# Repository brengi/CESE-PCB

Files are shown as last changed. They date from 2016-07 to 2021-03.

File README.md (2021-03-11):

# DCI- Curso de Diseño de Circuitos Impresos de la Carrera de Especialización en Sistemas Embebidos #

El Curso de Diseño de Circuitos Impresos (DCI) es una asignatura optativa de la Carrera de Especialización en Sistemas Embebidos (CESE) de la Facultad de Ingeniería de la Universidad de Buenos Aires (FIUBA). Tiene una duración de dos meses, organizados en 8 clases semanales de 3 hs cada una. Para aprobar la asignatura los participantes deben realizar el diseño de un circuito impreso a elección durante el curso. En esta página quedan registradas  dichas prácticas.

Más info sobre el curso en las siguiente páginas: 
  * [Contenido y Bibliografía](https://sites.google.com/site/disenodecircuitosimpresoscese/home)
  * [Campus FIUBA](https://campus.fi.uba.ar/enrol/index.php?id=1450])

**ADVERTENCIA**: Estos diseños se realizan en tiempos muy cortos y no todos reciben una revisión funcional detallada. 
El curso enfoca el los procedimientos de diseño de Esquemático y de PCB y no en el diseño funcional de los  circuitos.
El uso de estos circuitos queda bajo la propia responsabilidad del usuario. 

   * [CURSO 2020 B](README_2020B.md#curso-2020-b)
      * [Sistema Monitoreo Alarma de Incendio](README_2020B.md#sistema-monitoreo-alarma-de-incendio)
      * [Réplica dc motor control](README_2020B.md#réplica-dc-motor-control)
      * [Titulador automático](README_2020B.md#titulador-automático)
      * [Board_NFC (Replica sin antena)](README_2020B.md#board_nfc-replica-sin-antena)
      * [Poncho TCP/IP](README_2020B.md#poncho-tcpip)
      * [Replica ESP01 (Mejorada)](README_2020B.md#replica-esp01-mejorada)
      * [Driver motor PAP y ADC](README_2020B.md#driver-motor-pap-y-adc)
      * [Helctec LoRa con cambios](README_2020B.md#helctec-lora-con-cambios)
      * [Réplica pro micro sparkfun (similar)](README_2020B.md#réplica-pro-micro-sparkfun-similar)
      * [Conversor de niveles lógicos](README_2020B.md#conversor-de-niveles-lógicos)
      * [Réplica Sparkfun VS1063](README_2020B.md#réplica-sparkfun-vs1063)
      * [Módulo de velocidad tacométrico](README_2020B.md#módulo-de-velocidad-tacométrico)
      * [Réplica Arduino nano 340g 2016](README_2020B.md#réplica-arduino-nano-340g-2016)
      * [Beacon basado en DWM1001 (Réplica simplificada)](README_2020B.md#beacon-basado-en-dwm1001-réplica-simplificada)
      * [Réplica Pinguino PIC](README_2020B.md#réplica-pinguino-pic)
      * [Réplica detección de obstáculos por infrarrojo](README_2020B.md#réplica-detección-de-obstáculos-por-infrarrojo)
      * [Replica Adafruit HUZZAH32 - ESP32 Feather](README_2020B.md#replica-adafruit-huzzah32---esp32-feather)
      * [Poncho interfaz   arreglo sensores  IR](README_2020B.md#poncho-interfaz--arreglo-sensores--ir)
      * [Programador de microcontroladores](README_2020B.md#programador-de-microcontroladores)

   * [CURSO 2020 A](README_2020A.md#curso-2020-a)
      * [Escáner Magnético de Soldaduras](README_2020A.md#escáner-magnético-de-soldaduras)
      * [Replica Acelerómetro adxl345](README_2020A.md#replica-acelerómetro-adxl345)
      * [Monitor de medidores de energía eléctrica](README_2020A.md#monitor-de-medidores-de-energía-eléctrica)
      * [Réplica  modificada Heltec Wifi LoRA V2](README_2020A.md#réplica--modificada-heltec-wifi-lora-v2)
      * [Réplica Teensy 3.2](README_2020A.md#réplica-teensy-32)
      * [Poncho fotovoltaico](README_2020A.md#poncho-fotovoltaico)
      * [Módem Energy meter](README_2020A.md#módem-energy-meter)
      * [Poncho EDU-CIAA Drivers](README_2020A.md#poncho-edu-ciaa-drivers)

   * [CURSO 6  - 2019](README_2019.md#curso-6----2019)
      * [Punku, control de accesos](README_2019.md#punku-control-de-accesos)
      * [Cargador de batería con protección](README_2019.md#cargador-de-batería-con-protección)
      * [Replica EasyDriver v4.5](README_2019.md#replica-easydriver-v45)
      * [Poncho PLC CIAA 7](README_2019.md#poncho-plc-ciaa-7)
      * [Placa adaptadora de señales de radar](README_2019.md#placa-adaptadora-de-señales-de-radar)
      * [Driver I2C de leds RGB](README_2019.md#driver-i2c-de-leds-rgb)
      * [Encoder &amp; Driver PaP](README_2019.md#encoder--driver-pap)
      * [Dip Coater](README_2019.md#dip-coater)
      * [Driver motor CC](README_2019.md#driver-motor-cc)
      * [Controlador de motor con sensor](README_2019.md#controlador-de-motor-con-sensor)
      * [Placa Bridge Ethernet](README_2019.md#placa-bridge-ethernet)
      * [Fuente Step Up DC-DC ajustable 5v-35v](README_2019.md#fuente-step-up-dc-dc-ajustable-5v-35v)
   * [CURSO 5  - 2019](README_2019.md#curso-5----2019)
      * [Controlador de solenoides realimentado](README_2019.md#controlador-de-solenoides-realimentado)
      * [Módulo ESP8266 - nodeMCU](README_2019.md#módulo-esp8266---nodemcu)
      * [Amplificador biológico educativo](README_2019.md#amplificador-biológico-educativo)
      * [RS485 Port KP995](README_2019.md#rs485-port-kp995)
      * [Sistema de Monitoreo de Material Rodante](README_2019.md#sistema-de-monitoreo-de-material-rodante)
      * [Replica mejorada ESP32 Thing](README_2019.md#replica-mejorada-esp32-thing)
      * [Kit desarrollo para microcontrolador pic16f1939](README_2019.md#kit-desarrollo-para-microcontrolador-pic16f1939)
      * [Placa de desarrollo basado en una FPGA Libre](README_2019.md#placa-de-desarrollo-basado-en-una-fpga-libre)
      * [Poncho adaptador Arduino Mega2560](README_2019.md#poncho-adaptador-arduino-mega2560)
      * [Custom Raspberry Compute Module IO Board](README_2019.md#custom-raspberry-compute-module-io-board)
      * [Réplica TTGO-LORA32-V2.0](README_2019.md#réplica-ttgo-lora32-v20)

   * [CURSO 4  - 2018](README_2018.md#curso-4----2018)
      * [Driver motor pap](README_2018.md#driver-motor-pap)
      * [CIAA-UNO](README_2018.md#ciaa-uno)
      * [Poncho multimedia](README_2018.md#poncho-multimedia)
      * [Puente H doble de 20A](README_2018.md#puente-h-doble-de-20a)
      * [Poncho Alarma](README_2018.md#poncho-alarma)
      * [Réplica del modulo 8 reles de arduino](README_2018.md#réplica-del-modulo-8-reles-de-arduino)
      * [Réplica Acelerometro-mma7361](README_2018.md#réplica-acelerometro-mma7361)
      * [Nodo SisCoCaf](README_2018.md#nodo-siscocaf)
      * [VOIP Shield para Nucleo F767](README_2018.md#voip-shield-para-nucleo-f767)
      * [Poncho CAN](README_2018.md#poncho-can)
      * [Papilio DUO](README_2018.md#papilio-duo)
      * [Detector de sonido arduino](README_2018.md#detector-de-sonido-arduino)
      * [Extension de tarjeta HCAL](README_2018.md#extension-de-tarjeta-hcal)
      * [Contador de pasajeros](README_2018.md#contador-de-pasajeros)
      * [Prototipo Equipo AVL](README_2018.md#prototipo-equipo-avl)
      * [Electrodo Activo para Electromiografía](README_2018.md#electrodo-activo-para-electromiografía)
      * [Replica Placa Madre WEMB01](README_2018.md#replica-placa-madre-wemb01)
      * [Sistema de intercambio de mensajes de voz](README_2018.md#sistema-de-intercambio-de-mensajes-de-voz)
      * [VOP24](README_2018.md#vop24)
      * [PCB para alarma IoT](README_2018.md#pcb-para-alarma-iot)
      * [Modulo TPMS sensor](README_2018.md#modulo-tpms-sensor)
      * [Poncho Procesador de Audio](README_2018.md#poncho-procesador-de-audio)
      * [wifi ESP-01 con relés optoacoplados](README_2018.md#wifi-esp-01-con-relés-optoacoplados)

   * [CURSO 3  - 2017](README_2017.md#curso-3----2017)
      * [Poncho  MIDI](README_2017.md#poncho--midi)
      * [Poncho  Poncho WIFI BLUETOOTH ESP-WROOM-32](README_2017.md#poncho--poncho-wifi-bluetooth-esp-wroom-32)
      * [Poncho  Expansor de Puertos](README_2017.md#poncho--expansor-de-puertos)
      * [Poncho Control de temperatura](README_2017.md#poncho-control-de-temperatura)
      * [Poncho Joystick](README_2017.md#poncho-joystick)
      * [Poncho Medición de pH](README_2017.md#poncho-medición-de-ph)
      * [Poncho  RF](README_2017.md#poncho--rf)
      * [PicoPoncho Lora](README_2017.md#picoponcho-lora)
      * [Poncho Educativo Modelo 2](README_2017.md#poncho-educativo-modelo-2)
      * [Poncho USB-XBEE](README_2017.md#poncho-usb-xbee)
      * [PicoPoncho Bluetooth HC05](README_2017.md#picoponcho-bluetooth-hc05)
      * [Poncho  LCD y Botones](README_2017.md#poncho--lcd-y-botones)

   * [CURSO 2  - 2016](README_2016.md#curso-2----2016)
      * [PicoPoncho WiFi](README_2016.md#picoponcho-wifi)
      * [Poncho  Educativo](README_2016.md#poncho--educativo)
      * [Poncho IoT](README_2016.md#poncho-iot)
      * [Poncho  SAEv2](README_2016.md#poncho--saev2)
      * [Poncho  Puente H por i2C](README_2016.md#poncho--puente-h-por-i2c)
      * [Poncho Oxímetro](README_2016.md#poncho-oxímetro)
      * [Placa Educativa de la materia Electrónica Gral.](README_2016.md#placa-educativa-de-la-materia-electrónica-gral)
      * [Placa de desarrollo para LPC1114](README_2016.md#placa-de-desarrollo-para-lpc1114)
      * [Placa Control Vino](README_2016.md#placa-control-vino)
      * [PMOD Medidor de impedancia para FPGA](README_2016.md#pmod-medidor-de-impedancia-para-fpga)
      * [Poncho EDU-CIAA-NXP RF 2.4GHz Antena PCB](README_2016.md#poncho-edu-ciaa-nxp-rf-24ghz-antena-pcb)
      * [Poncho CNC](README_2016.md#poncho-cnc)
   * [CURSO 1  - 2016](README_2016.md#curso-1----2016)
      * [Poncho Celda de Carga](README_2016.md#poncho-celda-de-carga)
      * [Poncho Osciloscopio](README_2016.md#poncho-osciloscopio)
      * [Poncho Simon](README_2016.md#poncho-simon)
      * [Poncho Audio](README_2016.md#poncho-audio)
      * [Poncho Detector de Caídas](README_2016.md#poncho-detector-de-caídas)
      * [Poncho ECG](README_2016.md#poncho-ecg)
      * [Poncho L298](README_2016.md#poncho-l298)
      * [Poncho Misión SAE](README_2016.md#poncho-misión-sae)
      * [AislacionUSB](README_2016.md#aislacionusb)
      * [Proyecto MICR](README_2016.md#proyecto-micr)
      * [Proyecto Modular Drummer](README_2016.md#proyecto-modular-drummer)

Created by [gh-md-toc](https://github.com/ekalinin/github-markdown-toc)

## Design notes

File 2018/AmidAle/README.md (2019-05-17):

# CESE18_PCB_Amid_Ale
Trabajo final de la asignatura Diseño de PCB de la CESE

** Principales Características:**

1. Salidas a Relay (2)
2. Entradas Optoacopladas (4)
4. (RS232) ESP8266 (1)
5. Display 16x2 (1)

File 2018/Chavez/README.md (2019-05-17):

# PCB
Diseño de PCBs

Replica acelerometro-mma7361

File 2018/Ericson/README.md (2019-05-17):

# Rev 1.0

Primera entrega para revision.

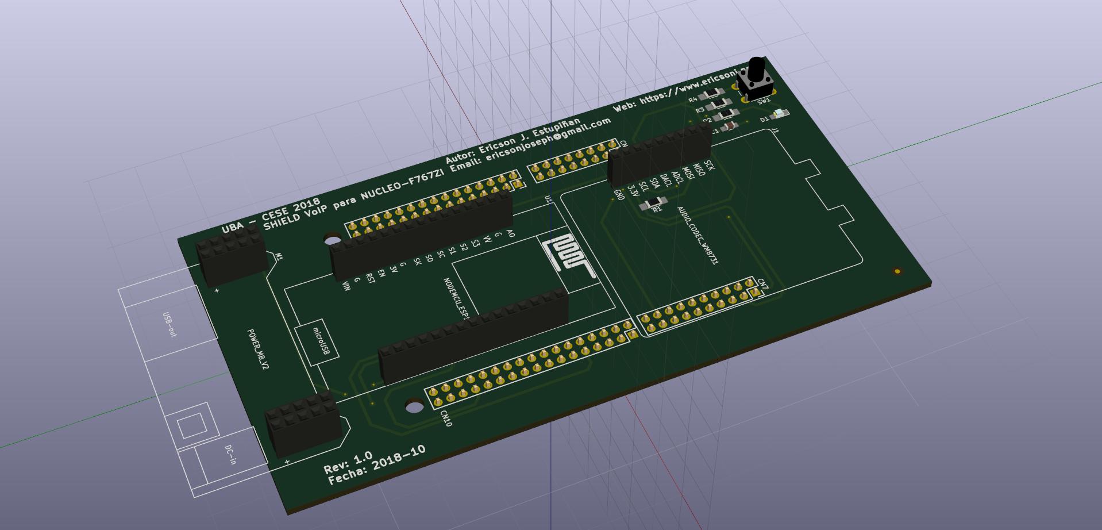
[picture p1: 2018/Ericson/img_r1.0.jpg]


# Progreso

## Imagen 1
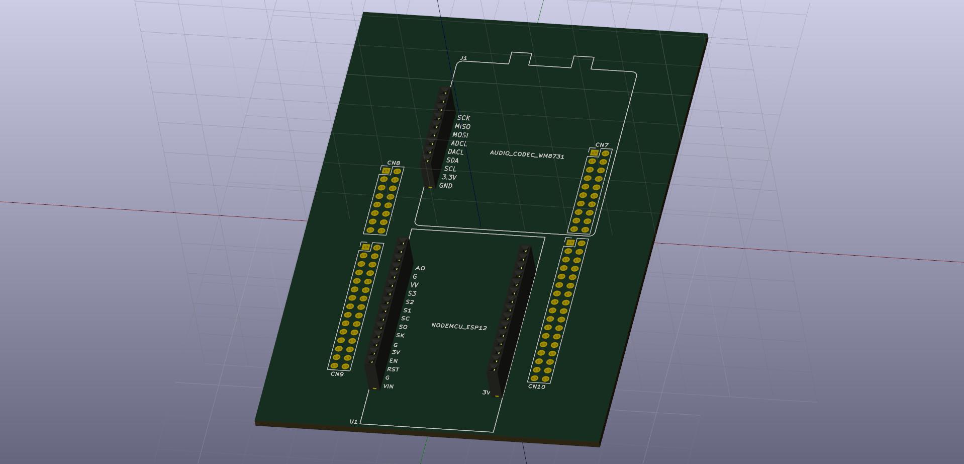
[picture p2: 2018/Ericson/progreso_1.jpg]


## Imagen 2
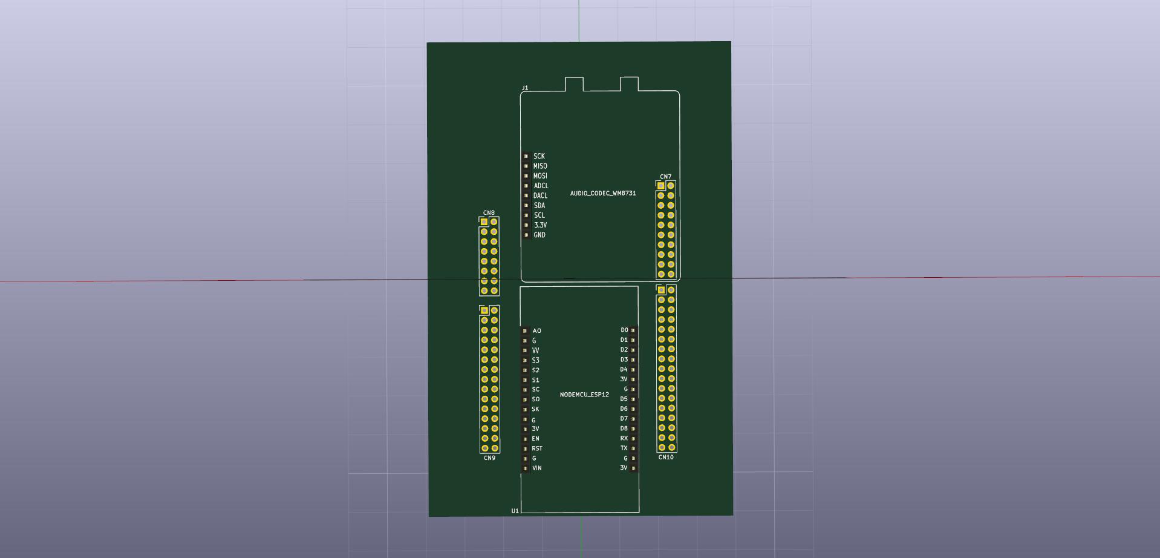
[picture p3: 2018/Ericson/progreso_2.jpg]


# CESE2018-PCB-TP
CESE 2018 Diseño de Circuitos Impresos,

Repositorio del trabajo final del curso de Diseño de Circuitos Impresos 
de la carrera Especializacion en Sistemas embebidos. 

## Introduccion 

El siguiente proyecto busca ser un adicional al trabajo final de la carrera de especialización en sistemas embebidos
"Diseño e implementación de un sistema de comunicación VoIP usando una plataforma ARM Cortex M7**. El proyecto propone el diseño de un sheild compatible con los conectores Arduino UNO y que conecte e integra los módulos necesarios para el desarrollo del proyecto final de carrera. Estos módulos son: 

1.  AUDIO CODEC WM8731.
2.  ESP-12. 
3.  Fuente DC. 

## Objetivos

*  Diseñar un circuito impreso en Kicad que conecte los diferentes modulos de forma apropiada.

## Alcances

*  Diseño de circuito impreso.

## Posibles alcances

*  Manufactura del cicuito impreso.

## Plan de trabajo

1.  Diseño de plataforma que por medio de conectores integra en una misma placa cada modulo.
2.  Primera versión del diseño de la PCB.
3.  **Búsqueda de esquemático de modulo NODE MCU para extraer ESP-12 e integrarlo en el diseño del circuito.
4.  **Segunda versión del diseño de la PCB.
5.  **Búsqueda de esquemático de Fuente DC para integración en el circuito impreso.
6.  **Tercera versión del diseño de la PCB.
7.  **Búsqueda de esquemático de AUDIO CODEC WM8131 para integración en el circuito impreso.
8.  **Cuarta versión del diseño de la PCB.

**Posibles versiones del proyecto si alcanza el tiempo estimado. 

## Prototipo



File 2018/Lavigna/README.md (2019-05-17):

# CESE-2018-disenio-pcb-gonzalo-lavigna
Repositorio de la materia de Diseño de PCB de Gonzalo Lavigna CESE 2018

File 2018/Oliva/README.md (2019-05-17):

# CESE2018_6Co_DPCBs
TRABAJOS MATERIA DISEÑO DE PCBs - CESE 2018 DE R.OLIVA

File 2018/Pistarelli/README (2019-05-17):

El PCB ha sido desarrollado en el marco de la realización del prototipo funcional de proyecto:

https://docs.google.com/document/d/1OangFb6ORAsVZ08jJLUIxbCAcYfww7F53GZTul6QJPM/edit?usp=sharing

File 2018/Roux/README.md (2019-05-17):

# VOP24_LPCXpresso1769_baseHW #

### autor: Ing. Roux Federico G. (rouxfederico@gmail.com) ###

Desarrollo en KICAD del hardware base para LPCXpresso1769 con los componentes básicos:

	- regulación de tensión digital y analógica.
	- ads1292
	- slot microSD
	- salida serie para BT
	- medición de batería

## Historial ##

27.06.2018:

	- Creación del repositorio
    - se inicio el esquematico con dos reg mc1702, micro sd y medicion de bateria con lm358
    ...
    - se agrego simbolo del lpcxpresso1769
    - falta acomodar los directorios de las librerias
    - falta ads1292, simbolo y footprint
    - falta footprint lpcxpresso1769

29.06.2018:

    - conexiones con la SD y lpc1796
    - falta ads1292, simbolo y footprint
    - falta footprint lpcxpresso1769

30.06.2018:

    - se agrego simbolo ads1292 al esquematico
    - falta terminar las conexiones del ads
    - conviene separar en modulos jerarq. -> VER COMO SE HACE

PENDIENTES:

- ver modelo del diodo schottky del L4411
- ver footprint del micro USB B - ver con lo q consiga
- definir inductor acoplado - HECHO
- intercambiar pines TPD_EN y USB_ID para que quede para rutear directo

02/11/2018 :

   - intercambiado pines TPD_EN y USB_ID para que quede para rutear directo
   - cambio de footprint de J303 y J302 por tira de pines de 2.54mm

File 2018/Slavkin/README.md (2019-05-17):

# cese_kicad
tp para cese sobre kicad

Autor: Pablo Slavkin
CESE2018

Driver motores paso a paso
===========================

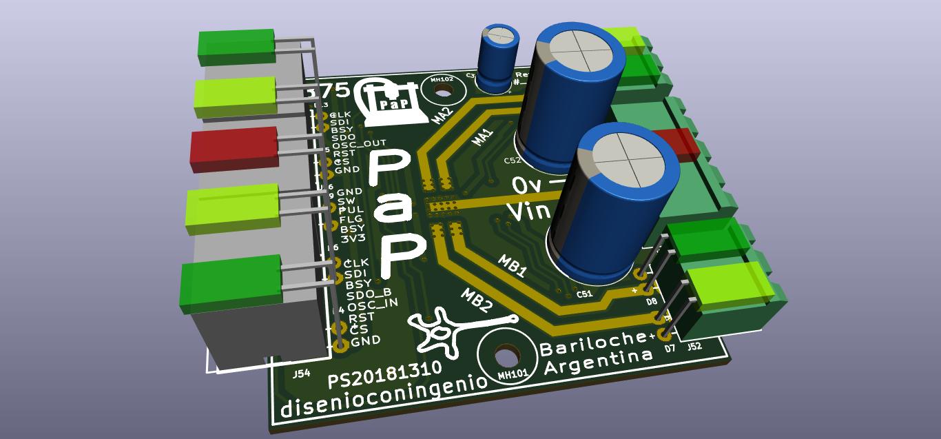
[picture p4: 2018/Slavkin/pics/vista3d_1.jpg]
Vista 3d


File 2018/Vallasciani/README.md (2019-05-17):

# CESE-6Co2018_PCB
Poncho Procesador de Audio

El Poncho "Procesador de Audio" es una placa de circuito impreso que se diseño para ser montada sobre la EDU-CIAA-NXP. Dicho pcb le brinda a la EDU-CIAA-NXP el hardware necesario para adquirir audio en modo estereo o en modo mono estereo, y además, el hardware necesario para generar el audio procesado en modo stereo o mono stereo. A su vez, se agrega hardware indicador de estado para el usuario y se agregan protecciones contra el mal uso del equipo.

Para la generación de audio el poncho posee un DAC PCM5100 para la generación de audio estéreo con un pin de Mute para poder controlar el encendido y apagado de la salida mediante un pin del lpc4337. Además, posee mapeado a la salida el DAC de salida de la EDU-CIAA-NXP para poder generar una salida mono stereo.

Para la adquisición de audio el poncho posee accesibles los canales 1 y 2 del ADC de la EDU-CIAA-NXP mediante el hardware pertinente para realizar el ajuste de niveles de entrada. Este incluye el agregado de un nivel de continua a la señal de audio adquirida, un ajuste de volumen y las protecciones pertinentes para la entrada del ADC. 

Se deja una bornera para acceder al I2C y UART del LPC4337.

A su vez, el pcb posee hardware para poder trabajar en modo monoestereo. Este, suma un nivel de continua, canal derecho y canal izquierdo mediante un amplificador operacional. 

Para las entradas y salidas de audio se utilizarán conectores miniplug de 3.5mm(4 en total).

Por último, se incluirán 3 leds para usar a modo de indicación de nivel de entrada.

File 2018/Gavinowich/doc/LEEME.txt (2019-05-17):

TITULO PONCHO
=============

URL: No disponible
FUNCIÓN: El poncho_CAN agrega la interfaz física para conectarse a una red CAN de alta velocidad
AUTORES/INSTITUCIONES: Gabriel Gavinowich

<<Detalle y explicación de directorios o archivos adicionales que se incorporen.>>
Se agrega una carpeta con las hojas de datos de los componentes utilizados en el poncho

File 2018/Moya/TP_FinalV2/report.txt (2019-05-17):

Información: Comprobando la huella del símbolo de la red "C1:/5BD8DE0B:Capacitor_SMD:C_1206_3216Metric_Pad1.42x1.75mm_HandSolder".

Información: Comprobando la huella del símbolo de la red "U1:/5BD8FB55:OPA4243:OPA4243EA&slash_250".

Información: Comprobando la huella del símbolo de la red "C2:/5BE1D0DF:Capacitor_SMD:C_1206_3216Metric_Pad1.42x1.75mm_HandSolder".

Información: Comprobando la huella del símbolo de la red "R3:/5BD8DDE8:Resistor_SMD:R_0603_1608Metric_Pad1.05x0.95mm_HandSolder".

Información: Comprobando la huella del símbolo de la red "C3:/5BD8DDEF:Capacitor_SMD:C_1206_3216Metric_Pad1.42x1.75mm_HandSolder".

Información: Comprobando la huella del símbolo de la red "R2:/5BD8DDF6:Resistor_SMD:R_0603_1608Metric_Pad1.05x0.95mm_HandSolder".

Información: Comprobando la huella del símbolo de la red "R1:/5BD8DDFD:Resistor_SMD:R_0603_1608Metric_Pad1.05x0.95mm_HandSolder".

Cambiando de la huella "R3:/5BD8DDE8" el nombre de la red del pad "2" de "" a "/Vo-".

Cambiando de la huella "U1:/5BD8FB55" el nombre de la red del pad "14" de "" a "Net-(C2-Pad1)".

Añadiendo del nuevo símbolo "U1:/5BD8FB55" la huella "OPA4243:OPA4243EA&slash_250".

Cambiando de la huella "U1:/5BD8FB55" el nombre de la red del pad "1" de "" a "Net-(R1-Pad2)".

Cambiando de la huella "U1:/5BD8FB55" el nombre de la red del pad "2" de "" a "Net-(R1-Pad2)".

Cambiando de la huella "U1:/5BD8FB55" el nombre de la red del pad "3" de "" a "/Va".

Cambiando de la huella "U1:/5BD8FB55" el nombre de la red del pad "4" de "" a "VCC".

Cambiando de la huella "U1:/5BD8FB55" el nombre de la red del pad "5" de "" a "/Vb".

Cambiando de la huella "U1:/5BD8FB55" el nombre de la red del pad "6" de "" a "/Vo+".

Cambiando de la huella "U1:/5BD8FB55" el nombre de la red del pad "7" de "" a "/Vo+".

Cambiando de la huella "U1:/5BD8FB55" el nombre de la red del pad "8" de "" a "/Vo-".

Cambiando de la huella "U1:/5BD8FB55" el nombre de la red del pad "9" de "" a "Net-(C1-Pad1)".

Cambiando de la huella "U1:/5BD8FB55" el nombre de la red del pad "10" de "" a "/Vo+".

Cambiando de la huella "U1:/5BD8FB55" el nombre de la red del pad "11" de "" a "GND".

Cambiando de la huella "U1:/5BD8FB55" el nombre de la red del pad "12" de "" a "/Vc".

Cambiando de la huella "U1:/5BD8FB55" el nombre de la red del pad "13" de "" a "Net-(C2-Pad1)".

Cambiando de la huella "C3:/5BD8DDEF" el nombre de la red del pad "2" de "" a "/Vo-".

Añadiendo del nuevo símbolo "C1:/5BD8DE0B" la huella "Capacitor_SMD:C_1206_3216Metric_Pad1.42x1.75mm_HandSolder".

Cambiando de la huella "C1:/5BD8DE0B" el nombre de la red del pad "2" de "" a "Net-(C1-Pad2)".

Cambiando de la huella "C1:/5BD8DE0B" el nombre de la red del pad "1" de "" a "Net-(C1-Pad1)".

Añadiendo del nuevo símbolo "C2:/5BE1D0DF" la huella "Capacitor_SMD:C_1206_3216Metric_Pad1.42x1.75mm_HandSolder".

Cambiando de la huella "C2:/5BE1D0DF" el nombre de la red del pad "1" de "" a "Net-(C2-Pad1)".

Cambiando de la huella "C2:/5BE1D0DF" el nombre de la red del pad "2" de "" a "Net-(C2-Pad2)".

Añadiendo del nuevo símbolo "C3:/5BD8DDEF" la huella "Capacitor_SMD:C_1206_3216Metric_Pad1.42x1.75mm_HandSolder".

Cambiando de la huella "C3:/5BD8DDEF" el nombre de la red del pad "1" de "" a "Net-(C1-Pad1)".

Cambiando de la huella "R3:/5BD8DDE8" el nombre de la red del pad "1" de "" a "Net-(C1-Pad1)".

Añadiendo del nuevo símbolo "R1:/5BD8DDFD" la huella "Resistor_SMD:R_0603_1608Metric_Pad1.05x0.95mm_HandSolder".

Cambiando de la huella "R1:/5BD8DDFD" el nombre de la red del pad "1" de "" a "Net-(C1-Pad2)".

Cambiando de la huella "R1:/5BD8DDFD" el nombre de la red del pad "2" de "" a "Net-(R1-Pad2)".

Añadiendo del nuevo símbolo "R2:/5BD8DDF6" la huella "Resistor_SMD:R_0603_1608Metric_Pad1.05x0.95mm_HandSolder".

Cambiando de la huella "R2:/5BD8DDF6" el nombre de la red del pad "2" de "" a "Net-(C2-Pad2)".

Cambiando de la huella "R2:/5BD8DDF6" el nombre de la red del pad "1" de "" a "Net-(C1-Pad1)".

Añadiendo del nuevo símbolo "R3:/5BD8DDE8" la huella "Resistor_SMD:R_0603_1608Metric_Pad1.05x0.95mm_HandSolder".

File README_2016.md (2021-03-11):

<!--ts-->
   * [CURSO 2  - 2016](#curso-2----2016)
      * [PicoPoncho WiFi](#picoponcho-wifi)
      * [Poncho  Educativo](#poncho--educativo)
      * [Poncho IoT](#poncho-iot)
      * [Poncho  SAEv2](#poncho--saev2)
      * [Poncho  Puente H por i2C](#poncho--puente-h-por-i2c)
      * [Poncho Oxímetro](#poncho-oxímetro)
      * [Placa Educativa de la materia Electrónica Gral.](#placa-educativa-de-la-materia-electrónica-gral)
      * [Placa de desarrollo para LPC1114](#placa-de-desarrollo-para-lpc1114)
      * [Placa Control Vino](#placa-control-vino)
      * [PMOD Medidor de impedancia para FPGA](#pmod-medidor-de-impedancia-para-fpga)
      * [Poncho EDU-CIAA-NXP RF 2.4GHz Antena PCB](#poncho-edu-ciaa-nxp-rf-24ghz-antena-pcb)
      * [Poncho CNC](#poncho-cnc)
   * [CURSO 1  - 2016](#curso-1----2016)
      * [Poncho Celda de Carga](#poncho-celda-de-carga)
      * [Poncho Osciloscopio](#poncho-osciloscopio)
      * [Poncho Simon](#poncho-simon)
      * [Poncho Audio](#poncho-audio)
      * [Poncho Detector de Caídas](#poncho-detector-de-caídas)
      * [Poncho ECG](#poncho-ecg)
      * [Poncho L298](#poncho-l298)
      * [Poncho Misión SAE](#poncho-misión-sae)
      * [AislacionUSB](#aislacionusb)
      * [Proyecto MICR](#proyecto-micr)
      * [Proyecto Modular Drummer](#proyecto-modular-drummer)

<!-- Added by: diego, at: jue mar 11 11:39:27 -03 2021 -->

<!--te-->

# CURSO 2  - 2016 #
Curso de Diseño de Circuitos Impresos de la Carrera de Especialización en Sistemas Embebidos.

**ADVERTENCIA**: Estos circuitos se realizan en tiempos muy cortos y no todos los circuitos reciben una revisión funcional detallada. 
El curso enfoca el los procedimientos de diseño de Esquemático y de PCB y no en el diseño funcional de los  circuitos.
El uso de estos circuitos queda bajo la propia responsabilidad del usuario.

## PicoPoncho WiFi  ##
  * Autor: De Jesús Meleán Sergio Renato.
  * Curso: 14 de Octubre al 2 Diciembre de 2016.
  * Descripción: Se trata de una placa sencilla para la picoCIAA (picoPoncho) que contiene un módulo wifi ESP8266, conectores para la asociación a la picociaa y elementos de manejo del ESP.
  * URL PONCHO: https://github.com/ciaa/Ponchos/
  * URL Original: https://github.com/sergiordj/Poncho_wifi_picociaa

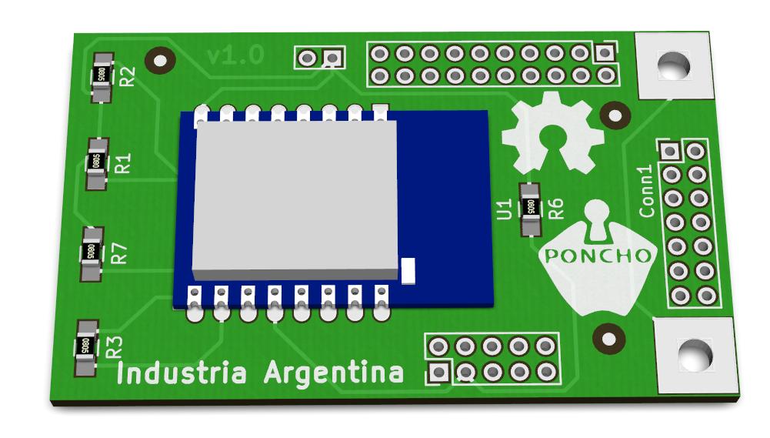
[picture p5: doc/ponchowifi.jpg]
Vista 3D Pico Poncho Wifi


## Poncho  Educativo ##
  * Autor: Evangelista Guillermo Oscar.
  * Curso: 14 de Octubre al 2 Diciembre de 2016.
  * Descripción: Este poncho tiene una  variedad de componentes para realizar ensayos variados y poder aplicar los conceptos aprendidos en la carrera. Implementa entradas Analógicas, salidas PWM, salidas a relé y  entradas optoacopladas.
  * URL PONCHO: https://github.com/ciaa/Ponchos/
  * URL Original: https://github.com/guille411/EduPoncho

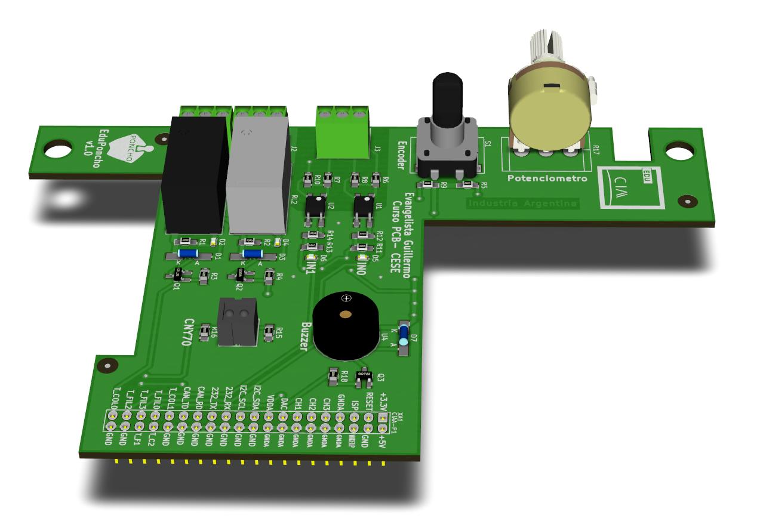
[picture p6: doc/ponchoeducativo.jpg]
Vista 3D Poncho Educativo


## Poncho IoT ##
  * Autor: Gigliotti Ernesto.
  * Curso: 14 de Octubre al 2 Diciembre de 2016.
  * Descripción: Es una placa que sea capaz de conectarse a la EDU-CIAA-NXP y que provea por medio del módulo WiFi RN1810 de microchip conectividad inalámbrica a la placa. Este módulo se conecta por medio del puerto serie de la EDU-CIAA-NXP.
  * URL PONCHO: https://github.com/ciaa/Ponchos/
  * URL Original: https://github.com/ernesto-g/ponchoeduciaaiot.git

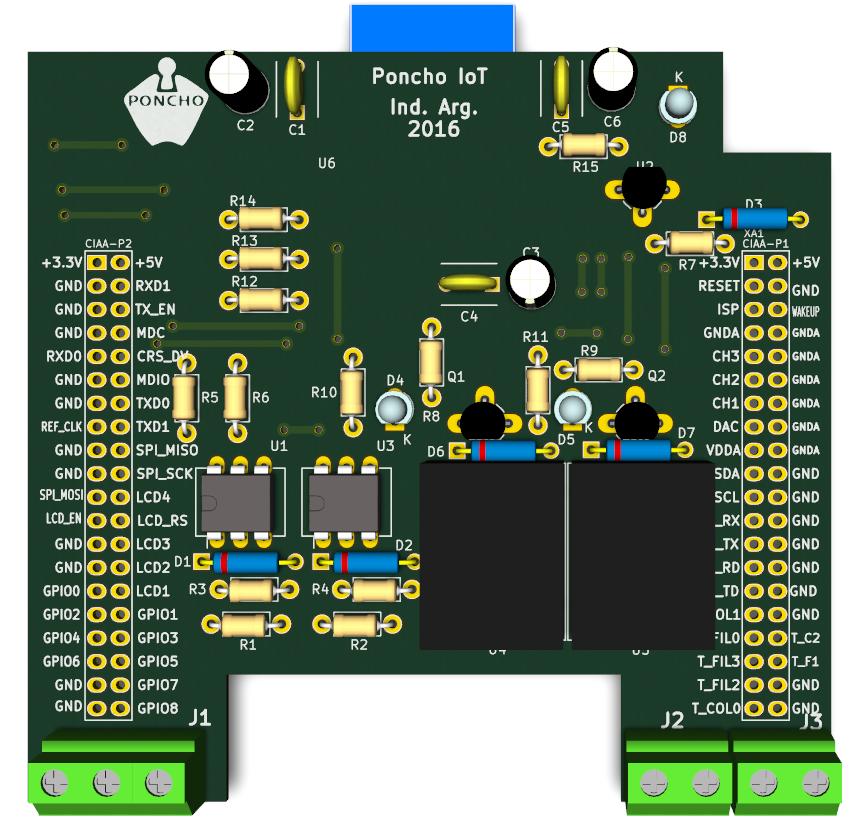
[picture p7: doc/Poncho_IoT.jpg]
Vista 3D Poncho IoT


## Poncho  SAEv2 ##
  * Autor: Iglesias Julian.
  * Curso: 14 de Octubre al 2 Diciembre de 2016.
  * Descripción: El Poncho misión SAE "Ingeniería Satelital en la Escuela" es una reimplementación en Kicad del Poncho utilizado para la actividad mencionada. Más información sobre el tema en http://www.suremptec.com/es/noticias-y-eventos/127-exitoso-cierre-de-la-primera-edicion-de-la-mision-sae.html . El Poncho posee un módulo ZigBee, un sensor de presión y un módulo acelerómetro.
  * URL PONCHO: https://github.com/ciaa/Ponchos/
  * URL Original: https://gitlab.com/julianmiglesias/MisionSAE

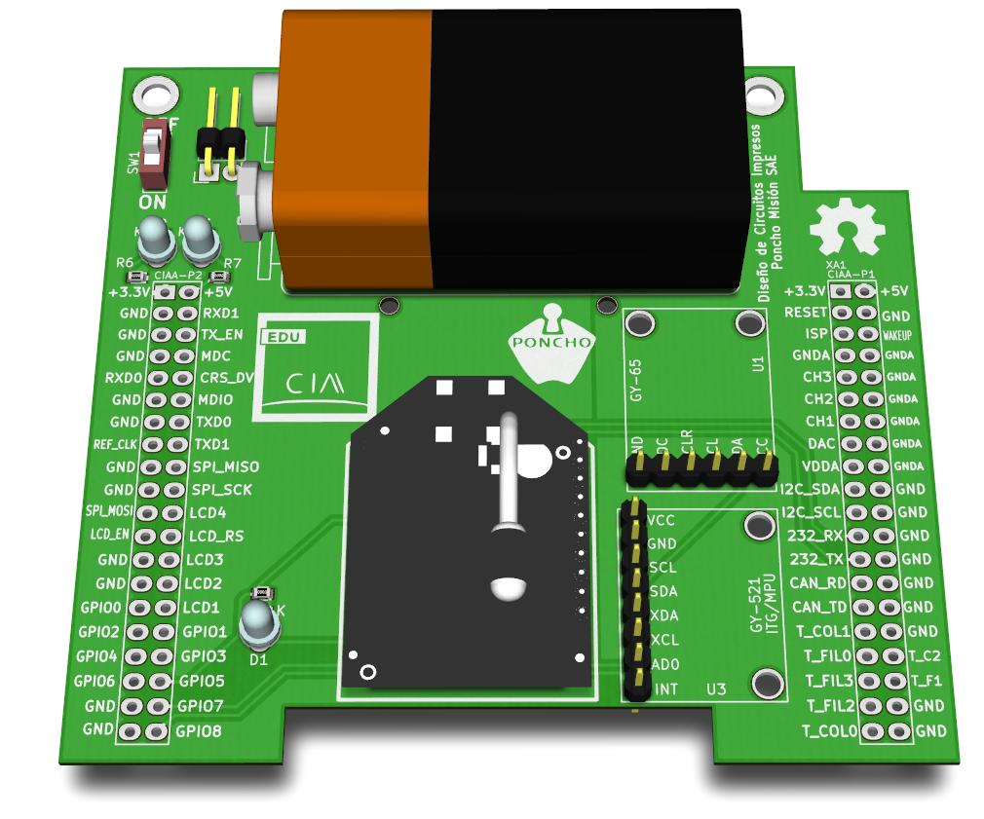
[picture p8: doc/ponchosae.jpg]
Vista 3D Poncho SAEv2


## Poncho  Puente H por i2C ##
  * Autor: Martinez Horacio.
  * Curso: 14 de Octubre al 2 Diciembre de 2016.
  * Descripción: Este circuito implementa un controlador para dos motores paso a paso o cuatro motores DC de baja potencia. Podra usarse con la EDU-CIAA con una fuente de alimentacion externa.
  * URL PONCHO: https://github.com/ciaa/Ponchos/
  * URL Original:  https://github.com/martinezhoracio/tp_KiCad_2016

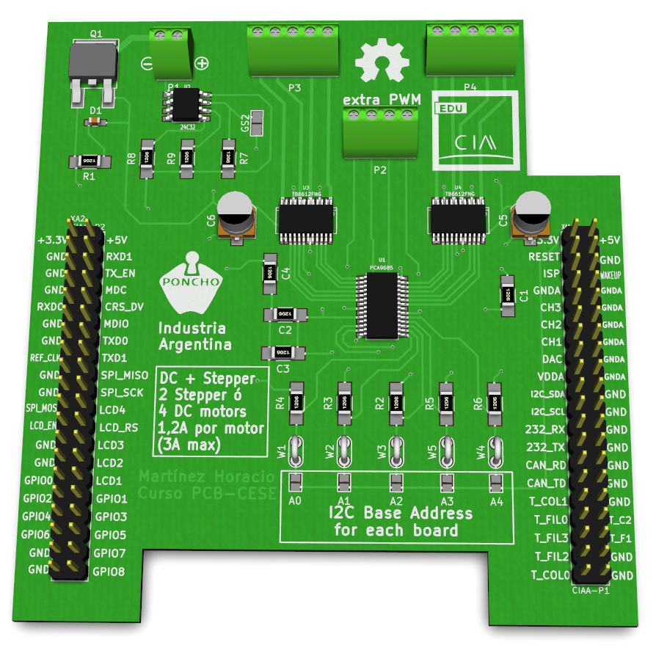
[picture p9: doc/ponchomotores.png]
Vista 3D Poncho puente H por i2C


## Poncho Oxímetro ##
  * Autor: Meira Fernando.
  * Curso: 14 de Octubre al 2 Diciembre de 2016.
  * Descripción: La función del poncho es implementar un oximetro de pulso basado en el integrado AFE4490 de Texas Instruments y usando como configuración del sensor el estándar introducido por Nellcor.
  * URL PONCHO: https://github.com/ciaa/Ponchos/
  * URL Original: https://github.com/Fermeira/Oximetro_CESE.git

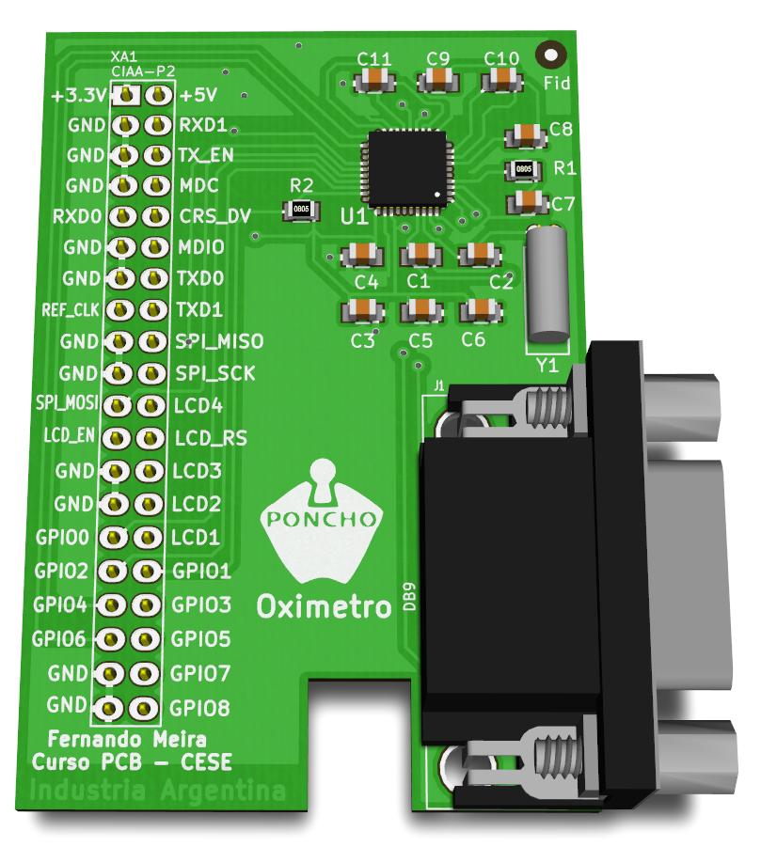
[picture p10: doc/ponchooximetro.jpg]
Vista 3D Poncho Oxímetro


## Placa Educativa de la materia Electrónica Gral. ##
  * Autor: Alonso Ramiro.
  * Curso: 14 de Octubre al 2 Diciembre de 2016.
  * Descripción: Este es un circuito didáctico para fomentar el interés de los alumnos de Electrónica General en la materia. Permite demostrar el funcionamiento de los circuitos que hasta ahora ven en papel. Está dividido en bloques correspondientes con las prácticas de la materia.
  * URL Original:  https://github.com/ninjaramiro/TP_FINAL_KICAD

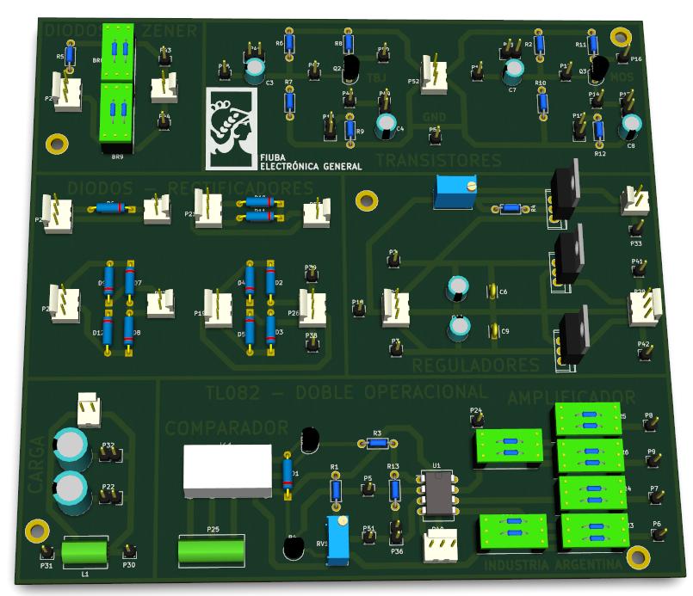
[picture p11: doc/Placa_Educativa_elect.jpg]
Vista 3D Placa educativa para electrónica general


## Placa de desarrollo para LPC1114 ##
  * Autor: Carducci Leonardo.
  * Curso: 14 de Octubre al 2 Diciembre de 2016.
  * Descripción: Es una placa de desarrollo básica, para aplicaciones de baja complejidad, que consta de un microcontrolador LPC1114, conectores para proposito general, un LED, conector JTAG, contector para alimentación externa, fuente regulada a 3,3 V, un conversor USB-UART mediante el circuito FT232RL y un conector micro-USB hembra.
  * URL Original: https://gitlab.com/carducci/KICAD-LMC.git

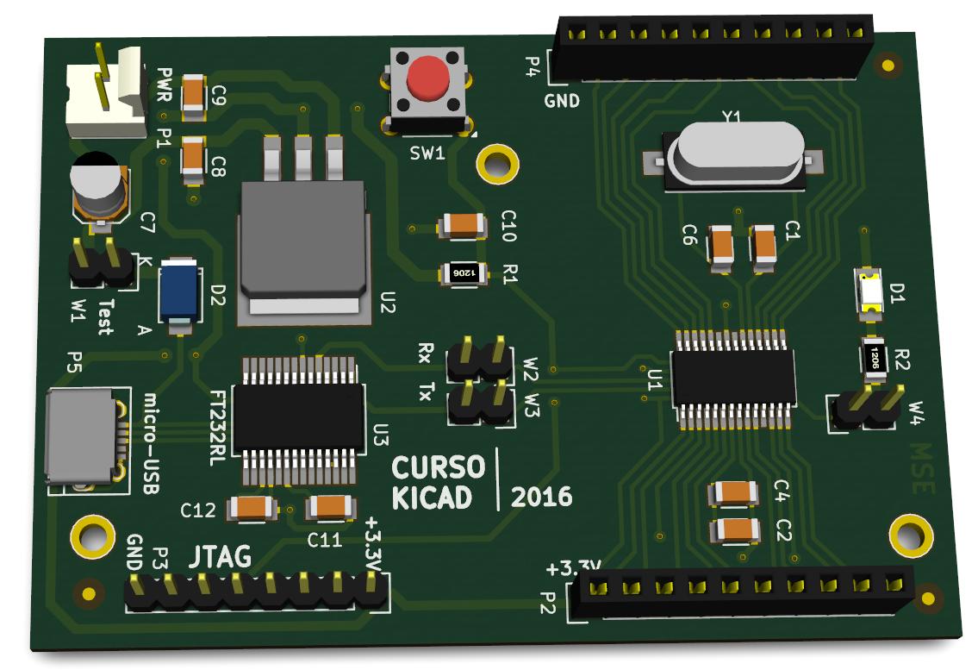
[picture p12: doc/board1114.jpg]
Vista 3D Placa LPC1114


## Placa Control Vino  ##
  * Autor: Chico Luis.
  * Curso: 14 de Octubre al 2 Diciembre de 2016.
  * Descripción: Es una placa relacionada al control del proceso del vino.
  * URL Original: https://github.com/lchico/chz_hw_tp_vino

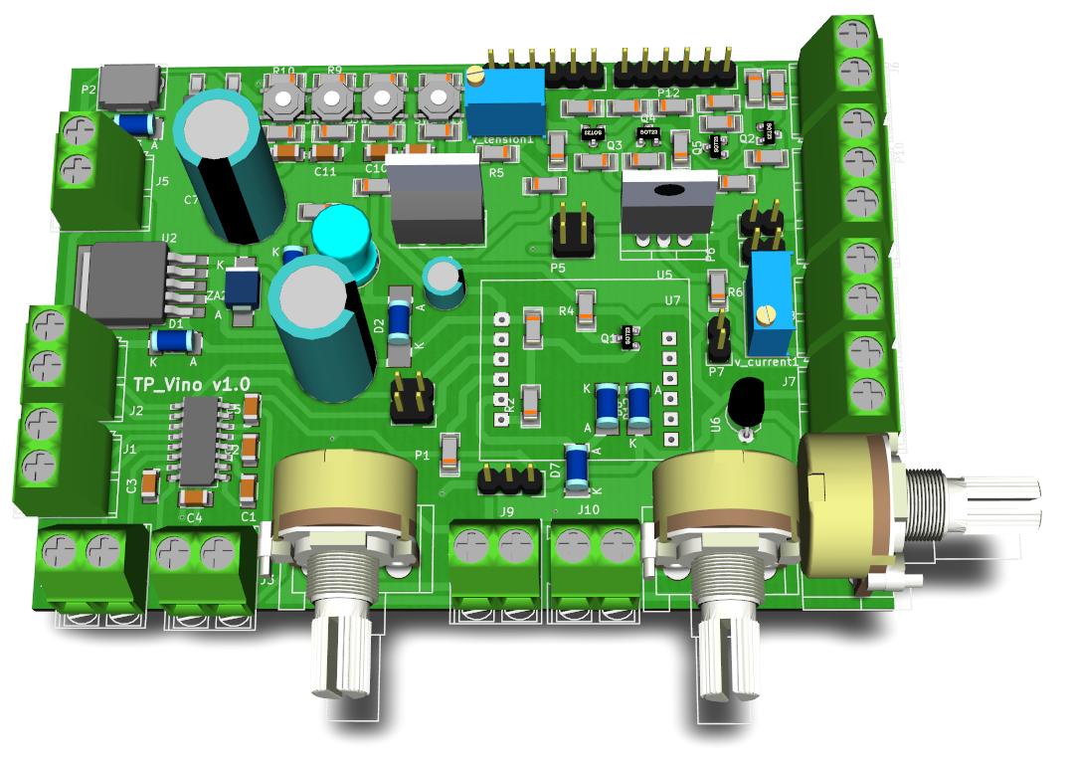
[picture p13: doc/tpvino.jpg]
Vista 3D Placa control vino


## PMOD Medidor de impedancia para FPGA ##
  * Autor: Larosa Facundo.
  * Curso: 14 de Octubre al 2 Diciembre de 2016.
  * Descripción: El proyecto consiste de un analizador de impedancias, el cual inyecta una señal de hasta 100 kHz y permite obtener la parte real e imaginaria para cada frecuencia del dipolo en cuestión. El circuito se conecta con la FPGA por medio del protocolo I2C.
  * URL Original: https://github.com/facundolarosa/proyectoDCI.git

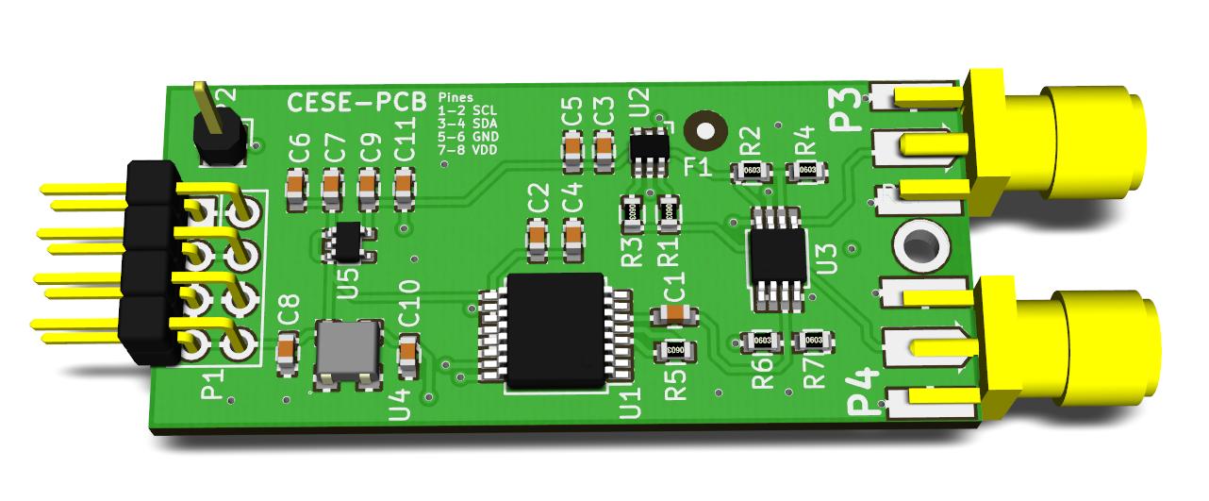
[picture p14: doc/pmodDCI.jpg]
Vista 3D Medido de impedancias PMOD


## Poncho EDU-CIAA-NXP RF 2.4GHz Antena PCB ##
  * Autor: Juan Vicente Montilla Cabrera.
  * Curso: 14 de Octubre al 2 Diciembre de 2016.
  * Descripción: Este circuito de poncho implementa una unidad de radio que opera en la banda de frecuencias abierta de 2.4GHz y compila con aplicaciones de la EDU-CIAA NXP que soportan el estándar IEEE 802.15.4: IEEE Standards Association. IEEE Standard for Local and metropolitan area networks–Part 15.4: Low-Rate Wireless Personal Area Networks (LR-WPANs) y ZIGBEE.
  * URL PONCHO: https://github.com/ciaa/Ponchos/
  * URL Original: https://github.com/Juanvmont/Poncho-EDU-CIAA-NXP-RF-2.4GHz-Antena-PCB.git

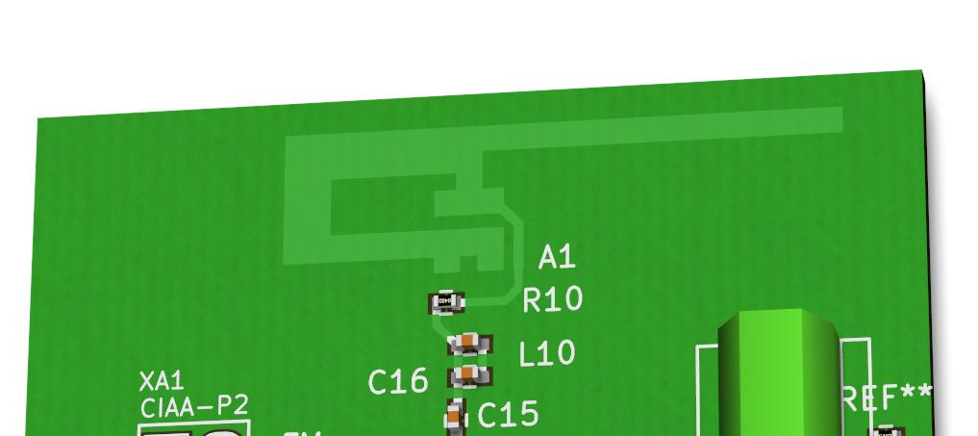
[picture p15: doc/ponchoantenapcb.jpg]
Vista 3D Antena PCB


## Poncho CNC ##
  * Autor: Moreno Marin Marcelo Franz .
  * Curso: 14 de Octubre al 2 Diciembre de 2016.
  * Descripción: Poncho para EDU-CIAA-NXP para el control de una CNC de 3 ejes con motores paso a paso controlados por la placa Pololu a4988 y un regulador switching LM2596 de voltaje (12V - 36V) DC-DC (3.3V) para alimentar el controlador aprovechando la alimentacion de los motores.
  * URL PONCHO: https://github.com/ciaa/Ponchos/
  * URL Original: https://github.com/mmarcelofrm/Poncho-CNC

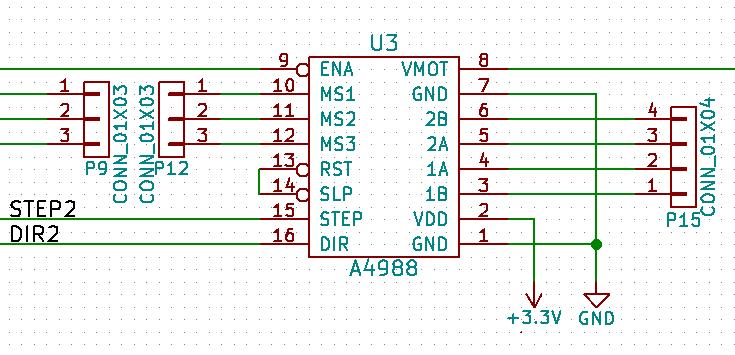
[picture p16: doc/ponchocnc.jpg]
Vista 3D Poncho CNC


# CURSO 1  - 2016 #

## Poncho Celda de Carga ##
  * Autor: Rey Hernandez Hernán Felipe.
  * Curso: 7 de Junio al 26 de Julio de 2016.
  * Descripción: Poncho para conectar una celda de carga, se amplifica la señal, se hace una 
conversión con un A/D externo y se ingresa a la EDU-CIAA por I2C.
  * URL PONCHO: https://github.com/ciaa/Ponchos/tree/master/Celda_de_carga
  * URL Original: https://github.com/feliperey4/LoadCellShield

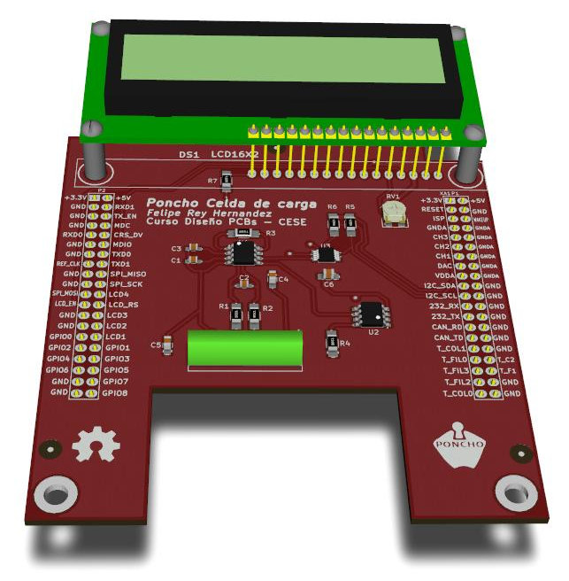
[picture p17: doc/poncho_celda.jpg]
Vista 3D LoadCellShield


## Poncho Osciloscopio ##
  * Autor: Nicolás Dassieu Blanchet.
  * Curso: 7 de Junio al 26 de Julio de 2016.
  * Descripción: Poncho que implementa un osciloscopio básico con selección de atenuación, DC/AC, nivel de disparo y un display para mostrar la señal capturada.
  * URL PONCHO: https://github.com/ciaa/Ponchos/tree/master/Osciloscopio

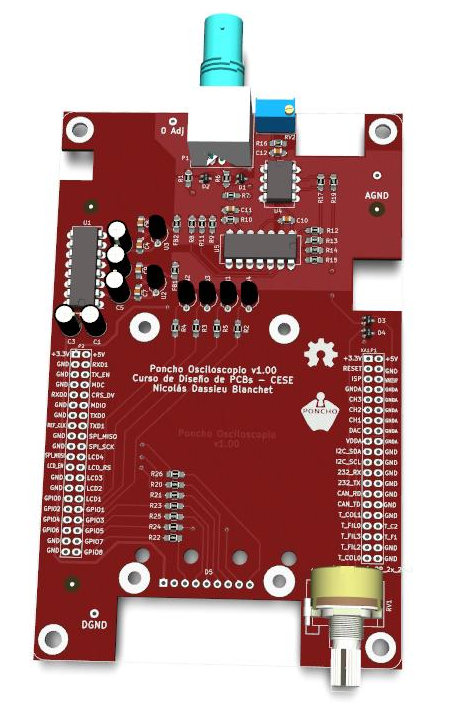
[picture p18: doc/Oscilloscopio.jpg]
Vista 3D Poncho Osciloscopio


## Poncho Simon ##
  * Autor: Bassi Juan Agustín.
  * Curso: 7 de Junio al 26 de Julio de 2016.
  * Descripción: Poncho para implementar el clásico juego del Simon, con pulsadores, LEDs de colores y buzzer.
  * URL PONCHO: https://github.com/ciaa/Ponchos/tree/master/Simon
  * URL Original: https://gitlab.com/abassi/ponchoSimon

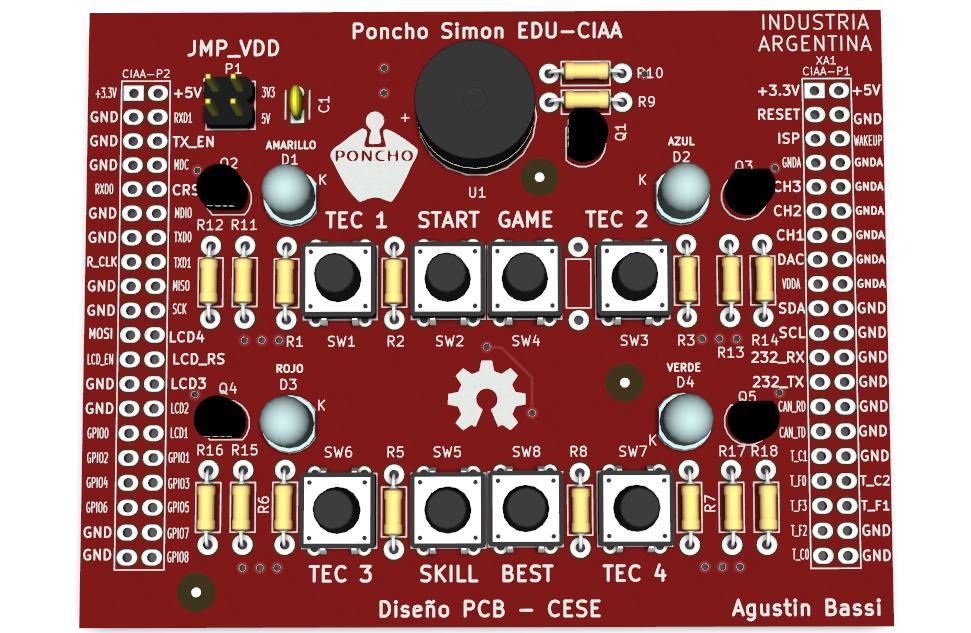
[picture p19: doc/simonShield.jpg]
Vista 3D Poncho Simon


## Poncho Audio ##
  * Autor: Giovagnoli Valentin.
  * Curso: 7 de Junio al 26 de Julio de 2016.
  * Descripción: Poncho con entrada de micrófono y salida de audio conectados al ADC y al DAC respectivamente.
  * URL PONCHO: https://github.com/ciaa/Ponchos/tree/master/Audio_amp_mic
  * URL Original: https://gitlab.com/valentingiova/Poncho_EDU_CIAA_Amp_Audio

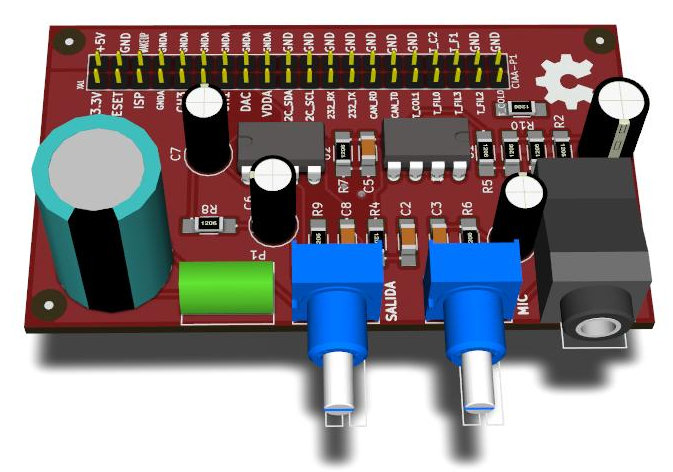
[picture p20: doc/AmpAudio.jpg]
Vista 3D Poncho Audio


## Poncho Detector de Caídas ##
  * Autor: Dell ´Oso Matías.
  * Curso: 7 de Junio al 26 de Julio de 2016.
  * Descripción: Poncho que permite conectar módulos con acelerómetro, wifi, GSM. Implementa una fuente a batería de 9V con la cual se alimenta el circuito y puede alimentar la EDU-CIAA. Posee además tres leds, un buzzer y se puede leer la tensión de batería con el A/D de la EDU-CIAA.
  * URL PONCHO: https://github.com/ciaa/Ponchos/tree/master/Detector_de_caidas
  * URL Original: https://github.com/mdelloso/fall_detector

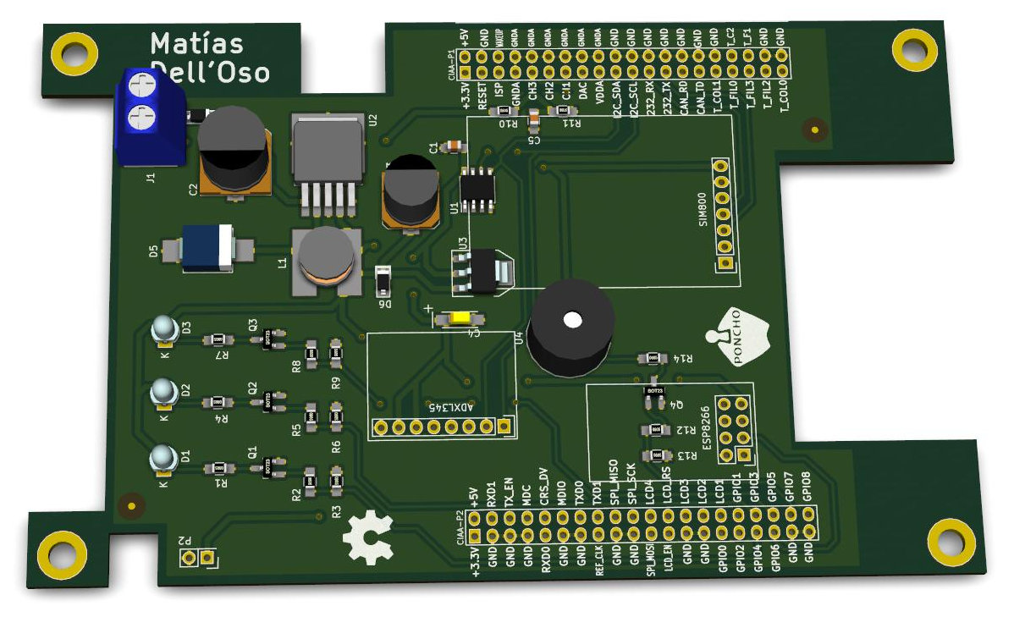
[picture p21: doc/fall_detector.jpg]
Vista 3D Poncho Caídas


## Poncho ECG ##
  * Autor: Jorge Fonseca.
  * Curso: 7 de Junio al 26 de Julio de 2016.
  * Descripción: El Poncho ECG permite monitorear frecuencia cardíaca utiliza el integrado AD8232. La señal procesada ingresa por el conversor A/D de la EDU-CIAA. Este circuito se basa en el diseño de Sparkfun.
  * URL PONCHO: https://github.com/ciaa/Ponchos/tree/master/ECG
  * URL Original: https://github.com/jorgef34/ECG-CIAA

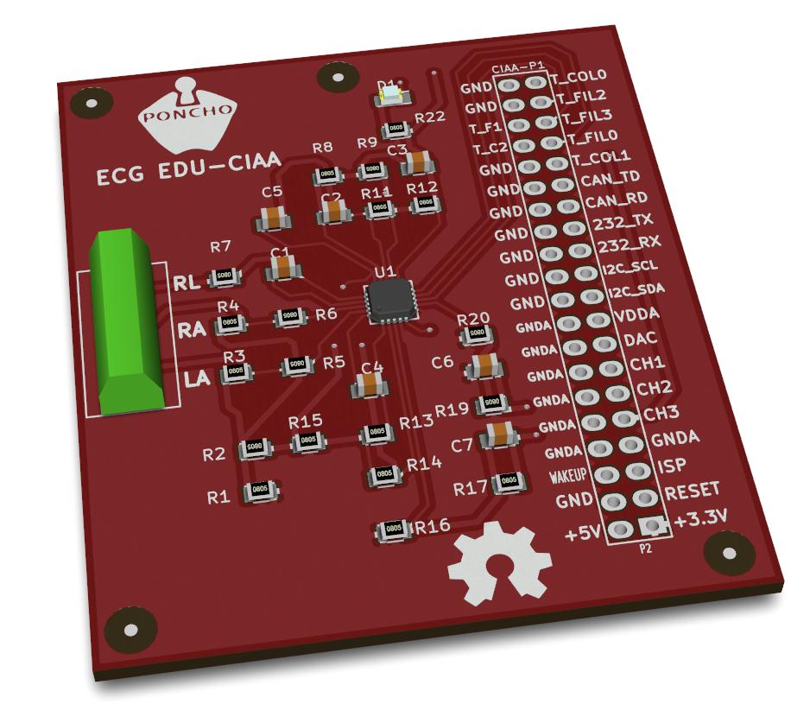
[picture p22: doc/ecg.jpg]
Vista 3D Poncho ECG


## Poncho L298 ##
  * Autor: Suarez Baron Juan Carlos.
  * Curso: 7 de Junio al 26 de Julio de 2016.
  * Descripción: El L298 implementa un doble puente H con un L298. Las entradas de control estan optoacopladas para proteger a la EDU-CIAA. Además posee varios indicadores LED para seguir el funcionamiento.
  * URL PONCHO: https://github.com/ciaa/Ponchos/tree/master/L298
  * URL Original: https://github.com/jsuarezbaron/Poncho_L298

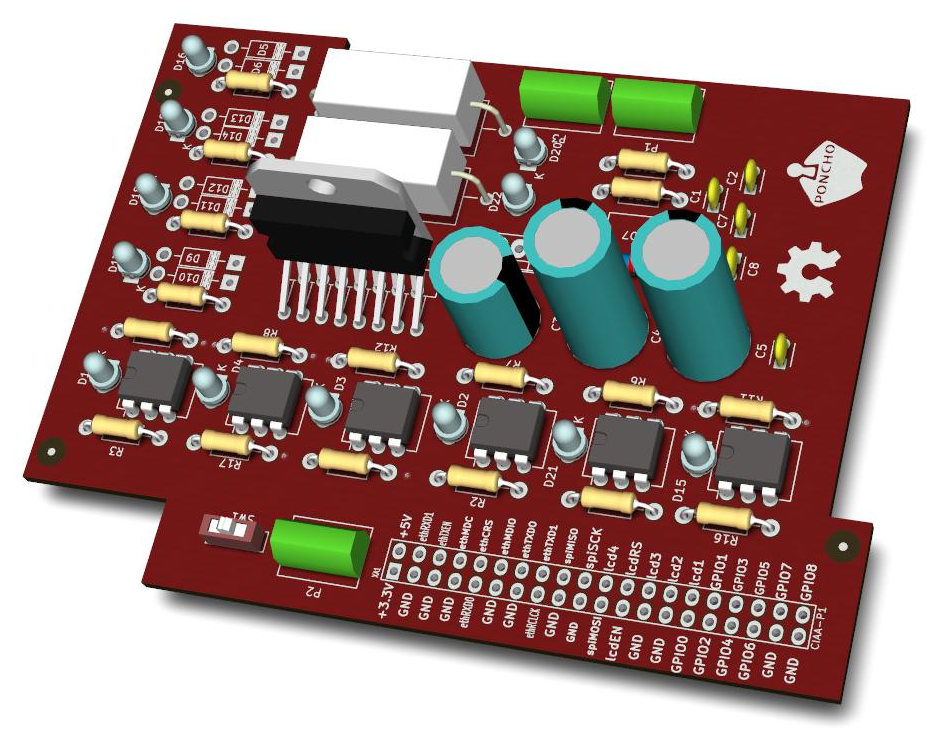
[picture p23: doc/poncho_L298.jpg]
Vista 3D Poncho L298


## Poncho Misión SAE ##
  * Autor: Elli Carlos.
  * Curso: 7 de Junio al 26 de Julio de 2016.
  * Descripción: El Poncho misión SAE "Ingeniería Satelital en la Escuela" es una reimplementación en Kicad del Poncho utilizado para la actividad mencionada. Más información sobre el tema en http://www.suremptec.com/es/noticias-y-eventos/127-exitoso-cierre-de-la-primera-edicion-de-la-mision-sae.html . El Poncho posee un módulo ZigBee, un sensor de presión y un módulo acelerómetro.
  * URL PONCHO: https://github.com/ciaa/Ponchos/tree/master/Mision_SAEv2

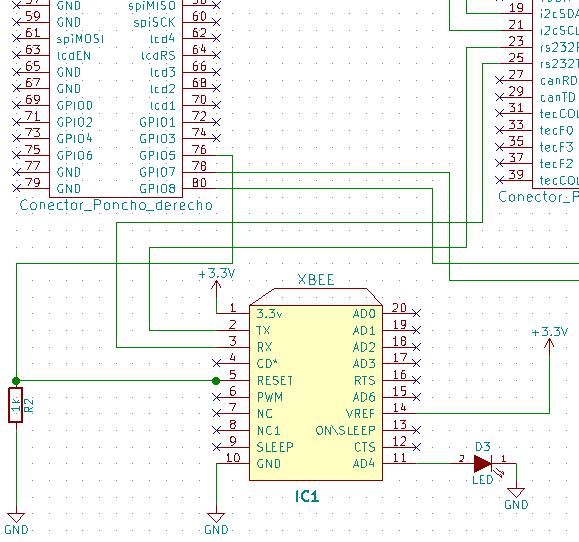
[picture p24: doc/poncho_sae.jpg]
Vista 3D Poncho L298


## AislacionUSB ##
  * Autor: Marcos Darino.
  * Curso: 7 de Junio al 26 de Julio de 2016.
  * Descripción: Circuito que busca crear aislación de la fuente de 
  alimentación del USB y de los datos de transmisión, buscando que no exista 
  conexión galvánica entre ellos. Es útil para programar dispositivos en campo,
  protegiendo el dispositivo de programación.

Vista 3D AislacionUSB

## Proyecto MICR ##
  * Autor: Valentín Korenblit.
  * Curso: 7 de Junio al 26 de Julio de 2016.
  * Descripción: Placa base para consolidar los componentes del proyecto de especialización. Se trata de un sistema de sensado de nivel, con sensado de temperatura, comunicación GPRS y una placa de control FRDM-KL25Z.
  * URL: https://github.com/vkorenblit/MICR_Hardware

Vista 3D Proyecto MICR

## Proyecto Modular Drummer ##
  * Autor: León Vásquez Iván Andrés.
  * Curso: 7 de Junio al 26 de Julio de 2016.
  * Descripción: Placa con funciones MIDI para un emprendimiento.
  * URL: Repositorio privado.

Vista 3D Proyecto Modular Drummer

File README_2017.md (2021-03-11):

<!--ts-->
   * [CURSO 3  - 2017](#curso-3----2017)
      * [Poncho  MIDI](#poncho--midi)
      * [Poncho  Poncho WIFI BLUETOOTH ESP-WROOM-32](#poncho--poncho-wifi-bluetooth-esp-wroom-32)
      * [Poncho  Expansor de Puertos](#poncho--expansor-de-puertos)
      * [Poncho Control de temperatura](#poncho-control-de-temperatura)
      * [Poncho Joystick](#poncho-joystick)
      * [Poncho Medición de pH](#poncho-medición-de-ph)
      * [Poncho  RF](#poncho--rf)
      * [PicoPoncho Lora](#picoponcho-lora)
      * [Poncho Educativo Modelo 2](#poncho-educativo-modelo-2)
      * [Poncho USB-XBEE](#poncho-usb-xbee)
      * [PicoPoncho Bluetooth HC05](#picoponcho-bluetooth-hc05)
      * [Poncho  LCD y Botones](#poncho--lcd-y-botones)

<!-- Added by: diego, at: jue mar 11 11:39:26 -03 2021 -->

<!--te-->

# CURSO 3  - 2017 #

Curso de Diseño de Circuitos Impresos de la Carrera de Especialización en Sistemas Embebidos.

**ADVERTENCIA**: Estos circuitos se realizan en tiempos muy cortos y no todos los circuitos reciben una revisión funcional detallada. 
El curso enfoca el los procedimientos de diseño de Esquemático y de PCB y no en el diseño funcional de los  circuitos.
El uso de estos circuitos queda bajo la propia responsabilidad del usuario.

## Poncho  MIDI ##
  * Autor: Mancón Carlos Ignacio
  * Curso: 11 de Abril al 30 de Mayo de 2017. 
  * Descripción: Este circuito implementa una interfaz MIDI conforme a la especificación de dicho estándar y un conjunto de actuadores para el disparo de paquetes e interacción con dispositivos compatibles. Se alimentará a través de USB o fuente externa. N10
  * URL PONCHO CIAA: Sin subir al repo Ponchos CIAA.
  * URL Original: https://github.com/cmancon/Ponchos (Rama MIDI)

Vista 3D Pico Poncho MIDI

## Poncho  Poncho WIFI BLUETOOTH ESP-WROOM-32 ##
  * Autor: Coccé Gastón
  * Curso: 11 de Abril al 30 de Mayo de 2017. 
  * Descripción: Poncho para la EDU-CIAA usando el módulo ESP-WROOM-32 que cuenta con conectividad WIFI y BLUETOOTH. El circuito se alimenta con energía de la placa EDU-CIAA y se comunicará con la EDU-CIAA por UART. N10
  * URL PONCHO CIAA: Sin subir al repo Ponchos CIAA.
  * URL Original: https://github.com/gcocce/poncho_EDU-CIAA_wifi_blth

Vista 3D Poncho WIFI BLUETOOTH ESP-WROOM-32

## Poncho  Expansor de Puertos ##
  * Autor: Orlante Mariano
  * Curso: 11 de Abril al 30 de Mayo de 2017. 
  * Descripción: Expansor de entradas y salidas digitales, y adaptador de nivel de tensión Low Voltage (3V3) a RS232 para puerto serie. 
Las entradas digitales son del tipo a transistor NPN “sinking” y se activan con tensión de continua externa en el rango de entre 3,5 a 25VDC.  Las entradas se pueden activar a través de contactos secos o salidas transistorizadas “sourcing”.
Las salidas digitales son del tipo a transistor NPN “sinking” a colector abierto. Una salida activada implica que el dispositivo drena corriente a la carga externa. Se deberá alimentar la carga con una tensión de entre 3,5 a 45VDC. N10
  * URL PONCHO CIAA: Sin subir al repo Ponchos CIAA.
  * URL Original: https://marianoo2001@gitlab.com/marianoo2001/EduCiaaPE.git

Vista 3D Poncho Expansor de Puertos

## Poncho Control de temperatura ##
  * Autor: Suarez Francisco
  * Curso: 11 de Abril al 30 de Mayo de 2017.
  * Descripción: Es una poncho destinado a intermediar con termocuplas mas el control de dos interruptores a traves de relays, pensado para hacer control de temperatura en un tanque de agua a travez de resistencias. N9
  * URL PONCHO CIAA: Sin subir al repo Ponchos CIAA.
  * URL Original: https://github.com/fransuarez/TPdesign_poncho.git

Vista 3D Poncho Control de Temperatura

## Poncho Joystick ##
  * Autor: Toris Alan
  * Curso: 11 de Abril al 30 de Mayo de 2017.
  * Descripción: Pponcho de la edu-ciaa con funcionalidad de Joystick que puede ser usado como interface de control de otros sistemas como juegos en pantallas o proyectos con motores. N9
  * URL PONCHO CIAA: Sin subir aún al repo Ponchos CIAA.
  * URL Original: https://gitlab.com/alantoris/poncho-joystick-edu-ciaa

Vista 3D Poncho Joystick

## Poncho Medición de pH ##
  * Autor: Suarez Baron Juan Carlos
  * Curso: 11 de Abril al 30 de Mayo de 2017.
  * Descripción: Este poncho permite medir de forma sencilla el pH de un líquido gracias a su placa controladora que ofrece un valor analógico proporcional a la medición. El controlador tiene un potenciometro multivuelta que permite la correcta calibración de la sonda. Tiene un LED que funciona como el indicador de alimentación, un conector BNC y la interfaz del sensor PH2.0. Para usarlo, simplemente conecte el sensor de pH con el conector BNC, luego conecte la interfaz PH2.0 en el puerto de entrada analógica de la EDU-CIAA. Si se programa, se obtendrá el valor del pH. N8 
  * URL PONCHO CIAA: Sin subir aún al repo Ponchos CIAA.
  * URL Original: https://github.com/jsuarezbaron/Poncho_Ph

Vista 3D Poncho Medición de pH

## Poncho  RF ##
  * Autor: Gelsi Fabrizio
  * Curso: 11 de Abril al 30 de Mayo de 2017.
  * Descripción: Este Poncho implementa un módulo inalámbrico de RF que puede ser utilizado en monitoreo de vehículos, control remoto, sistema de seguridad para el hogar, lectura inalámbrica de medidores, sistema de adquisición de datos industriales, etiqueta inalámbrica, adquisición de señales biológicas, monitoreo hidrológico y meteorológico, etc. Posee una interfaz XBee integrada, por lo que proporciona a los fabricantes más soluciones inalámbricas, como 315M a Bluetooth, 315M a WiFi , 315M a Xbee. N8
  * URL PONCHO CIAA: Sin subir aún al repo Ponchos CIAA.
  * URL Original: https://github.com/fabriziogelsi/ProyectoPCB_CESE_GELSI

Vista 3D Poncho RF

## PicoPoncho Lora ##
  * Autor: Año Mendoza Elías Alejandro
  * Curso: 11 de Abril al 30 de Mayo de 2017.
  * Descripción: Este circuito implementa el poncho Lora para la PicoCIAA basado en el módulo transmisor RFM95W de frecuencia 915Mhz. N7
  * URL PONCHO CIAA: Sin subir aún al repo Ponchos CIAA.
  * URL Original: https://github.com/eaam21/PicoCIAA_Lora

Vista 3D PicoPoncho Lora

## Poncho Educativo Modelo 2 ##
  * Autor: Vargas Jhon
  * Curso: 11 de Abril al 30 de Mayo de 2017.
  * Descripción: Este es un Poncho Educativo alternativo (Ya hay un Poncho educativo existente), principalmente para el desarrollo de Trabajos Prácticos para estudiantes de nivel secundario en adelante. N7
  * URL PONCHO CIAA: Sin subir aún al repo Ponchos CIAA.
  * URL Original: https://github.com/IngJhonVargas/Poncho-Educativo-v2.0.git

Vista 3D Poncho Ecuativo Modelo 2

## Poncho USB-XBEE ##
  * Autor: Angulo Franklin
  * Curso: 11 de Abril al 30 de Mayo de 2017.
  * Descripción: Esta Ponchofunciona con todos los módulos XBee incluyendo las versiones Serie 1 y 2, estándar y Pro. Esta placa viene equipada con regulador de 3.3V (entrada máxima de 5V), zócalo XBee, cuatro LEDs de estado y cambio de nivel. Puede usarse independiente de la EDU-CIAA mediante USB. N6
  * URL PONCHO CIAA: Sin subir aún al repo Ponchos CIAA.
  * URL Original: https://github.com/FranklinA/ProyectoFinalPCB.git

Vista 3D Poncho USB-XBEE

## PicoPoncho Bluetooth HC05 ##
  * Autor: Moreno Marin Marcelo Franz
  * Curso: 11 de Abril al 30 de Mayo de 2017.
  * Descripción: El Poncho posee modulo bluetooth HC05,un acelerometro HMC5883L, un buzzer, un led RGB y un regulador de 9V a 3.3V para alimentación. Consiste en un poncho (shield) para la Pico CIAA NXP que permite agregar al microcontrolador las características anteriormente mencionadas. Puede emplearse en robots, drones, transporte eléctrico y cualquier sistema de control automático en general. N5
  * URL PONCHO CIAA: Sin subir aún al repo Ponchos CIAA.
  * URL Original: https://github.com/mmarcelofrm/HC05_PONCHO_PICO_NXP

Vista 3D Poncho Bluetooth HC05

## Poncho  LCD y Botones ##
  * Autor: Almada  Pablo
  * Curso: 11 de Abril al 30 de Mayo de 2017.
  * Descripción: Poncho con display digital genérico 16x2 con 4  botones usando una entrada analógica. El objetivo de la utilización de la entrada analógica para los botones se debe a fines educativos respecto a la práctica de lecturas de esta naturaleza. N5
  * URL PONCHO CIAA: Sin subir aún al repo Ponchos CIAA.
  * URL Original: https://github.com/pabloalmada/poncho

Vista 3D Poncho LCD y Botones

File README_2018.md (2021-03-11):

<!--ts-->
   * [CURSO 4  - 2018](#curso-4----2018)
      * [Driver motor pap](#driver-motor-pap)
      * [CIAA-UNO](#ciaa-uno)
      * [Poncho multimedia](#poncho-multimedia)
      * [Puente H doble de 20A](#puente-h-doble-de-20a)
      * [Poncho Alarma](#poncho-alarma)
      * [Réplica del modulo 8 reles de arduino](#réplica-del-modulo-8-reles-de-arduino)
      * [Réplica Acelerometro-mma7361](#réplica-acelerometro-mma7361)
      * [Nodo SisCoCaf](#nodo-siscocaf)
      * [VOIP Shield para Nucleo F767](#voip-shield-para-nucleo-f767)
      * [Poncho CAN](#poncho-can)
      * [Papilio DUO](#papilio-duo)
      * [Detector de sonido arduino](#detector-de-sonido-arduino)
      * [Extension de tarjeta HCAL](#extension-de-tarjeta-hcal)
      * [Contador de pasajeros](#contador-de-pasajeros)
      * [Prototipo Equipo AVL](#prototipo-equipo-avl)
      * [Electrodo Activo para Electromiografía](#electrodo-activo-para-electromiografía)
      * [Replica Placa Madre WEMB01](#replica-placa-madre-wemb01)
      * [Sistema de intercambio de mensajes de voz](#sistema-de-intercambio-de-mensajes-de-voz)
      * [VOP24](#vop24)
      * [PCB para alarma IoT](#pcb-para-alarma-iot)
      * [Modulo TPMS sensor](#modulo-tpms-sensor)
      * [Poncho Procesador de Audio](#poncho-procesador-de-audio)
      * [wifi ESP-01 con relés optoacoplados](#wifi-esp-01-con-relés-optoacoplados)

<!-- Added by: diego, at: jue mar 11 11:39:25 -03 2021 -->

<!--te-->

# CURSO 4  - 2018 #
Curso de Diseño de Circuitos Impresos de la Carrera de Especialización en Sistemas Embebidos. Realizado el 31/08/2018 al 19/10/2018 en modalidad mixta (presencial y a distancia).

## Driver motor pap ## 	
 * Autor:	Slavkin	pablo	
 * Repo original: 	https://github.com/pslavkin/cese_kicad.git	
 * URL local: [Link al repo](./2018/Slavkin)	

Vista 3D
Vista 3D

## CIAA-UNO ## 	
 * Autor:	Dórdolo	Lucas Daniel	
 * Repo original: 	https://github.com/lucasd92/Disenio_PCB	
 * URL local: [Link al repo](./2018/Dordolo)	

Vista 3D

## Poncho multimedia ## 	
 * Autor:	Germino	Santiago	
 * Repo original: 	https://github.com/royconejo/cese-pcb	
 * URL local: [Link al repo](./2018/Germino)	

Vista 3D

## Puente H doble de 20A ## 	
 * Autor:	Pojomovsky	Alexis	
 * Repo original: 	https://github.com/apojomovsky/CESE-2018-TP-PCB	
 * URL local: [Link al repo](./2018/Pojomovsky)	

Vista 3D

## Poncho Alarma ##	
 * Autor:	Ale	Amid	
 * Repo original: 	https://github.com/turcoale/CESE18_PCB_Amid_Ale.git	
 * URL local: [Link al repo] (./2018/AmidAle)

Vista 3D

## Réplica del modulo 8 reles de arduino ##	
 * Autor:	Alvarez	Matias	
 * Repo original: 	https://github.com/alvmatias/CESE-6Co2018_PCB	
 * URL local: [Link al repo](./2018/Alvarez)	

Vista 3D

## Réplica Acelerometro-mma7361 ##	
 * Autor:	Chavez	Jenny	
 * Repo original: 	https://github.com/jennifferch/PCB	
 * URL local: [Link al repo](./2018/Chavez)

Vista 3D

## Nodo SisCoCaf ## 
 * Autor:	Compañy	Roberto	
 * Repo original: 	https://github.com/companyroberto/DisenioPCB	
 * URL local: [Link al repo](./2018/Company)

Vista 3D

## VOIP Shield para Nucleo F767 ## 	
 * Autor:	Estupiñan	Ericson	
 * Repo original: 	https://github.com/ericsonj/CESE2018-PCB-TP	
 * URL local: [Link al repo](./2018/Ericson)	

Vista 3D

## Poncho CAN ## 	
 * Autor:	Gavinowich	Gabriel	
 * Repo original: 	https://github.com/ggavinowich/CESE_PCB_poncho_CAN	
 * URL local: [Link al repo](./2018/Gavinowich)	

Vista 3D

## Papilio DUO ## 	
 * Autor:	Lavigna	Gonzalo	
 * Repo original: 	https://github.com/gonzalolavigna/CESE-2018-disenio-pcb-gonzalo-lavigna/commits/master	
 * URL local: [Link al repo](./2018/Lavigna)	

Vista 3D

## Detector de sonido arduino ## 
 * Autor:	Lombardi	Ignacio	
 * Repo original: 	N/A	
 * URL local: [Link al repo](./2018/Lombardi)	

Vista 3D

## Extension de tarjeta HCAL ## 	
 * Autor:	Mena	Jairo	
 * Repo original: 	https://github.com/jamenaso/PBC_TPF_jmena	
 * URL local: [Link al repo](./2018/Mena)	

Vista 3D

## Contador de pasajeros ## 	
 * Autor:	Menendez	Martín Nicolás	
 * Repo original: 	https://github.com/Martin-N-Menendez/PCB	
 * URL local: [Link al repo](./2018/Menendez)	

Vista 3D
Vista 3D

## Prototipo Equipo AVL ## 	
 * Autor:	Moreyra	Mauro Oscar	
 * Repo original: 	https://github.com/MauroMoreyra/EquipoAVL_pcb	
 * URL local: [Link al repo](./2018/Moreyra)	

Vista 3D

## Electrodo Activo para Electromiografía ## 	
 * Autor:	Moya	Telmo	
 * Repo original: 	N/A	
 * URL local: [Link al repo](./2018/Moya)	

Vista 3D

## Replica Placa Madre WEMB01 ## 	
 * Autor:	Oliva	Rafael Beltran	
 * Repo original: 	https://github.com/rafaeloliva/CESE2018_6Co_DPCBs	
 * URL local: [Link al repo](./2018/Oliva)	

Vista 3D

## Sistema de intercambio de mensajes de voz ## 	
 * Autor:	Pistarelli	Marcelo Daniel	
 * Repo original: 	N/A	
 * URL local: [Link al repo](./2018/Pistarelli)	

Vista 3D

## VOP24 ## 	
 * Autor:	Roux	Federico	
 * Repo original: 	https://github.com/fgr-17/dpcb.git	
 * URL local: [Link al repo](./2018/Roux)	

Vista 3D

## PCB para alarma IoT ## 	
 * Autor:	Salamandri	Santiago	
 * Repo original: 	https://bitbucket.org/santiagosalamandri/pcb_cese_2018	
 * URL local: [Link al repo](./2018/Salamandri)	

Vista 3D
Vista 3D

## Modulo TPMS sensor ## 	
 * Autor:	Tirapegui	Rodrigo Alejandro	
 * Repo original: 	N/A	
 * URL local: [Link al repo](./2018/Tirapegui)	

Vista 3D

## Poncho Procesador de Audio ## 	
 * Autor:	Vallasciani	Gastón	
 * Repo original: 	https://github.com/gastonvallasciani/CESE-6Co2018_PCB	
 * URL local: [Link al repo](./2018/Vallasciani)	

Vista 3D

## wifi ESP-01 con relés optoacoplados ## 	
 * Autor:	Yanez	Christian Marcelo	
 * Repo original: 	https://github.com/Christianyf/CESE_6Co_PCB.git	
 * URL local: [Link al repo](./2018/Yanez)	

Vista 3D

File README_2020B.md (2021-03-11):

# CURSO 2020 B #
Curso de Diseño de Circuitos Impresos de la Carrera de Especialización en Sistemas Embebidos. Realizado del 28/08/2020 al 16/10/2020 en modalidad  a distancia.

## Sistema Monitoreo Alarma de Incendio  ## 	
 * Autor:Marquez Daniel 
 * Repo: https://github.com/cese-dci/dci2020b-damf618
	
Vista 3D

## Réplica dc motor control  ## 	
 * Autor: Vittori Luciano
 * Repo: https://github.com/cese-dci/dci2020b-Luchao90

Vista 3D

##  Titulador automático ## 	
 * Autor: Daniele Fernando
 * Repo: https://github.com/cese-dci/dci2020b-fernandodaniele
	
Vista 3D

##  Board_NFC (Replica sin antena) ## 
 * Autor: Sciarrone	Hanes Nahuel
 * Repo: https://github.com/cese-dci/dci2020b-HanesSciarrone.git
	
Vista 3D

##  Poncho TCP/IP ## 	
 * Autor: Amundaray Cruz	Freds Argilio
 * Repo: https://github.com/cese-dci/dci2020b-Freds78
	
Vista 3D

## Replica ESP01 (Mejorada) ## 	
 * Autor: Pacher	Federico
 * Repo: https://github.com/cese-dci/dci2020b-fedepacher
	
Vista 3D

## Driver motor PAP y ADC  ## 	
 * Autor: Herrera	Sebastian 
 * Repo: https://github.com/cese-dci/dci2020b-sebaherrera74
	
Vista 3D

##  Helctec LoRa con cambios ## 	
 * Autor: Monzón Languasco	Lucas Fabricio
 * Repo: https://github.com/cese-dci/dci2020b-monzonlucasfabricio
	
Vista 3D

## Réplica pro micro sparkfun (similar)  ## 	
 * Autor: Camacho Dorado	Raul Alejandro
 * Repo: https://github.com/cese-dci/dci2020b-RaulCD3597
	
Vista 3D

##  Conversor de niveles lógicos  ## 	
 * Autor: Sarche	Felipe
 * Repo: https://github.com/cese-dci/dci2020b-FelipeSarche
	
Vista 3D

##  Réplica Sparkfun VS1063 ## 	
 * Autor: Muñoz	Jorge Salvador
 * Repo: https://github.com/cese-dci/tpfinal-jorgesmunoz.git
	
Vista 3D

##  Módulo de velocidad tacométrico ## 	
 * Autor: Ramoscelli	Gustavo
 * Repo: https://github.com/gramoscelli/dci2020b-gramoscelli
	
Vista 3D

##  Réplica Arduino nano 340g 2016 ## 	
 * Autor: Carrique	Juan
 * Repo: https://github.com/cese-dci/dci2020b-gorgojos
	
Vista 3D

## Beacon basado en DWM1001 (Réplica simplificada)  ## 	
 * Autor: Broin	David Mauricio
 * Repo: https://github.com/cese-dci/dci2020b-davidbro-in
	
Vista 3D

## Réplica Pinguino PIC  ## 	
 * Autor: Lara Tapia	Jose Mauricio
 * Repo: https://github.com/cese-dci/dci2020b-Mault7
	
Vista 3D

##  Réplica detección de obstáculos por infrarrojo ## 	
 * Autor: Carreño Romano	Carlos German
 * Repo: https://github.com/cese-dci/dci2020b-charlieromano
	
Vista 3D

##  Replica Adafruit HUZZAH32 - ESP32 Feather ## 	
 * Autor: Gorrin	Alejandro
 * Repo: https://github.com/cese-dci/dci2020b-AleGorrin
	
Vista 3D

## Poncho interfaz + arreglo sensores  IR  ## 	
 * Autor: Bertinat	Sofía
 * Repo: https://github.com/cese-dci/dci2020b-sofiabertinat
	
Vista 3D

## Programador de microcontroladores  ## 	
 * Autor: Cruz	Cesar
 * Repo: https://github.com/cese-dci/tpfinal-cesaraul/
	
Vista 3D

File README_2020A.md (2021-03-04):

# CURSO 2020 A #
Curso de Diseño de Circuitos Impresos de la Carrera de Especialización en Sistemas Embebidos. Realizado del 1/05/2020 al 19/06/2020 en modalidad a distancia.

##  Escáner Magnético de Soldaduras ## 	
 * Autor: Alonso Castillo Pablo José Carlos
 * Repo: https://github.com/cese-dci/tpfinal-pablojosecarlo
	
Vista 3D

##  Replica Acelerómetro adxl345 ## 	
 * Autor: Yapura Alberto Emanuel	
 * Repo: https://github.com/cese-dci/tpfinal-KayboProject
	
Vista 3D

##  Monitor de medidores de energía eléctrica ## 	
 * Autor: Barroso Benavides Mauricio	
 * Repo: https://github.com/cese-dci/tpfinal-mauriciobarroso
	
Vista 3D

## Réplica  modificada Heltec Wifi LoRA V2  ## 	
 * Autor: Abbate Santiago	
 * Repo: https://github.com/cese-dci/tpfinal-santiabbate
	
Vista 3D

##  Réplica Teensy 3.2 ## 	
 * Autor: Essaya Diego Nicolás	
 * Repo: https://github.com/cese-dci/tpfinal-dessaya
	
Vista 3D

## Poncho fotovoltaico ## 	
 * Autor: Majul	Ignacio	
 * Repo: https://github.com/cese-dci/tpfinal-imajul
	
Vista 3D

##  Módem Energy meter ## 	
 * Autor: Del Sancio Leonardo Daniel	
 * Repo: https://github.com/cese-dci/tpfinal-leonardods18

Vista 3D

##  Poncho EDU-CIAA Drivers ## 	
 * Autor: Zacharewicz Lorena	
 * Repo: https://github.com/cese-dci/tpfinal-loboplateado1203
	
Vista 3D

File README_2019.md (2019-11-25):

# CURSO 6  - 2019 #
Curso de Diseño de Circuitos Impresos de la Carrera de Especialización en Sistemas Embebidos. Realizado del 30/08/2019 al 18/10/2019 en modalidad mixta (presencial y a distancia).

## Punku, control de accesos ## 	
 * Autor: Volentini	Esteban	
 * Repo: https://github.com/cese-dci/tp-dci--evolentini
	
Vista 3D

##  Cargador de batería con protección ## 	
 * Autor: Brignone	Matías	
 * Repo: https://github.com/cese-dci/tp-dci--mbrignone
	
Vista 3D
		
## Replica EasyDriver v4.5 ## 	
 * Autor: Gontad	Gonzalo	
 * Repo: https://github.com/cese-dci/tp-dci--Gonzalogontad 
	
Vista 3D

## Poncho PLC CIAA 7 ## 	
 * Autor: Rey	Agustin	
 * Repo: https://github.com/cese-dci/tp-dci--agusrey
	
Vista 3D

## Placa adaptadora de señales de radar ## 	
 * Autor: Miguel Enrique del Valle Camino	
 * Repo: https://github.com/cese-dci/tp-dci--migueledvc
	
Vista 3D	

## Driver I2C de leds RGB ## 	
 * Autor: Camargo	Jhonattan	
 * Repo: https://github.com/cese-dci/tp-dci--JhonattanCamargo
	
Vista 3D

##  Encoder & Driver PaP ## 	
 * Autor: Campos Luis Mariano	
 * Repo: https://github.com/cese-dci/tp-dci--lmarianocampos
	
Vista 3D

## Dip Coater ## 	
 * Autor: Gambarotta	Martin Abel	
 * Repo: https://github.com/cese-dci/tp-dci--martinch14
	
Vista 3D

## Driver motor CC ## 	
 * Autor: Perren	Luciano	
 * Repo: https://github.com/cese-dci/tp-dci--lgperren81.git
	
Vista 3D
				
## Controlador de motor con sensor ## 	
 * Autor: Menditto	Juan Pablo	
 * Repo: https://github.com/cese-dci/tp-dci--jpmendi/
	
Vista 3D

## Placa Bridge Ethernet ## 	
 * Autor: Torrent	Leandro	leandro	
 * Repo: https://github.com/cese-dci/tp-dci--leandrotorrent
	
Vista 3D

## Fuente Step Up DC-DC ajustable 5v-35v ## 	
 * Autor: Sarmiento	Fabian	
 * Repo: https://github.com/cese-dci/tp-dci--BenjaSar
	
Vista 3D

# CURSO 5  - 2019 #
Curso de Diseño de Circuitos Impresos de la Carrera de Especialización en Sistemas Embebidos. Realizado el 30/04/2019 al 18/06/2019 en modalidad a distancia.
		
## Controlador de solenoides realimentado ## 	
 * Autor: Zimperz	Leopoldo
 * Repo: https://github.com/lzimperz/Control_solenoides.git
	
Vista 3D

## Módulo ESP8266 - nodeMCU ## 	
 * Autor: Suarez	Alejandro
 * Repo: https://github.com/alesuarez/CESE-7Co2018-12DCI-NodeMCU
	
Vista 3D

## Amplificador biológico educativo ## 	
 * Autor: Pizá	Alvaro Gabriel
 * Repo: https://github.com/gabyzon/CESE-7Co2018_DCI
	
Vista 3D

## RS485 Port KP995 ## 	
 * Autor: Paredes	Gustavo
 * Repo: https://github.com/FrossGus/TP_DCI_CESE 
	
Vista 3D

## Sistema de Monitoreo de Material Rodante ## 	
 * Autor: Guarino	Sebastian	
 * Repo: https://gitlab.com/sguarin/smmr-hardware 
	
Vista 3D

## Replica mejorada ESP32 Thing	## 	
 * Autor: Lucianna	Facundo Adrián
 * Repo: https://github.com/facundolucianna/CESE-7maCorte-DCI 
	
Vista 3D

## Kit desarrollo para microcontrolador pic16f1939 ## 	
 * Autor: Bustamante Narvaez	Julian
 * Repo: https://github.com/thejbte/TP_DSI 
	
Vista 3D

## Placa de desarrollo basado en una FPGA Libre	## 	
 * Autor: Salvador	Jacobo
 * Repo: https://github.com/jacorg/DCI_CESE-7Co2018.git 
	
Vista 3D

## Poncho adaptador Arduino Mega2560 ## 	
 * Autor: Moretti	Emilio
 * Repo: https://github.com/dc740/smart-ramps-to-edu-ciaa
	
Vista 3D

## Custom Raspberry Compute Module IO Board  ## 	
 * Autor: Fortunatti	Nelson
 * Repo: https://github.com/nelsonfort/RepositorioPCB.git
	
Vista 3D

## Réplica TTGO-LORA32-V2.0 ## 	
 * Autor: Ferreyra	Hernán
 * Repo: https://github.com/nancho17/CESE-7Co2018-Ferreyra/tree/master 
	
Vista 3D

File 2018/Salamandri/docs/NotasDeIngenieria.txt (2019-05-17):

- Todos los simbolos fueron obtenidos del repositorio oficial de Kicad (https://github.com/KiCad/kicad-symbols).
- Todos los footprints fueron obtenidos del repositorio oficial de Kicad (https://github.com/kicad/kicad-footprints).
- Todos* los modelos 3d fueron obtenidos del repositorio oficial de Kicad (https://github.com/kicad/kicad-packages3d).
*Con excepcion de :
	- Bornera.
	- Relay.
	- Micro USB.

- Para la realizacion del PCB, se utilizara un plóter fresador ProtoMat E33 de LPKF, cuya resolucion es 0.8 µm (0.04 mil).
- El microcontrolador ESP32, segun el documento(esp32_hardware_design_guidelines_en.pdf) de guia de diseño del fabricante debe esta colocado abajo a la derecha para tener menor interferencia.

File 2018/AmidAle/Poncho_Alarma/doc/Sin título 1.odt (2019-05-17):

Poncho Alarma:

El poncho alarma para la plataforma Educiaa, es una herramienta que permite de manera rápida contar con algunas interfaces básicas para desarrollar un pequeño sistema de alarma domiciliaria o domótica.

Características:

- 2 - Salidas Relay.
- 4 - Entradas optoacopladas.
- 1 - ESP8266 (ESP-01)
- 1 - Display Alfanumérico 16x2

Mapeo de Entradas – Salidas:

Poncho Alarma | Educiaa
Out_1 | GPIO0
Out_2 | GPIO2
In_1 | GPIO8
In_2 | GPIO7
In_3 | GPIO5
In_4 | GPIO3

Nota: Este poncho está basado en diseños anteriores de: Mariano Bustos - Jorge Osio - Diego Brengi

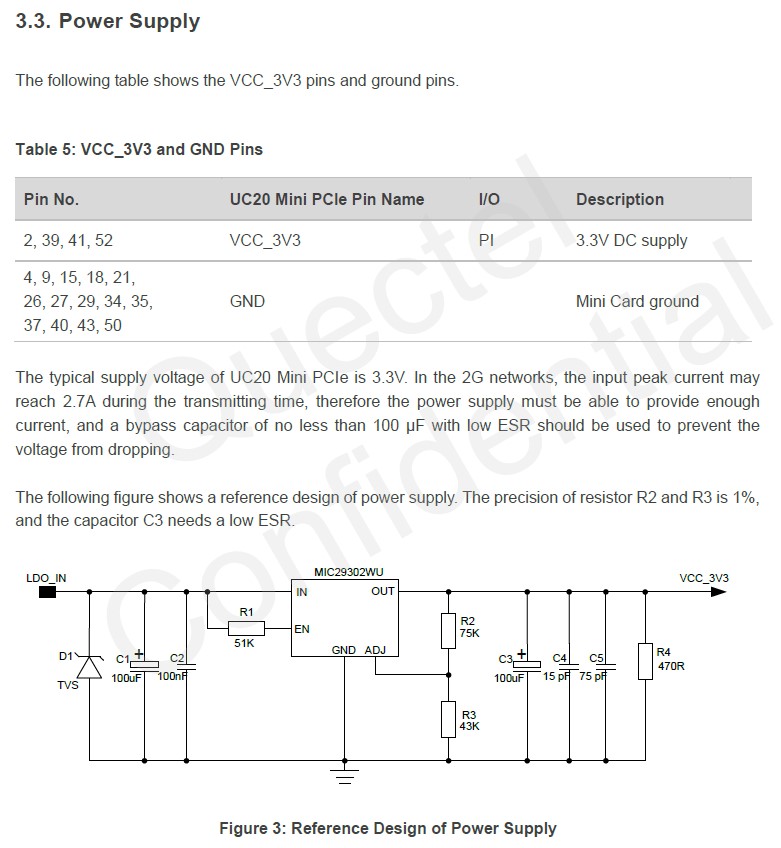
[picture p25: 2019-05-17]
2018/Moreyra/TrackerAVL/doc/Diseño de fuente para UC20.jpg

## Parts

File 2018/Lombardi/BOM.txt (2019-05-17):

3DX_CUI_INC_Supplier: CUI, Inc
3DX_CUI_INC_Description: 6.0 mm, Omnidirectional, PCB Mount, 2.0 Vdc, Electret Condenser Microphone
3DX_CUI_INC_Model Number: CMC-5044PF-A

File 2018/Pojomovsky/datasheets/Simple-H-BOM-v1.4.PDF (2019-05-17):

## Robot Power Simple-H - v1.4 - 2.8.07

Schematic ID | Description | Num | Value | Case | Pads | Holes | Manufacturer | Part #
CN1 | Terminal Block | 1 | 8-pos | 2.54mm | 8 Phoenix | 1725711
Fan | Terminal Block | 1 | 2-pos | 3.5mm | 2 Phoenix | 1751248
C1 | Main filter cap | 1 | 470uF 35V | 10mm x 20mm axial | 2 | Xicon | 140-XAL35V470-RC
C2, C3 | bridge caps | 2 | 1.0uF 25V X7R/X5R | 1206 | 4 | | Kemet | C1206C105K3RACTU
B+, B-, M1, M2 | Terminal Block | 4 | Snap-in PC mnt | - | 16 | Keystone | 7693
Motor LED | 1 | Red | T1 | 2 | Lite-On | LTL-1CHE
D1 | Motor LED | 1 | Green | T1 | 2 | Lite-On | LTL-1CHG
D2, D3, D4 | TVS | 3 | 30V | SMB | 6 | Diodes Inc. | SMBJ30A-13
IC1, IC2 | Motor 1/2 Bridge | 2 | | TO-263-7 | 14 | | Infineon | BTS7960B
H1, H2 | SMD Heatsinks | 2 | | .4" high | 4 | | Aavid Therm. | 573300D00010
R1, R2, R6, R7 | Buffer Resistors | 4 | 10k 5% | 1206 | 8 | | Yaego | RC1206JR-0710KL
R4, R5 | LED Resistor | 2 | 220 5% | 1206 | 4 | | Yaego | RC1206JR-07220RL
R3, R8 | Current sense res. | 2 | 634 1% | 1206 | 4 | | Yaego | RC1206FR-07634RL
J1 | dual row header | 0.11 .1" - 8 pos | .23" x .12" | 8 | Sullins | PEC36DAAN
| Total parts | 27
| Unique parts | 14
| Total SMD Pads | 44
| Total filled holes | 40

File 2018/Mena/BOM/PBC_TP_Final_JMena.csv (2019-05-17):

Id | Designator | Package | Quantity | Designation | Supplier and ref
1 | F104,F103,F101,F102 | Fiducial_0.75mm_Dia_1.5mm_Outer | 4 | Fiducial
2 | J602 | DSUB-9_Male_Horizontal_P2.77x2.84mm_EdgePinOffset7.70mm_Housed_MountingHolesOffset9.12mm | 1 | DB9_Male
3 | J601 | USB_Micro-B_Molex_47346-0001 | 1 | USB_B_Micro
4 | U602 | SOIC-16_3.9x9.9mm_P1.27mm | 1 | MAX3232
5 | R508,R409,R410,R411,R412,R413,R414,R415,R416,R501,R502,R503,R504,R505,R506,R507,R509,R510,R511,R512 | R_0805_2012Metric_Pad1.15x1.40mm_HandSolder | 20 | 1K
6 | Q507,Q508,Q502,Q501,Q503,Q504,Q505,Q506,Q401,Q402,Q403,Q404,Q405,Q406,Q407,Q408 | SOT-23 | 16 | FDV301N
7 | J505,J504 | PinHeader_1x04_P1.27mm_Vertical | 2 | Conn_01x04
8 | J501,J502 | PinHeader_2x20_P1.00mm_Vertical | 2 | Conn_01x40_Male
9 | J503 | PinHeader_1x06_P1.27mm_Vertical | 1 | Conn_01x06_Male
10 | U601 | SSOP-28_5.3x10.2mm_P0.65mm | 1 | FT232RL
11 | C608,C309,C310,C311,C313,C601,C602,C604,C606,C607,C609,C610 | C_0805_2012Metric_Pad1.15x1.40mm_HandSolder | 12 | 0.1uF
12 | D602,D201,D401,D402,D403,D404,D405,D406,D407,D408,D601 | LED_0805_2012Metric_Pad1.15x1.40mm_HandSolder | 11 | LED
13 | SW201 | SW_SPST_EVQPE1 | 1 | SW_DIP_x01
14 | C201,C202,C203,C204 | C_1206_3216Metric_Pad1.42x1.75mm_HandSolder | 4 | 10uF
15 | C301,C302,C303,C304,C305,C306,C307,C308,C312,C603 | C_0805_2012Metric_Pad1.15x1.40mm_HandSolder | 10 | 1uF
16 | C605 | C_1206_3216Metric_Pad1.42x1.75mm_HandSolder | 1 | 2.2uF
17 | D501,D502,D503,D504,D505,D506,D507,D508 | D_0805_2012Metric_Pad1.15x1.40mm_HandSolder | 8 | D_Schottky
18 | J201 | BarrelJack_CUI_PJ-102AH_Horizontal | 1 | Barrel_Jack
19 | J301,J302,J303,J304,J305,J306,J307,J308 | PinHeader_1x02_P1.27mm_Vertical | 8 | Conn_01x02_Female
20 | L201,L202,L203,L204,L205 | L_1206_3216Metric_Pad1.42x1.75mm_HandSolder | 5 | Ferrite_Bead
21 | MH101,MH102,MH103,MH104 | MountingHole_2.5mm | 4 | MountingHole
22 | R201 | R_0805_2012Metric_Pad1.15x1.40mm_HandSolder | 1 | 220
23 | R301,R302,R303,R304,R305,R306,R307,R308 | R_0805_2012Metric_Pad1.15x1.40mm_HandSolder | 8 | 10
24 | R309,R310 | R_0805_2012Metric_Pad1.15x1.40mm_HandSolder | 2 | 750
25 | R311 | R_0805_2012Metric_Pad1.15x1.40mm_HandSolder | 1 | 0
26 | R401,R402,R403,R404,R405,R406,R407,R408 | R_0805_2012Metric_Pad1.15x1.40mm_HandSolder | 8 | 470
27 | R601,R602 | R_0805_2012Metric_Pad1.15x1.40mm_HandSolder | 2 | 1K5
28 | SW401,SW402,SW403,SW404,SW405,SW406,SW407,SW408 | SW_SPST_B3U-1000P | 8 | SW_Push
29 | U201 | SOT-223-3_TabPin2 | 1 | NCP1117-5.0_SOT223
30 | U202 | TO-263-3_TabPin2 | 1 | LM1084-3.3
31 | U301,U302 | SOIC-14_3.9x8.7mm_P1.27mm | 2 | LM324
32 | U303 | TSSOP-16_4.4x5mm_P0.65mm | 1 | ADS7828
33 | U304 | SOT-23 | 1 | MCP1525-TT

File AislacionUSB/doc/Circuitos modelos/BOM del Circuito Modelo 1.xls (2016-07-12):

Qty. | Reference Designator | Description | Manufacturer/Number | Supplier/Number
2 | B1_C | NUP4202 Diode-TVS Array | ON Semiconductor NUP4202W1T2G | Mouser 863-NUP4202W1T2G
 | B2_C
11 | C10_C | 0805, 0.1µF, 50V capacitor | Panasonic-ECG ECJ-2FB1H104K | Stockroom A004-0005-043
 | C11_C
 | C13_C
 | C15_C
 | C16_C
 | C2_C
 | C3_C
 | C4_C
 | C6_C |  | 2009-07-08
 | C7_C
 | C9_C
1 | C12_C | 0.079" through hole, 100µF aluminum electrolytic, 6.3V capacitor (DNP) | Panasonic-ECG ECE-A0JKA101 | Digikey P803-ND
4 | C19_C | 0805, 10µF, 16V capacitor | Murata GRM21BR61C106KE15L | Stockroom A004-0008-060
 | C20_C
 | C5_C
 | C8_C
2 | C1_C | 0805, 1000pF, 50V capacitor | Panasonic-ECG ECJ-2VB1H102K | Stockroom A004-0008-005
 | C14_C
2 | C17_C | 10.00mm through hole, 100pF ceramic, 4000V safety capacitor | Murata DE1B3KX101KA5B | Mouser 81-DE1B3KX101KA5B
 | C18_C
4 | F1_C | 0805, ferrite bead | Murata BLM21PG221SN1D | Digikey 490-1054-1-ND
 | F2_C
 | F3_C
 | F4_C
2 | L1_C | 1210, common mode choke | TDK ACM3225-271-2P-T001 | Digikey 445-2032-1-ND (270Ω)
 | L2_C |  | TDK ACM3225-800-2P-T001 | Digikey 445-2030-1-ND (80Ω)
3 | R1_C | 0805, 10kΩ resistor |  | Stockroom A003-0018-083
 | R6_C
 | R7_C
4 | R2_C | 0805, 24.0Ω 1% resistor | Rohm Semiconductor MCR10EZHF24R0 | Digikey RHM24.0CCT-ND
 | R3_C
 | R4_C
 | R5_C
6 | R8_C | 0805 jumper |  | DNP
 | R9_C
 | R10_C
1 | SW1_C | switch, 1 position DIP | E-Switch KAJ01LAGT | Digikey EG4415-ND
1 | U3_C | ADuM1100 iCoupler Digital Isolator | Analog Devices Inc. ADuM1100ARZ
1 | U1_C | ADuM4160 Full/Low Speed USB Digital Isolator | Analog Devices Inc. ADuM4160BRWZ
1 | U2_C | ADuM5000 Isolated DC-to-DC Converter | Analog Devices Inc. ADuM5000ARWZ
1 | N/A | 2.07"L x 1.5"W x 1.06"H, 0.080" thick aluminum enclosure | Hammond Manufacturing 1590H | Digikey HM365-ND
1 | N/A | 2m shielded USB A to USB B cable | Assmann Electronics Inc. AK672-2-R | Digikey AE9932-ND
1 | J1_C and J2_C | 4 pin connector socket (comes as a 1 x 20 strip, break off as needed) | Mill-Max Manufacturing Corp. | Digikey ED6520-ND

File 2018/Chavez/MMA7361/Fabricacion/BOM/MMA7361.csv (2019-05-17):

Id | Designator | Package | Quantity | Designation | Supplier and ref
1 | C1,C3 | C_0805_2012Metric_Pad1.15x1.40mm_HandSolder | 2 | 1 µF
2 | C2,C4 | C_0805_2012Metric_Pad1.15x1.40mm_HandSolder | 2 | 470 µF
3 | C5,C6,C7 | C_0805_2012Metric_Pad1.15x1.40mm_HandSolder | 3 | 3.3nf
4 | D1 | LED_0805_2012Metric_Pad1.15x1.40mm_HandSolder | 1 | LED
5 | F1,F2,F3 | Fiducial_1mm_Dia_2mm_Outer | 3 | Fiducial
6 | J1,J2 | PinHeader_1x05_P2.54mm_Vertical | 2 | Conn_01x05
7 | R1 | R_0805_2012Metric_Pad1.15x1.40mm_HandSolder | 1 | 1 K
8 | U1 | SOT-89-3_Handsoldering | 1 | RT9161
9 | U2 | LGA-14_3x5mm_P0.8mm_LayoutBorder1x6y | 1 | MMA7361L

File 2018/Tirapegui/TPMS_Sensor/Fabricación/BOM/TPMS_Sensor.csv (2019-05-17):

Id | Identificador | Empaquetado | Cantidad | Identificación | Suministrador y ref
1 | U3 | RF_Antenna_PAD | 1 | PAD2
2 | U2 | RF_Antenna_PAD | 1 | PAD1
3 | R5,R4,R3,R15,R16,R8,R7,R6 | R_0603_1608Metric | 8 | DNP
4 | U1 | QFN-24_7x7mm | 1 | FXTH87xxxx
5 | BT1 | BatteryHolder_Seiko_MS621F | 1 | Battery_Cell
6 | C1 | C_0603_1608Metric | 1 | 1.5pF
7 | C2 | C_0603_1608Metric | 1 | 0.1uF
8 | C3 | C_0603_1608Metric | 1 | 100pF
9 | C4,C8,C11 | C_0603_1608Metric | 3 | DNP
10 | C5 | C_0603_1608Metric | 1 | 0.47uF
11 | C6,C7 | C_0603_1608Metric | 2 | 10pF
12 | C9 | C_0603_1608Metric | 1 | 1pF
13 | C10 | C_0603_1608Metric | 1 | 220pF
14 | L4 | L_0603_1608Metric | 1 | 39nH
15 | L3 | L_0603_1608Metric | 1 | DNP
16 | L2 | L_0603_1608Metric | 1 | 100nH
17 | L1 | L_0603_1608Metric | 1 | 10nH
18 | D2 | LED_0603_1608Metric | 1 | LED_B
19 | D1 | LED_0603_1608Metric | 1 | LED_A
20 | R13,R14,R9,R12,R10 | R_0603_1608Metric | 5 | 0
21 | R2,R1 | R_0603_1608Metric | 2 | 4k7
22 | R11 | R_0603_1608Metric | 1 | 10k
23 | F6,F5,F4,F2,F1,F3 | Fiducial_0.5mm_Dia_1mm_Outer | 6 | Fiducial
24 | J1 | PinHeader_2x03_P2.54mm_Vertical_SMD | 1 | Conn_02x03_Odd_Even
25 | JP1 | PinHeader_1x02_P2.54mm_Vertical | 1 | Jumper
26 | L5 | LFCoil_B82450A7204A000 | 1 | 7.2mH
27 | TP1,TP2,TP3,TP4,TP5 | TestPoint_Pad_1.0x1.0mm | 5 | TestPoint
28 | Y1 | Crystal_SMD_EuroQuartz_MT-4Pin_3.2x2.5mm | 1 | Xtal

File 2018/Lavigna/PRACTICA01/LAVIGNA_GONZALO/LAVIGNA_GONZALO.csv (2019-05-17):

Id | Identificador | Empaquetado | Cantidad | Identificación | Suministrador y ref
1 | C1 | C_Disc_D4.3mm_W1.9mm_P5.00mm | 1 | 100nF
2 | D1 | LED_D3.0mm | 1 | LED ROJO 3mm
3 | D2 | D_DO-34_SOD68_P7.62mm_Horizontal | 1 | 1N4148
4 | J1 | PinHeader_1x03_P2.54mm_Vertical | 1 | Conn_01x03
5 | R1 | R_Axial_DIN0207_L6.3mm_D2.5mm_P10.16mm_Horizontal | 1 | 100K

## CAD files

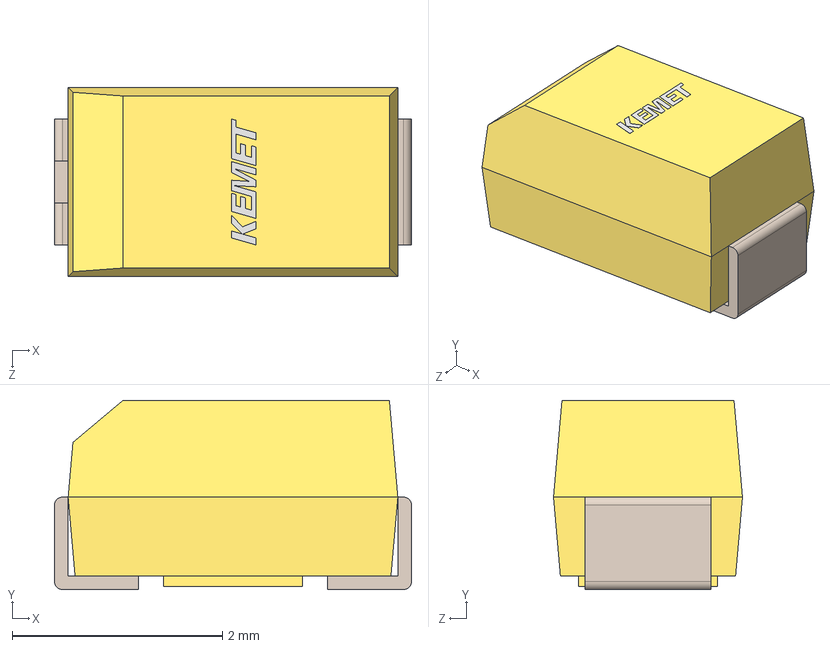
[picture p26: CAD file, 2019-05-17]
2018/Lavigna/PRACTICA_FINAL/PROJECTO_KICAD/FINAL/3D-MODELS/CAPACITOR TANTALIO KEMET/T491A475M010AT.step
3.40 x 1.80 x 1.80 mm
Case_Bottom_6
Case_Top_6
Case_Cathode_6
Case_Anode_6

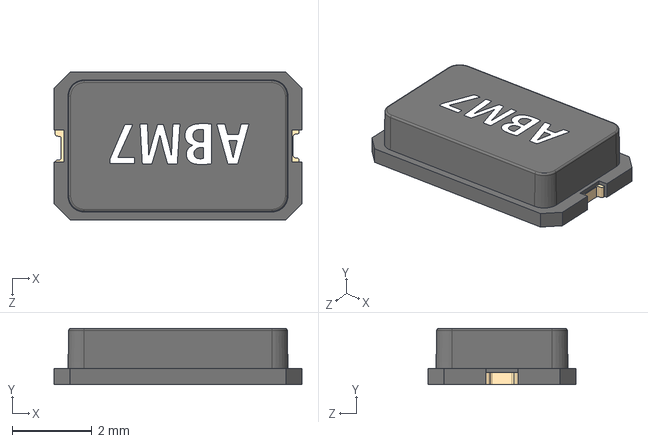
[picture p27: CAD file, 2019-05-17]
2018/Lavigna/PRACTICA_FINAL/PROJECTO_KICAD/FINAL/3D-MODELS/CRYSTAL-12MHZ-X1/User Library-Xtal-ABM7.STEP
6.20 x 1.40 x 3.70 mm
User Library-Xtal-ABM7_abm7case
User Library-Xtal-ABM7_abm7pad x 2

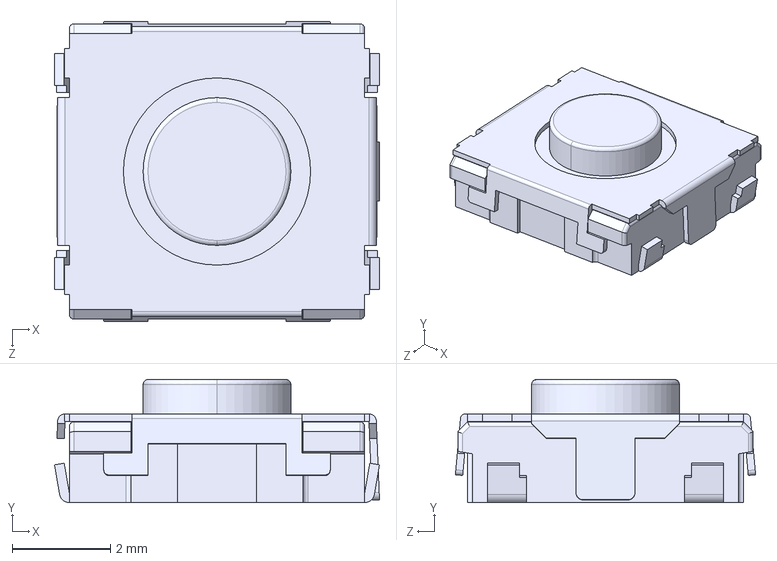
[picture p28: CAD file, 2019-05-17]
2018/Lavigna/PRACTICA_FINAL/PROJECTO_KICAD/FINAL/3D-MODELS/EVQQ2-SWITCH/User Library-EVQQ2-DHMSW2-02W.step
6.60 x 2.50 x 6.10 mm

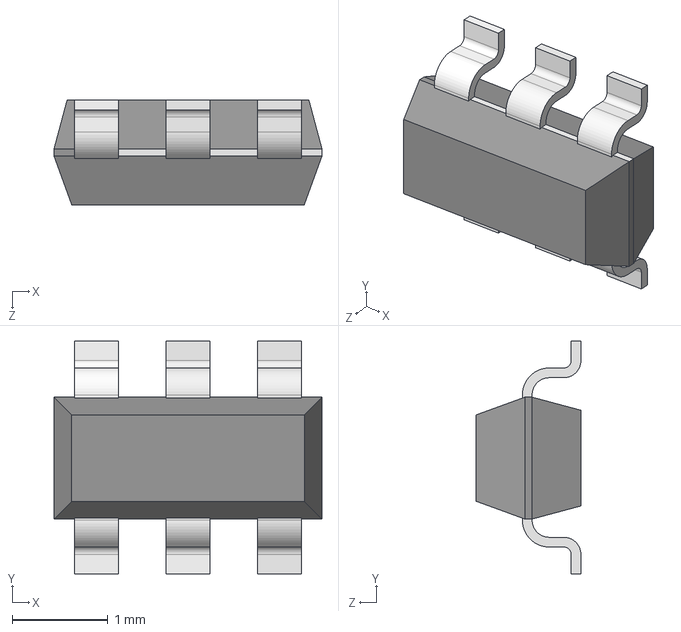
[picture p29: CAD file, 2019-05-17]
2018/Lavigna/PRACTICA_FINAL/PROJECTO_KICAD/FINAL/3D-MODELS/FLASH FTDI/SW3dPS-SOT-23-6.STEP
2.79 x 2.43 x 1.09 mm

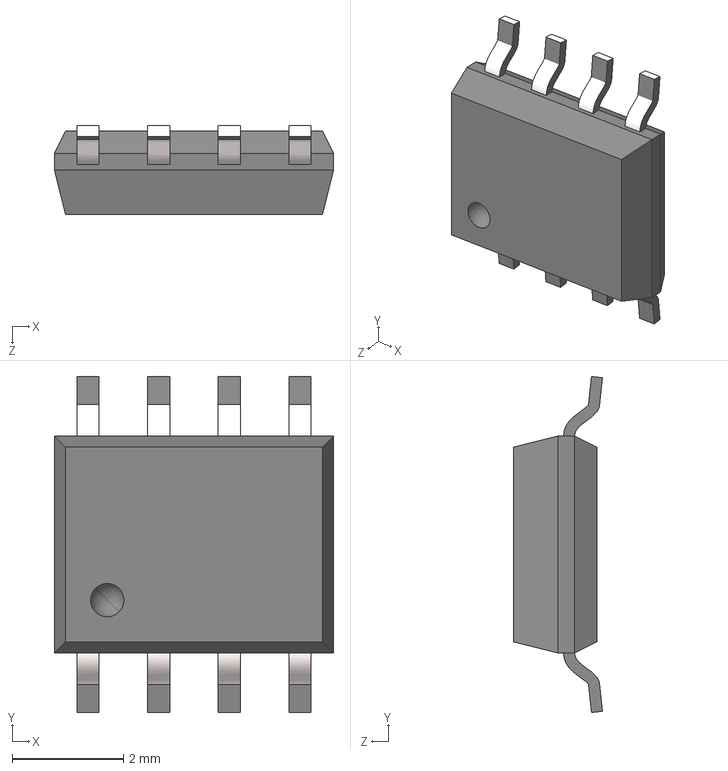
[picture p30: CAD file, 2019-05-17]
2018/Lavigna/PRACTICA_FINAL/PROJECTO_KICAD/FINAL/3D-MODELS/FLASH-SPI-SOP-8/User Library-sop-8.step
5.02 x 6.04 x 1.60 mm

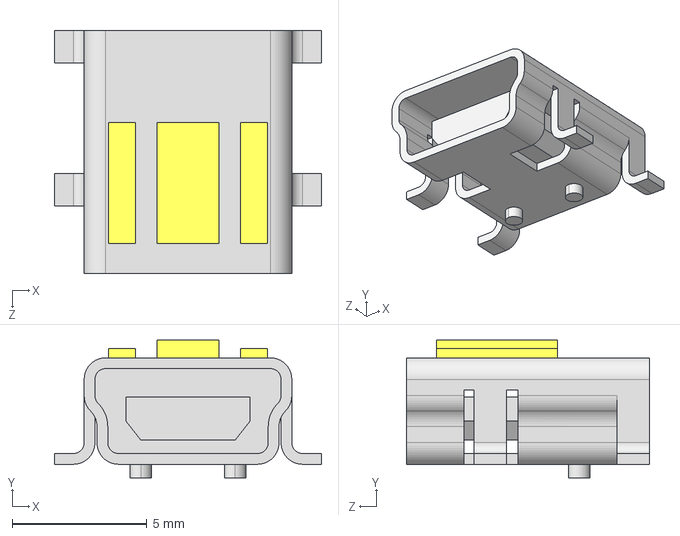
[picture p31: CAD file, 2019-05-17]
2018/Lavigna/PRACTICA_FINAL/PROJECTO_KICAD/FINAL/3D-MODELS/FPGA-USB/SW3dPS-conn_usb_mini.STEP
9.90 x 5.10 x 9.00 mm

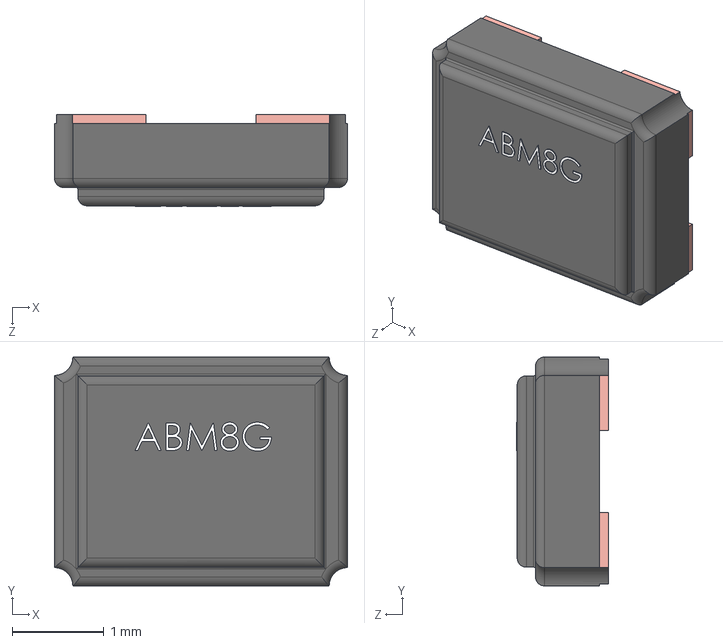
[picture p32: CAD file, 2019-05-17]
2018/Lavigna/PRACTICA_FINAL/PROJECTO_KICAD/FINAL/3D-MODELS/OSCILADOR-16MHZ-Y1/User Library-ABM8G.STEP
3.20 x 2.50 x 1.01 mm

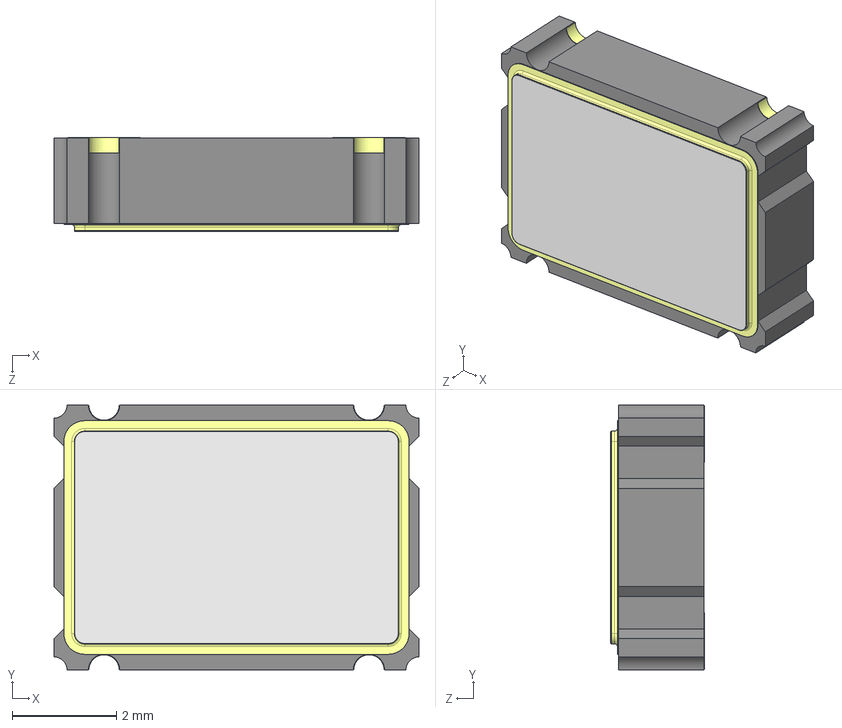
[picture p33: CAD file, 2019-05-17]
2018/Lavigna/PRACTICA_FINAL/PROJECTO_KICAD/FINAL/3D-MODELS/OSCILADOR-32MHZ-OSC1/User Library-ASV-Oscil.STEP
7.00 x 5.08 x 1.80 mm
User Library-ASV-Oscil_Fusion
User Library-ASV-Oscil_Fillet006
User Library-ASV-Oscil_Fillet007
User Library-ASV-Oscil_ASV_Oscil

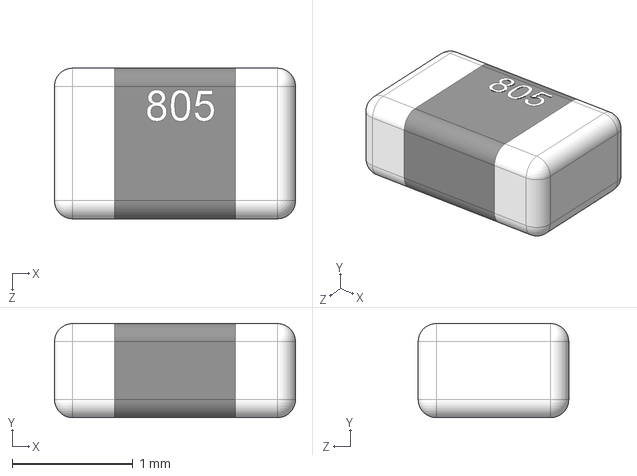
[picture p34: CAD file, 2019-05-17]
2018/Lavigna/PRACTICA_FINAL/PROJECTO_KICAD/FINAL/3D-MODELS/SMD0805/User Library-0805 SMD Resistor.step
2.00 x 0.782 x 1.25 mm

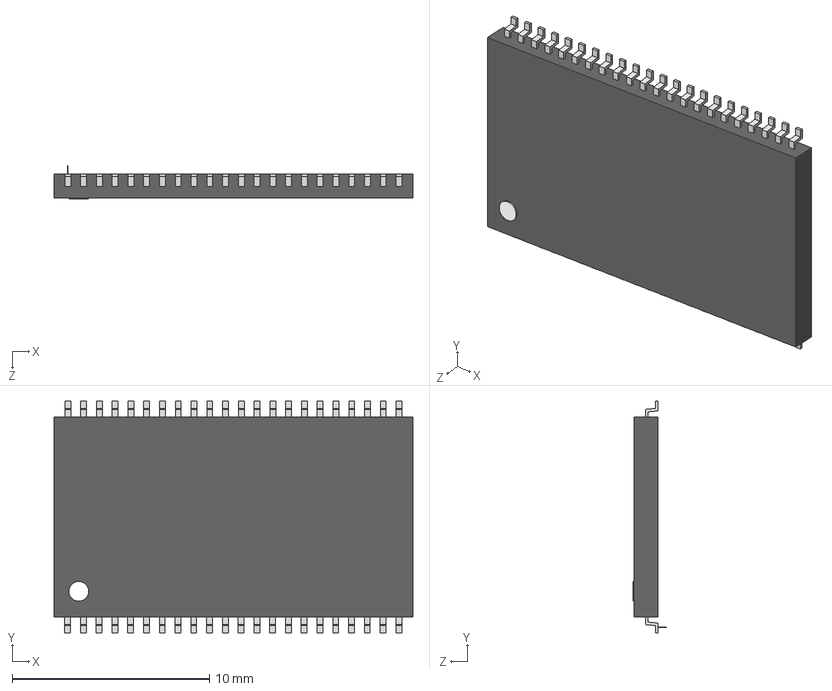
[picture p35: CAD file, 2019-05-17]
2018/Lavigna/PRACTICA_FINAL/PROJECTO_KICAD/FINAL/3D-MODELS/SRAM-ISSI/SW3dPS-TSOP2-44.STEP
18.2 x 11.8 x 1.70 mm
SW3dPS-TSOP2-44_Board5
SW3dPS-TSOP2-44_Extruded2 x 44
SW3dPS-TSOP2-44_Board4 x 44
SW3dPS-TSOP2-44_Cylinder1
SW3dPS-TSOP2-44_Extruded3
SW3dPS-TSOP2-44_Board3

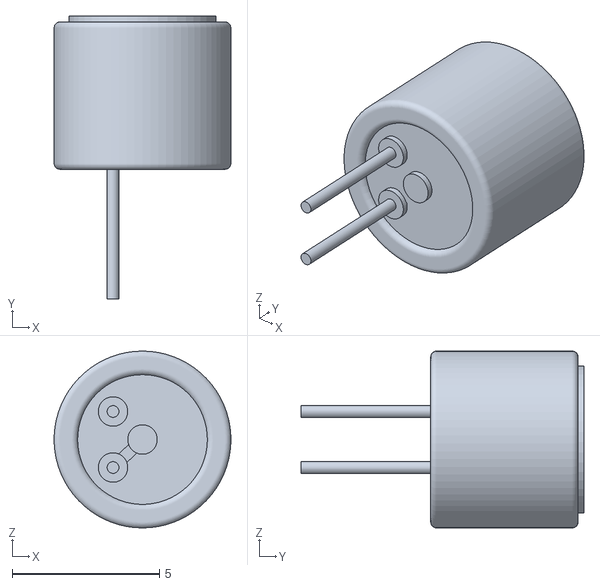
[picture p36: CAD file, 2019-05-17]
2018/Lombardi/CUI_CMC-5044PF-A.STL
5.99 x 9.60 x 6.00

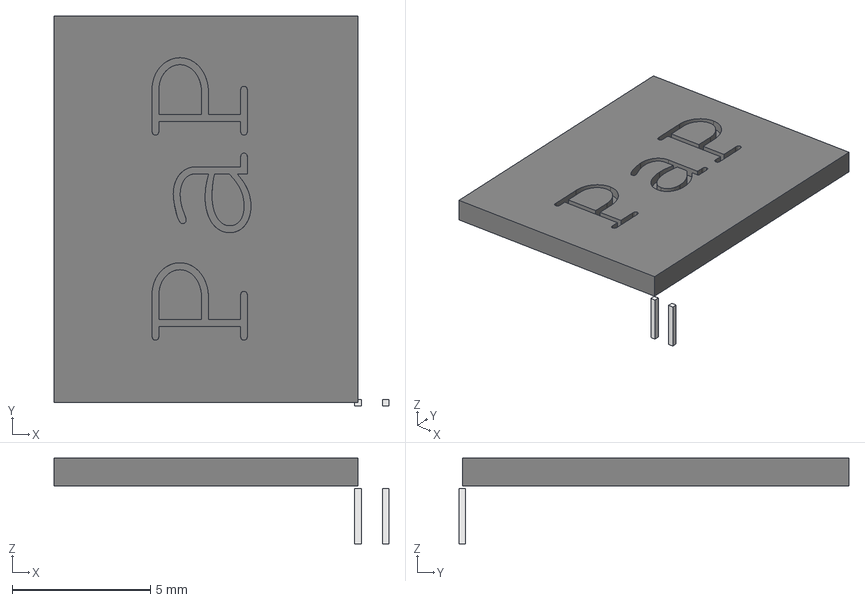
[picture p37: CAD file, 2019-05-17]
2018/Slavkin/3d/led.fcstd
12.1 x 14.1 x 3.10 mm
Clone of Cube

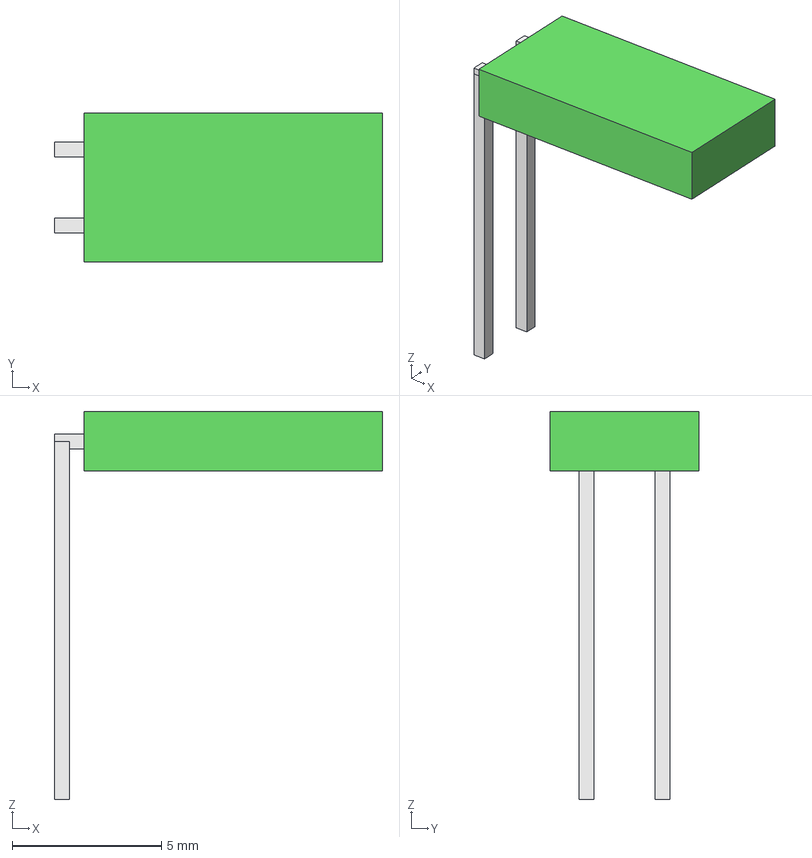
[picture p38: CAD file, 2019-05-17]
2018/Slavkin/3d/led_5x2_enchufable.fcstd
11.0 x 5.00 x 13.0 mm
Clone of Cube001
Clone of Cube002

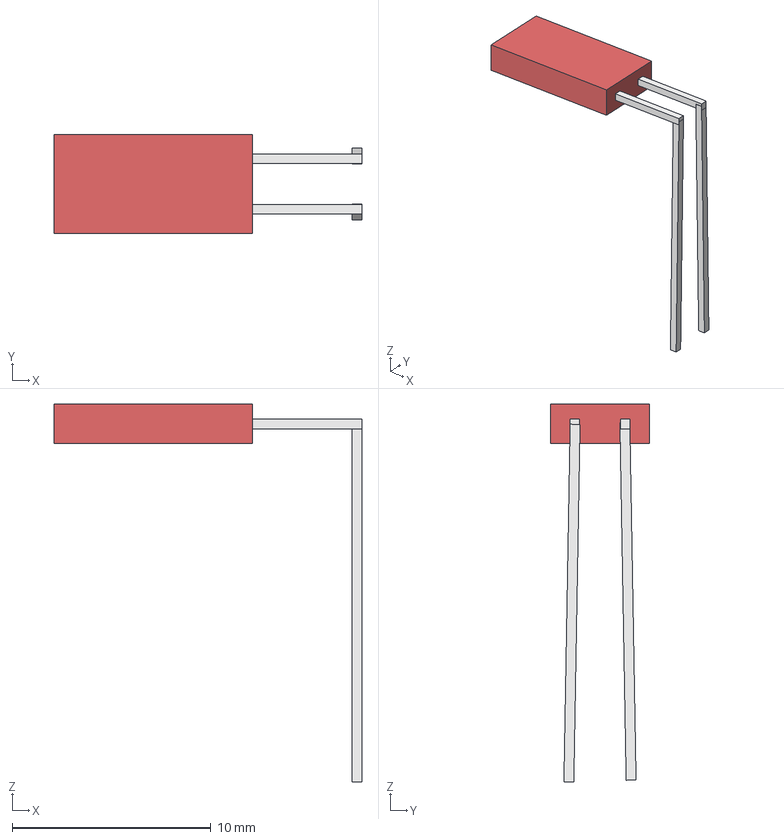
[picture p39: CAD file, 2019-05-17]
2018/Slavkin/3d/led_5x2_rj.fcstd
15.5 x 5.00 x 19.0 mm
Clone of Cube001
Clone of Cube002

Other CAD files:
2018/Slavkin/3d/led2.fcstd
2018/Lavigna/PRACTICA_FINAL/PROJECTO_KICAD/FINAL/3D-MODELS/AVR-USB/10118193-0001LF--3DModel-STEP-56544.STEP

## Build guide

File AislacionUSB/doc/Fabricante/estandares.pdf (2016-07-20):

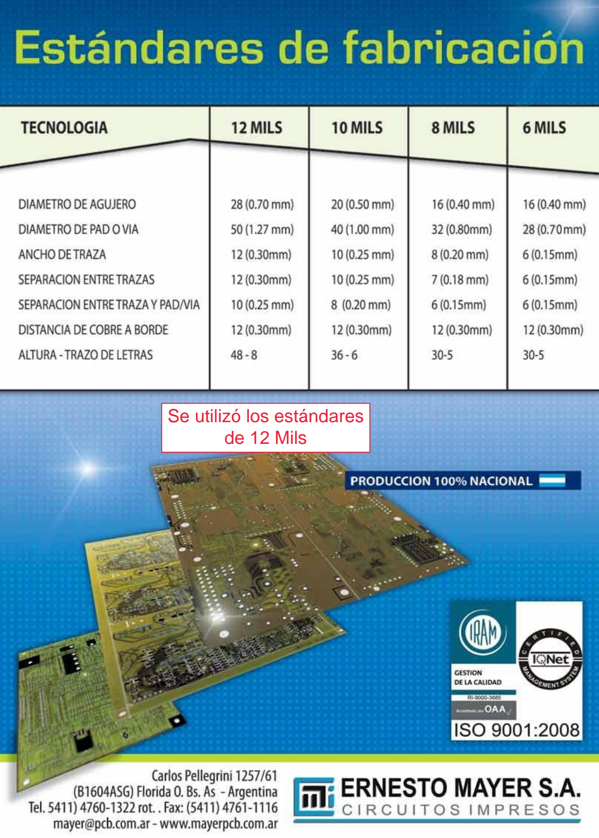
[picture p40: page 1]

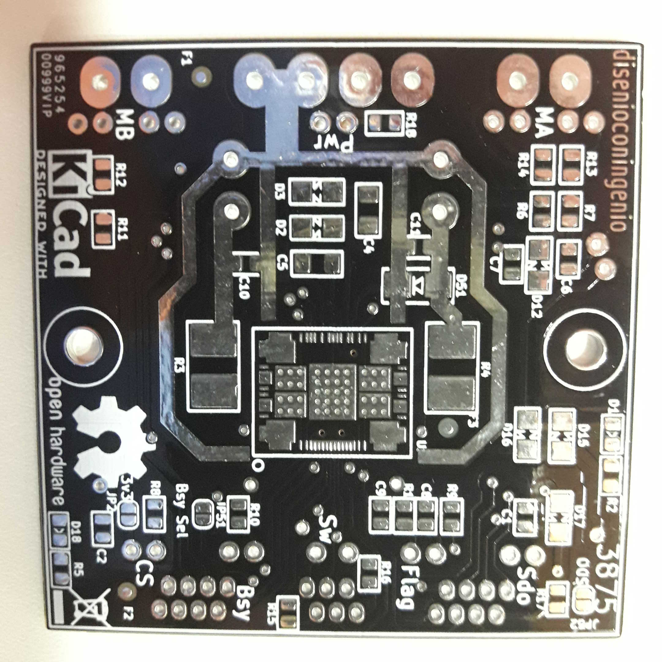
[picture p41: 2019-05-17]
2018/Slavkin/pics/pcb_fabricado1.jpeg

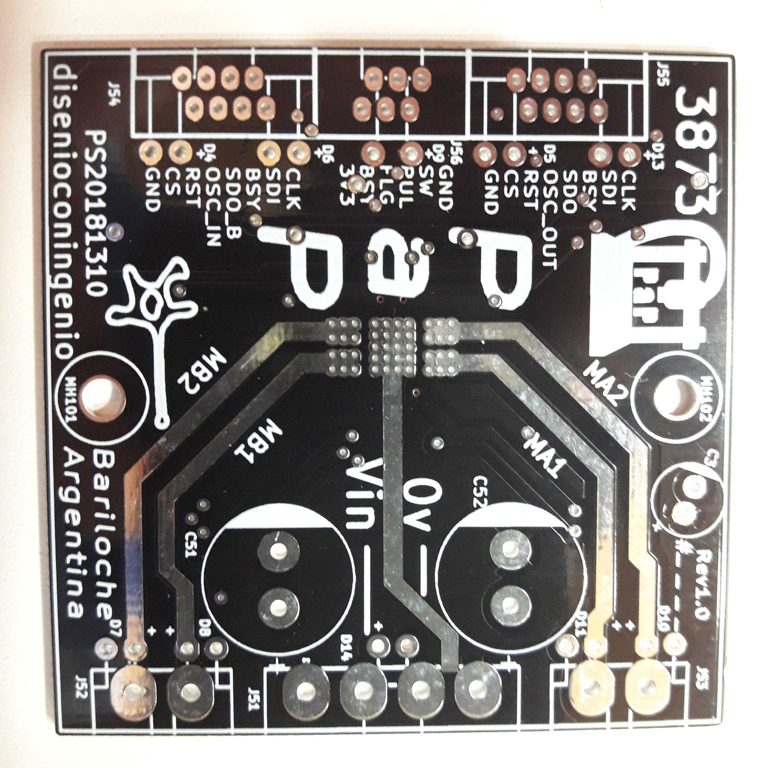
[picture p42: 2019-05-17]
2018/Slavkin/pics/pcb_fabricado2.jpeg

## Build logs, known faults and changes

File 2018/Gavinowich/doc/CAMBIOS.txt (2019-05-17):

Historial de cambios realizados 
================================

* Fecha: 2018-09-21
* Autores: Gabriel Gavinowich
* Archivos: 
* Descripción: Se parte del Modelo básico de Poncho en: 
               https://github.com/ciaa/Ponchos/tree/master/Basico

2018-09-21 Se inicia el esquematico
2018-10-04 Se termina la primera version del esquematico y se asignan las huellas
2018-10-09 Se arranca con el ruteo
2018-10-12 Se finaliza el ruteo
2018-10-19 Se agregan las hojas de datos y se actualiza la documentacion. SE agregan las marcas fiduciarias.

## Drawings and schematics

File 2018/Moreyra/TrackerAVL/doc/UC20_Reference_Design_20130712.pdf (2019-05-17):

# UC20 Reference Design Explanation

# 2. Index of Reference Design

## Sheet 2: Module Interface Sheet 3: Power Supply Design

## Sheet 4: UART and USIM Design

## Sheet 5: Audio Design Sheet 6: RF and GNSS Design

## Sheet 8: MCU Interface

## Sheet 7: Other Designs

<Mountain.ZHOU>

B

C

D

6 | 5 | 4 | 3 | 2 | 1

D

C

B

A

SHEET

DRAWN BY

CHECKED BY
<Bruce.YU>
1 6 | 5 | 4 | 3 | 2
PROJECT | TITLE

SIZE

of | <2013.07>

VER
A2

A

<UC20 Reference Design> <Design Explanation>

## Sheet 1: Design Explanation

## Quectel Wireless Solutions

# 1. Revision History

Revision | Date | Description
V1.01 V1.02 | 2013.05
| 2013.07

Initial.

1. Updated the name of UC20' Pins 1, 3, 4, 10, 13~17, 34, 47 and 55.
2. Reserved capacitor C801 between USB_DP and USB_DM signal lines.
3. Updated U301 circuit, added R307 and D302.
4. Updated GNSS reference circuit.
5. Updated the description of firmware upgrade and reserved testpoints.
6. Updated ADC voltage range.
7. Added SLEEP_IND, WAKEUP_IN and W_DISABLE# connections, removed the pin connected with Pin 55.
8. Changed R408 from NM to 15K.

# Quectel Confidential

D

D

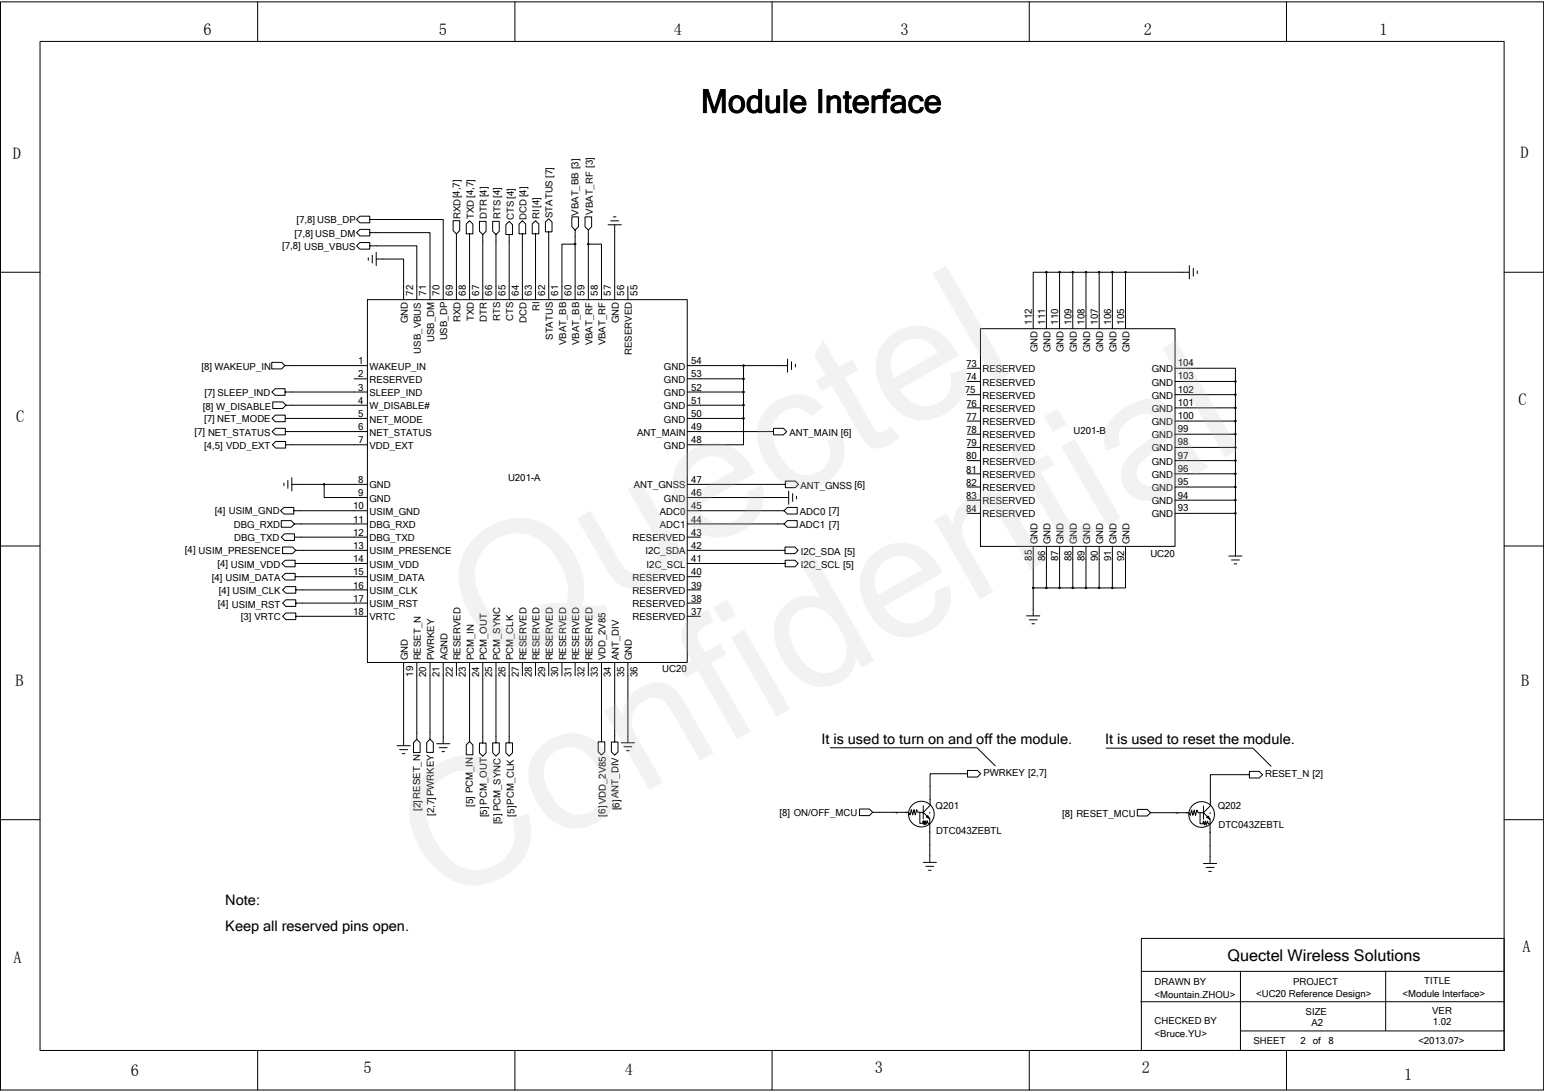
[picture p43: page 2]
<UC20 Reference Design>; <Module Interface>; TITLE; PROJECT; DRAWN BY <Mountain.ZHOU>; It is used to turn on and off the module.; It is used to reset the module.; Module Interface; 1 WAKEUP_IN 2 RESERVED; 3 SLEEP_IND 4 W_DISABLE# 5 NET_MODE 6 NET_STATUS 7 VDD_EXT; 8 GND 9 GND 10 USIM_GND 11 DBG_RXD 12 DBG_TXD 13 USIM_PRESENCE 14 USIM_VDD 15 USIM_DATA 16 USIM_CLK 17 USIM_RST 18 VRTC; 19 GND; 20 RESET_N 21 PWRKEY 22 AGND; 23 RESERVED 24 PCM_IN; 25 PCM_OUT; 26 PCM_SYNC 27 PCM_CLK; 28 RESERVED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

Note:
Keep all reserved pins open.

Quectel Wireless Solutions

+ 5V

# LDO Application

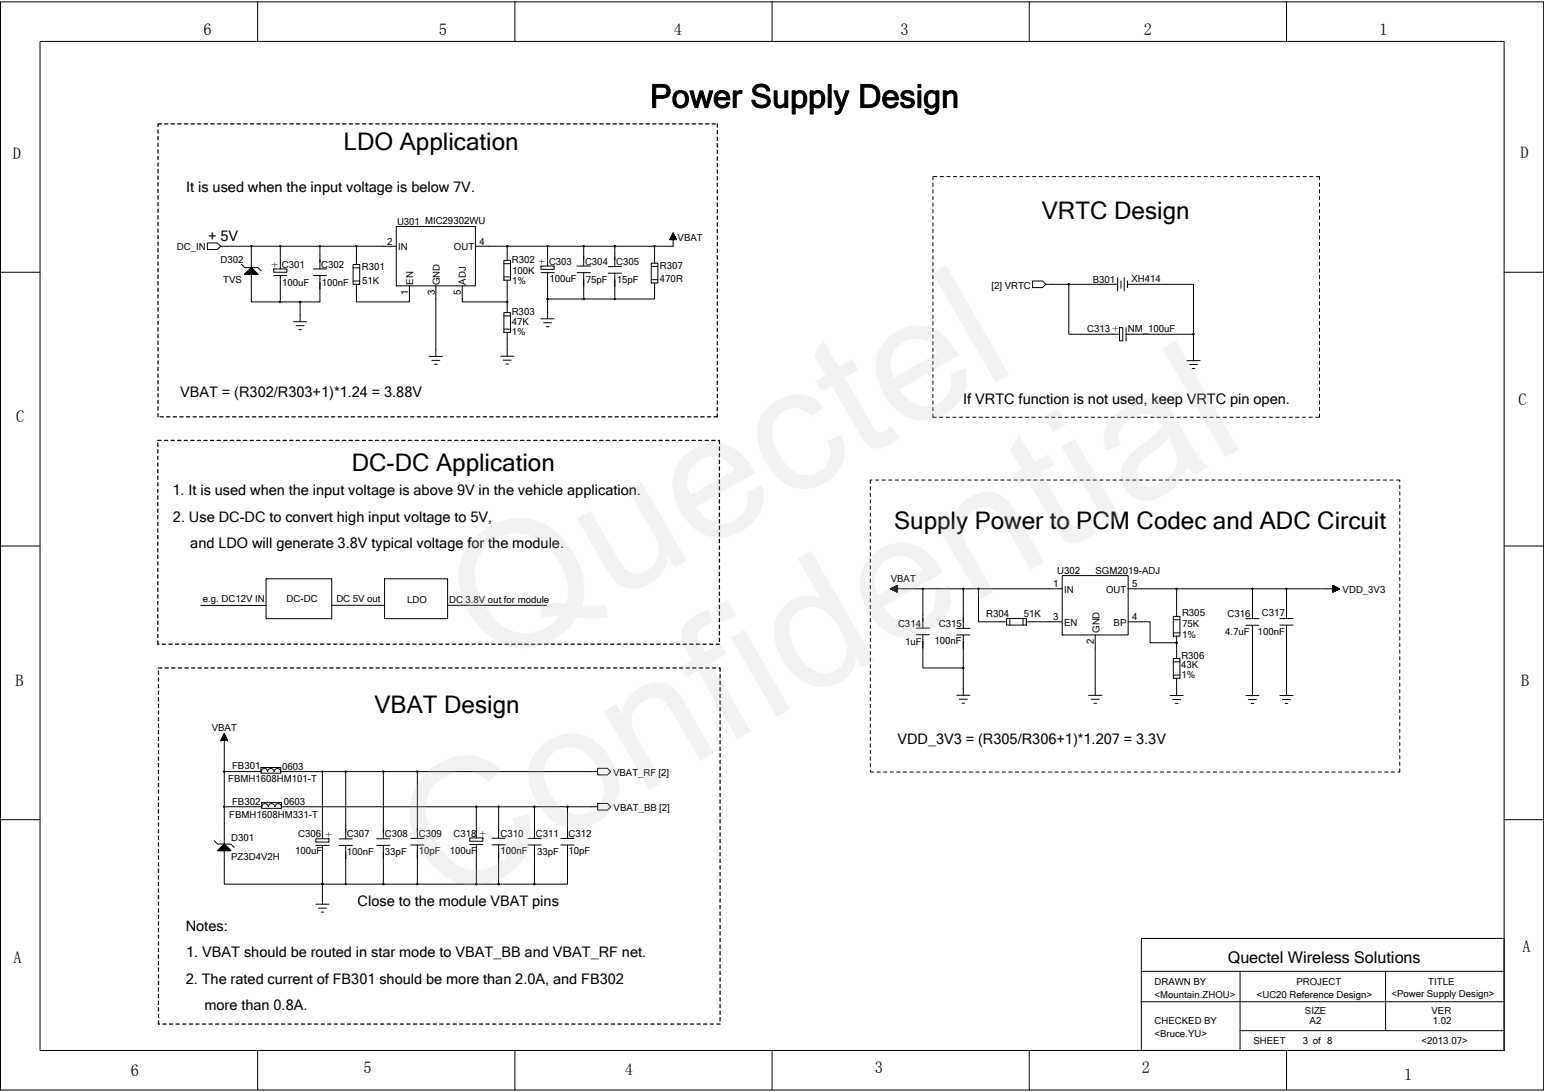
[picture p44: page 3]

It is used when the input voltage is below 7V.

If VRTC function is not used, keep VRTC pin open.

1. It is used when the input voltage is above 9V in the vehicle application.
2. Use DC-DC to convert high input voltage to 5V,
and LDO will generate 3.8V typical voltage for the module.

Supply Power to PCM Codec and ADC Circuit

Close to the module VBAT pins

Notes:
1. VBAT should be routed in star mode to VBAT_BB and VBAT_RF net.
2. The rated current of FB301 should be more than 2.0A, and FB302
more than 0.8A.

# USIM Design

D

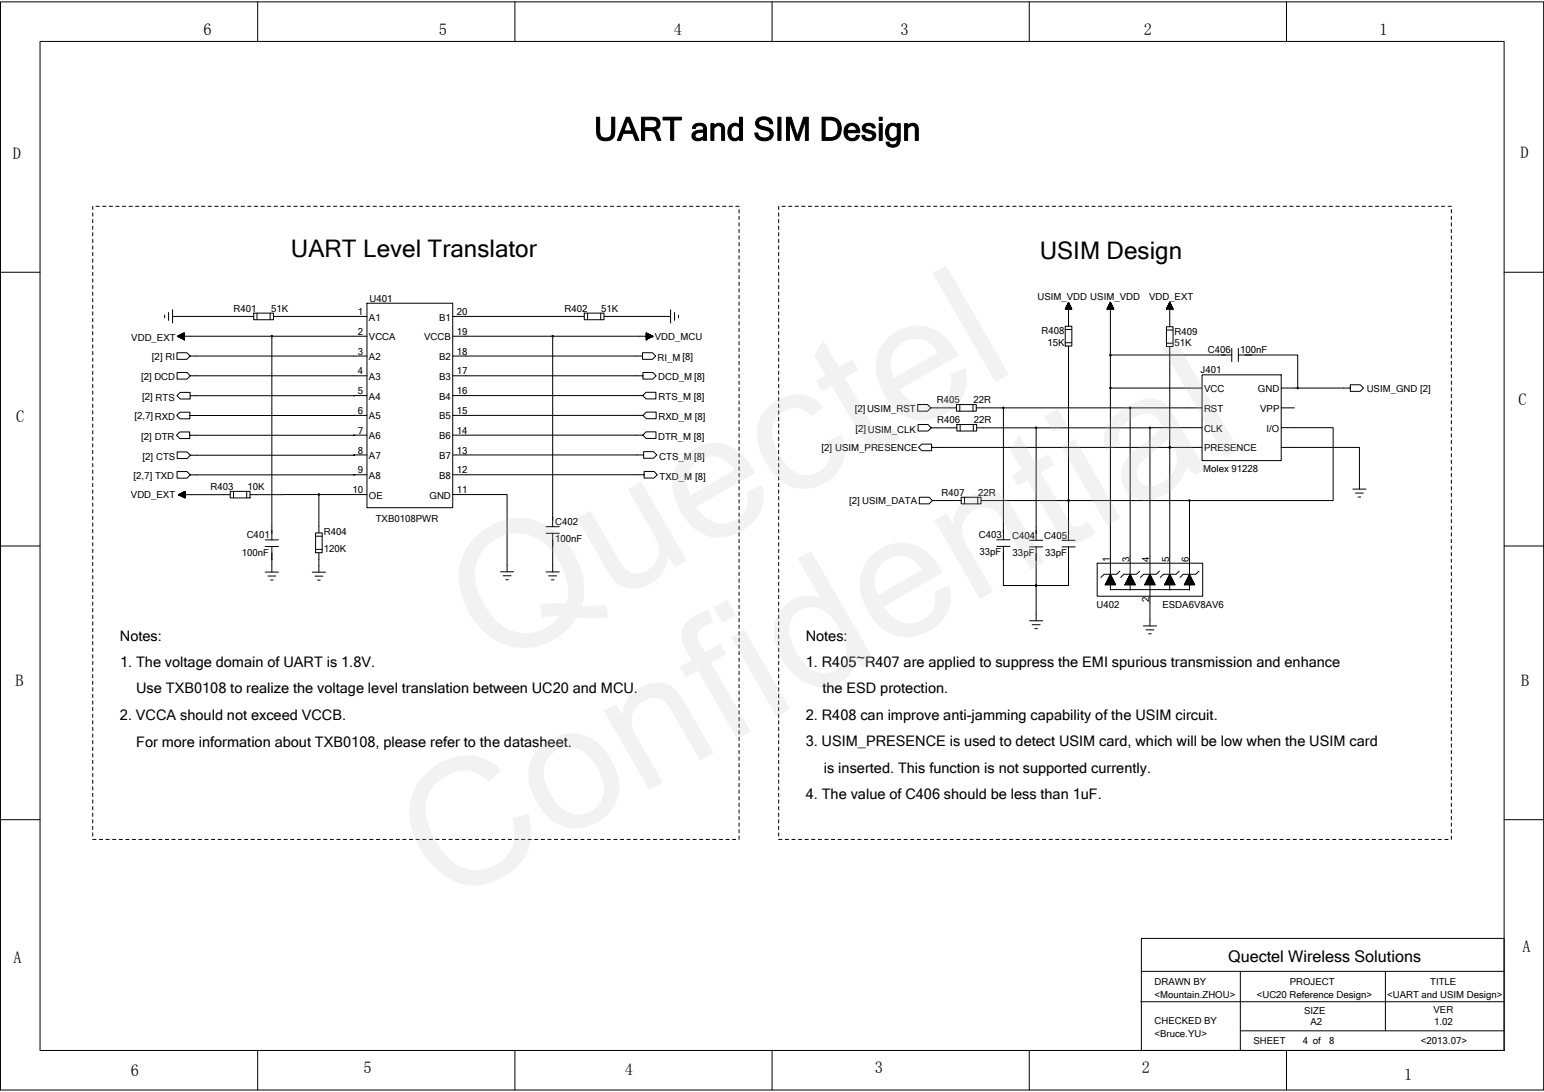
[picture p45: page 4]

UART and SIM Design

Notes:
1. The voltage domain of UART is 1.8V.
Use TXB0108 to realize the voltage level translation between UC20 and MCU.
2. VCCA should not exceed VCCB.
For more information about TXB0108, please refer to the datasheet.

1. R405~R407 are applied to suppress the EMI spurious transmission and enhance
the ESD protection.
2. R408 can improve anti-jamming capability of the USIM circuit.
3. USIM_PRESENCE is used to detect USIM card, which will be low when the USIM card
is inserted. This function is not supported currently.
4. The value of C406 should be less than 1uF.

# Audio Design

D

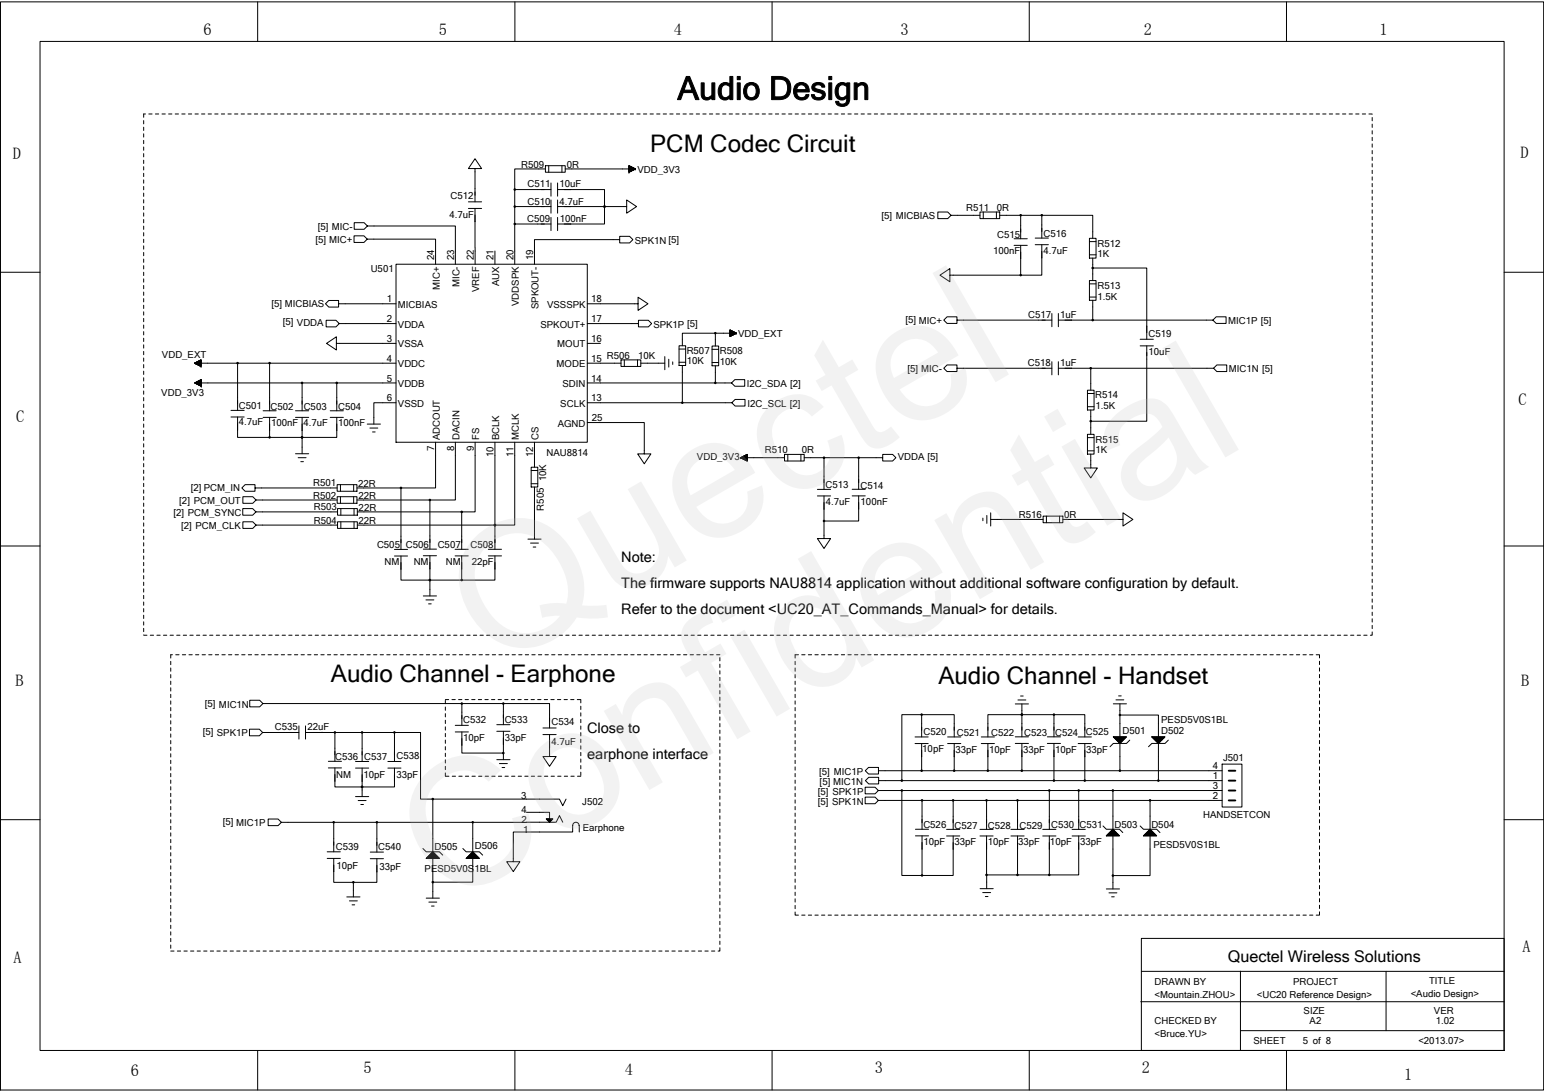
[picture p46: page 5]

Note:
The firmware supports NAU8814 application without additional software configuration by default.
Refer to the document <UC20_AT_Commands_Manual> for details.

Main Antenna Interface | Diversity Antenna Interface

D

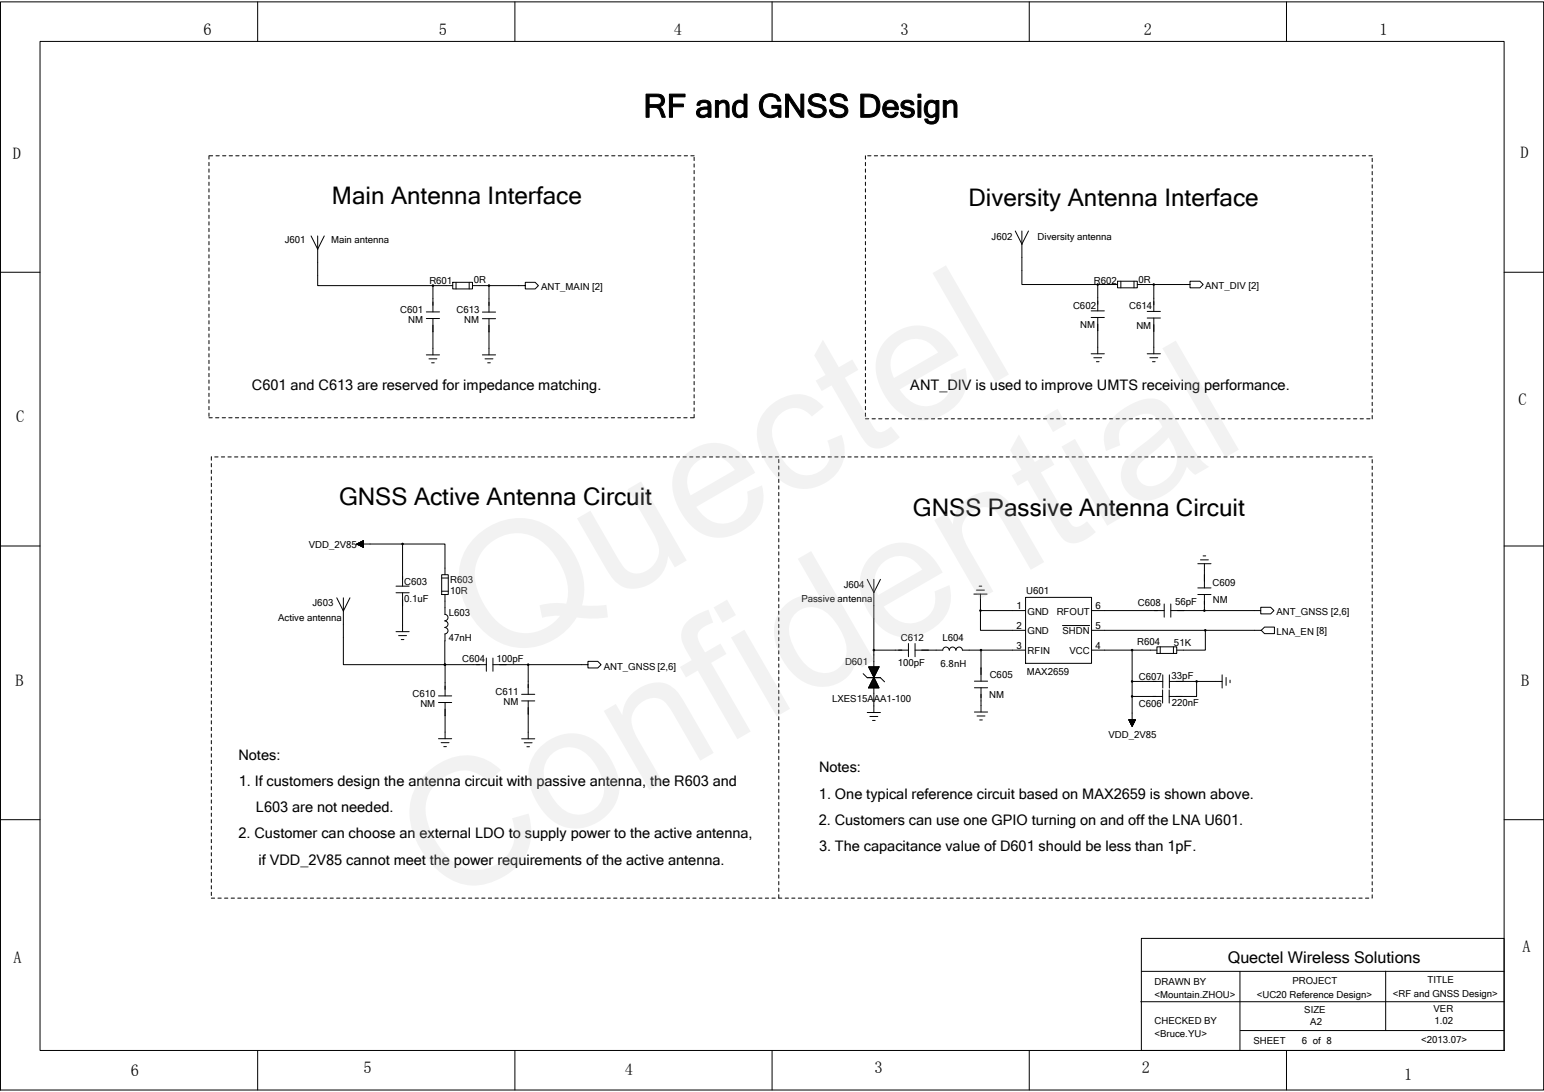
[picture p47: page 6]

RF and GNSS Design

C601 and C613 are reserved for impedance matching.

ANT_DIV is used to improve UMTS receiving performance.

GNSS Active Antenna Circuit

GNSS Passive Antenna Circuit

Notes:
L603 are not needed.
3. The capacitance value of D601 should be less than 1pF. 2. Customer can choose an external LDO to supply power to the active antenna,
if VDD_2V85 cannot meet the power requirements of the active antenna.

2. Customers can use one GPIO turning on and off the LNA U601.

D

D

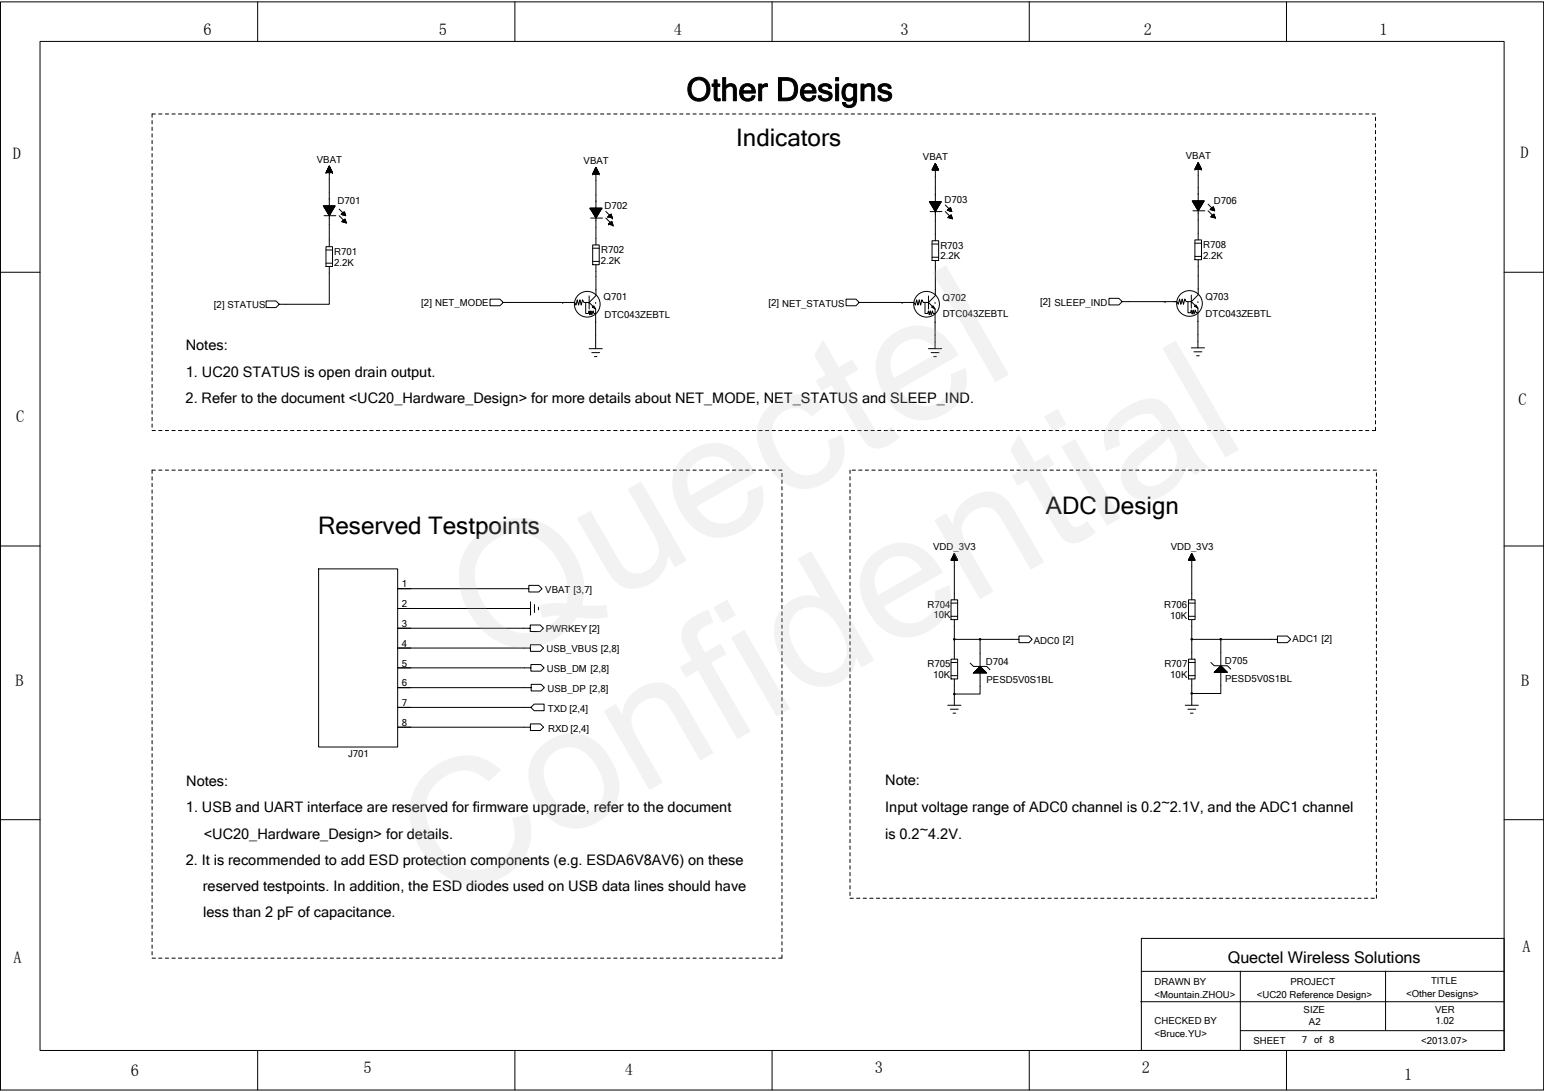
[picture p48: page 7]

Notes:
1. UC20 STATUS is open drain output.
2. Refer to the document <UC20_Hardware_Design> for more details about NET_MODE, NET_STATUS and SLEEP_IND.

1. USB and UART interface are reserved for firmware upgrade, refer to the document
2. It is recommended to add ESD protection components (e.g. ESDA6V8AV6) on these
reserved testpoints. In addition, the ESD diodes used on USB data lines should have
less than 2 pF of capacitance.

Note:
Input voltage range of ADC0 channel is 0.2~2.1V, and the ADC1 channel

D
D

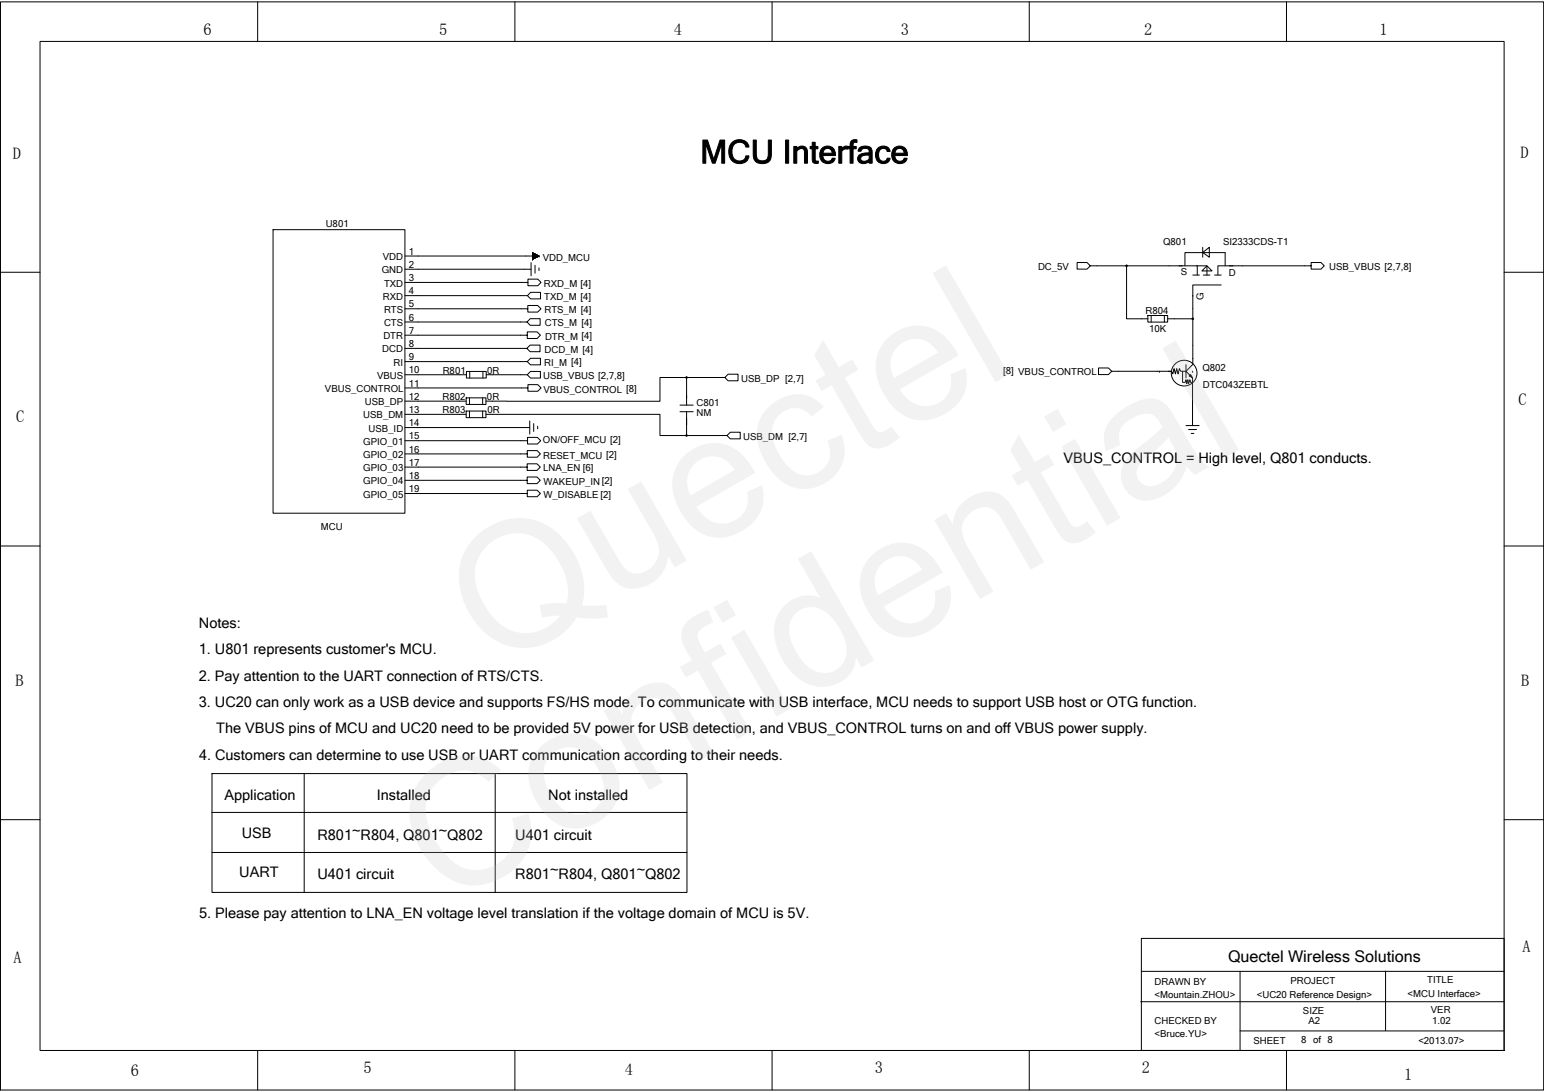
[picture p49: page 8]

Notes:
1. U801 represents customer's MCU.
2. Pay attention to the UART connection of RTS/CTS.
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

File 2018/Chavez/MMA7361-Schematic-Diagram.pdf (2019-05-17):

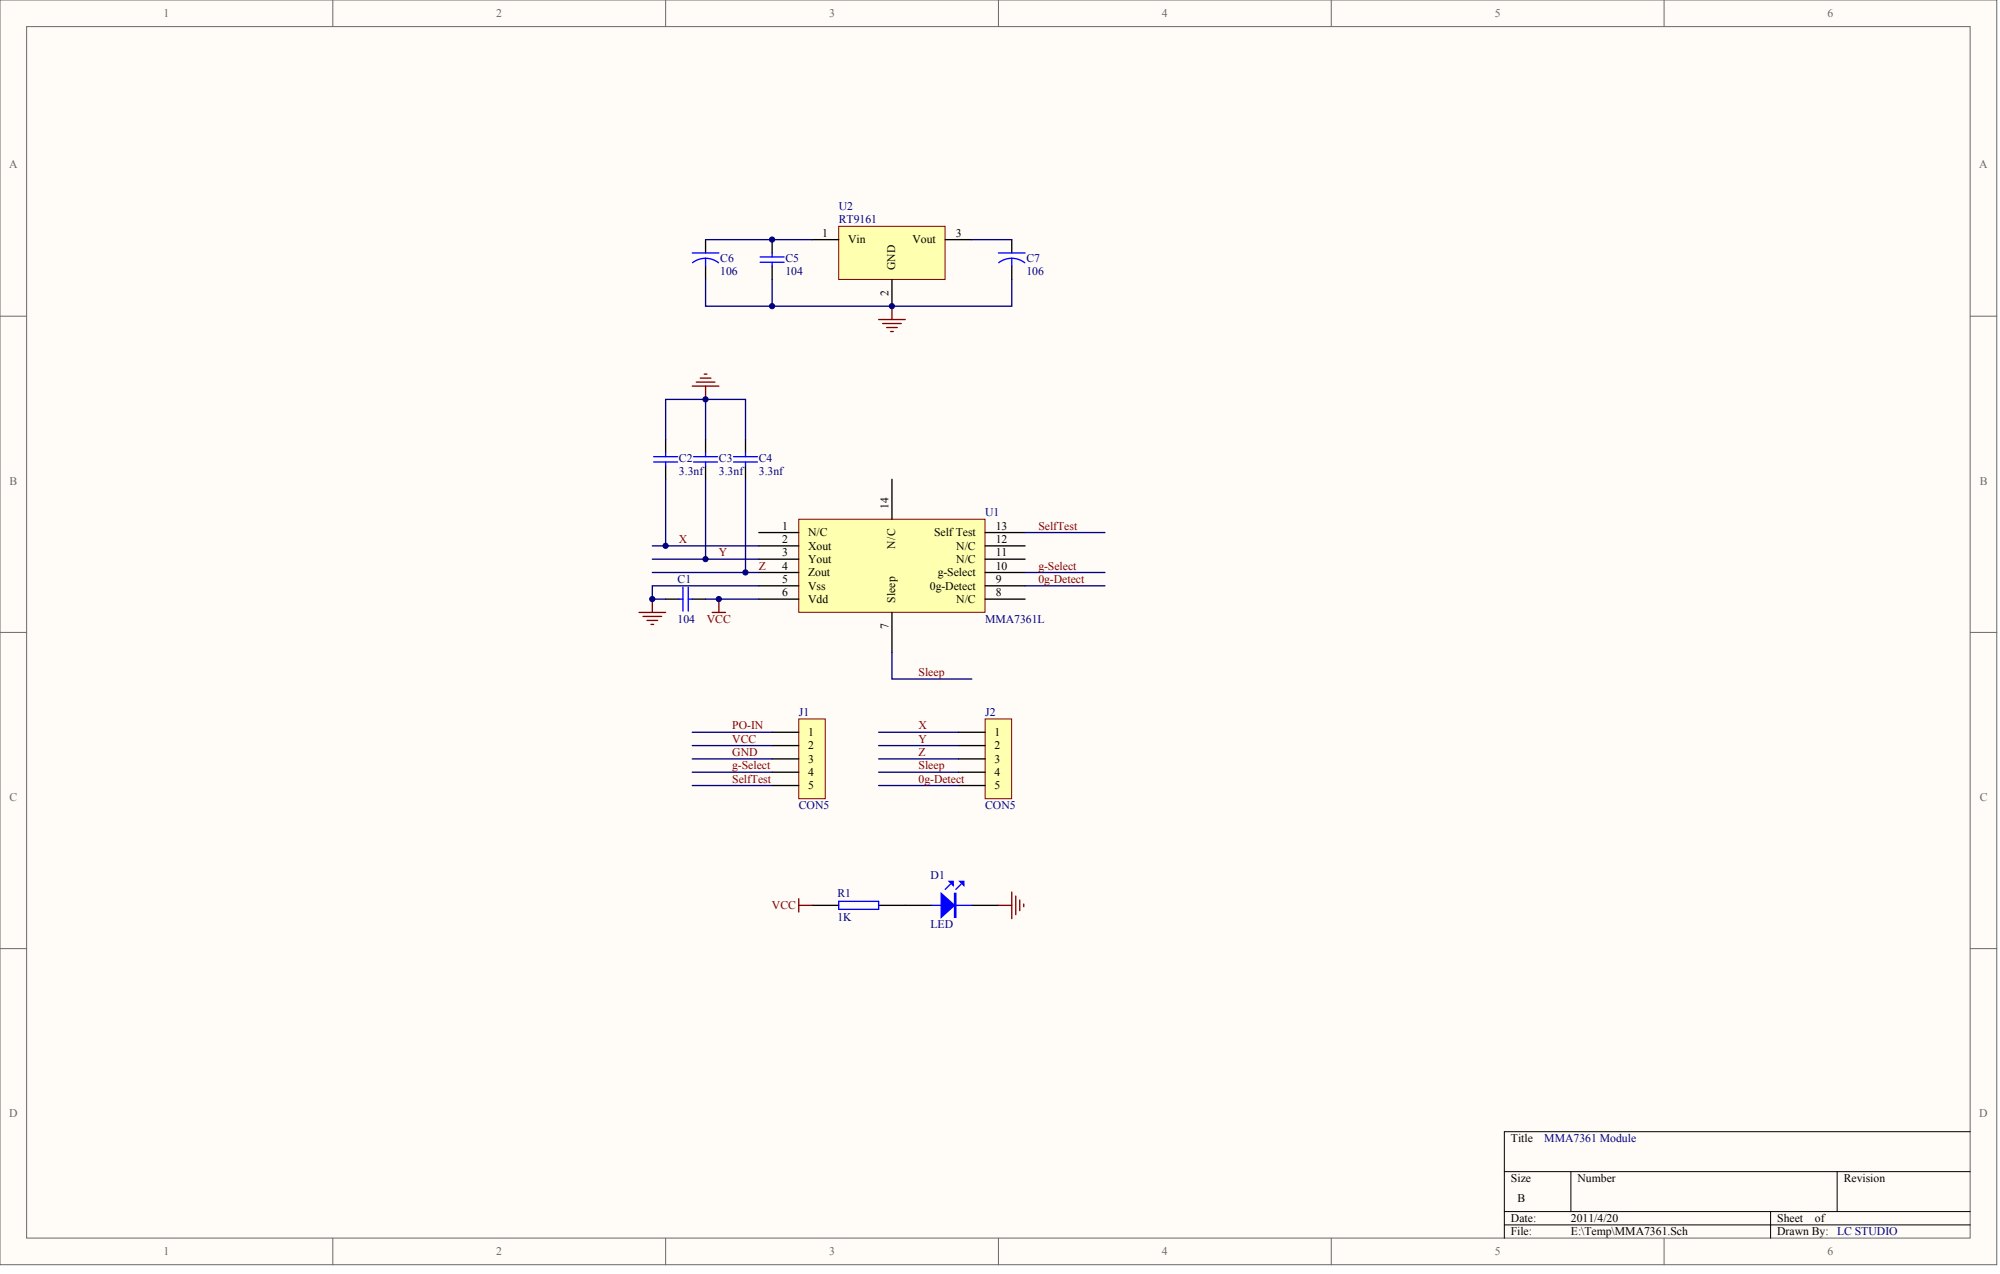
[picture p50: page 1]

Vss 5
P0U106 P0U106 P0U106 | Vdd 6

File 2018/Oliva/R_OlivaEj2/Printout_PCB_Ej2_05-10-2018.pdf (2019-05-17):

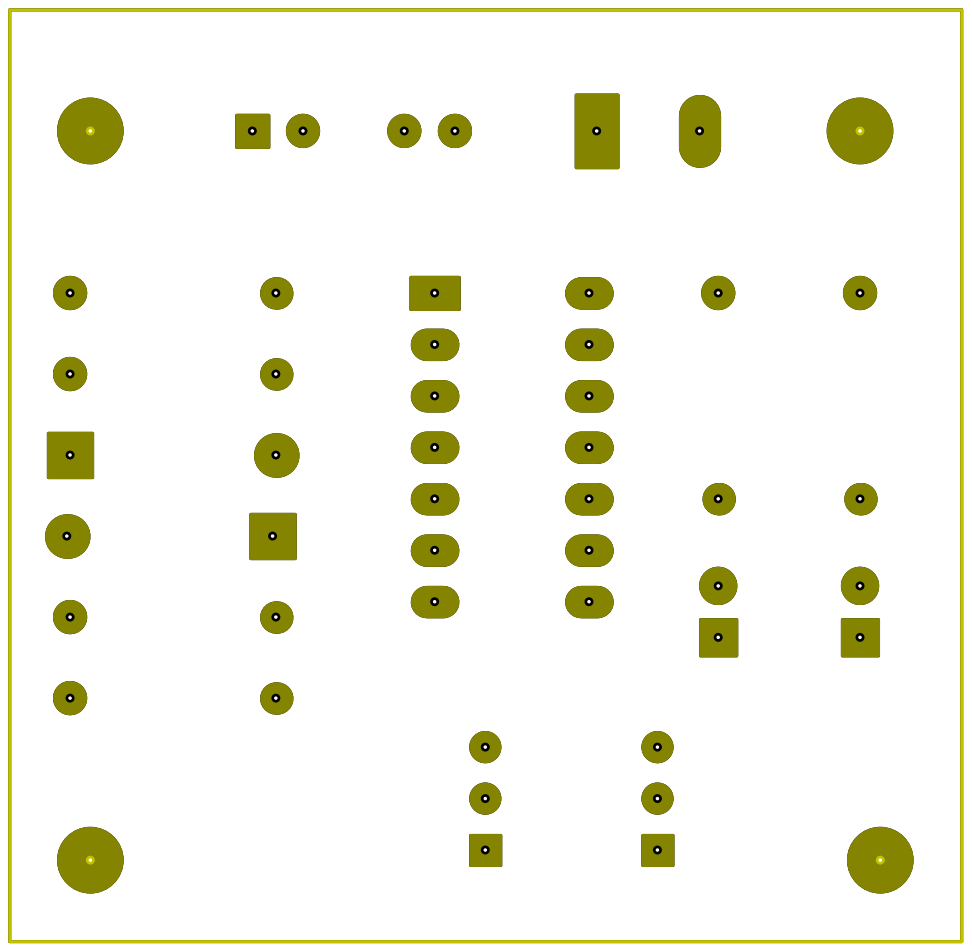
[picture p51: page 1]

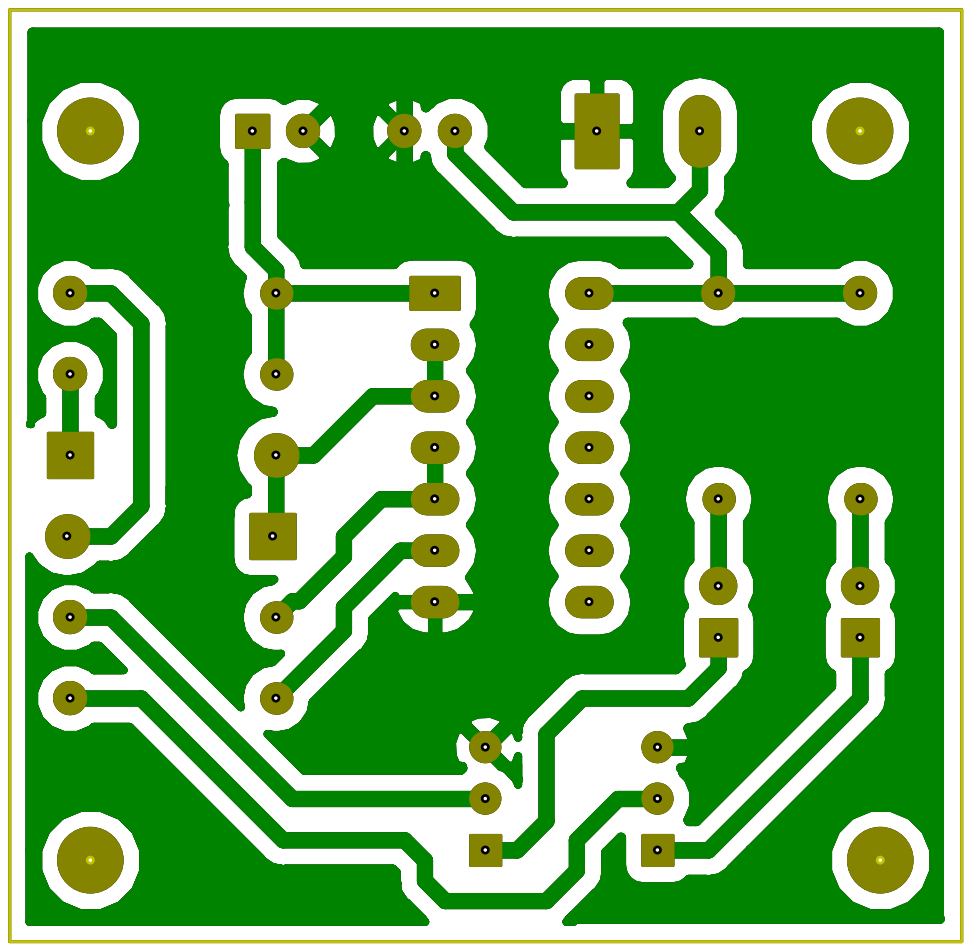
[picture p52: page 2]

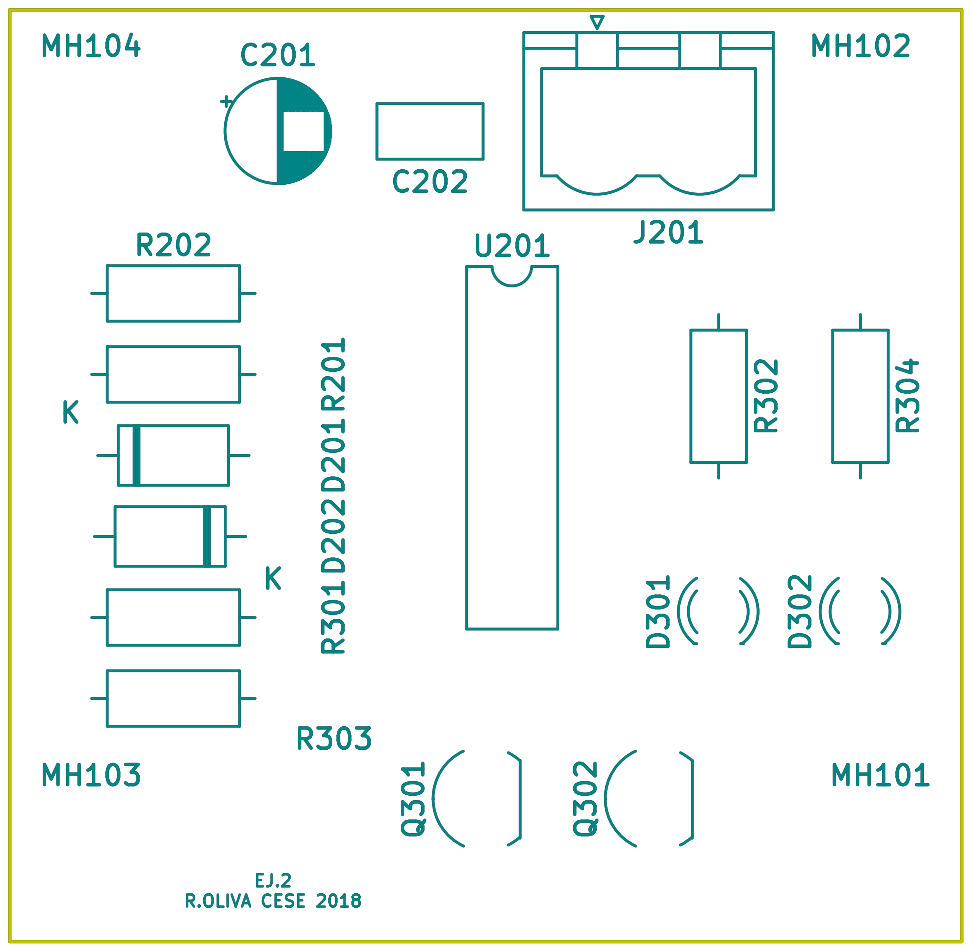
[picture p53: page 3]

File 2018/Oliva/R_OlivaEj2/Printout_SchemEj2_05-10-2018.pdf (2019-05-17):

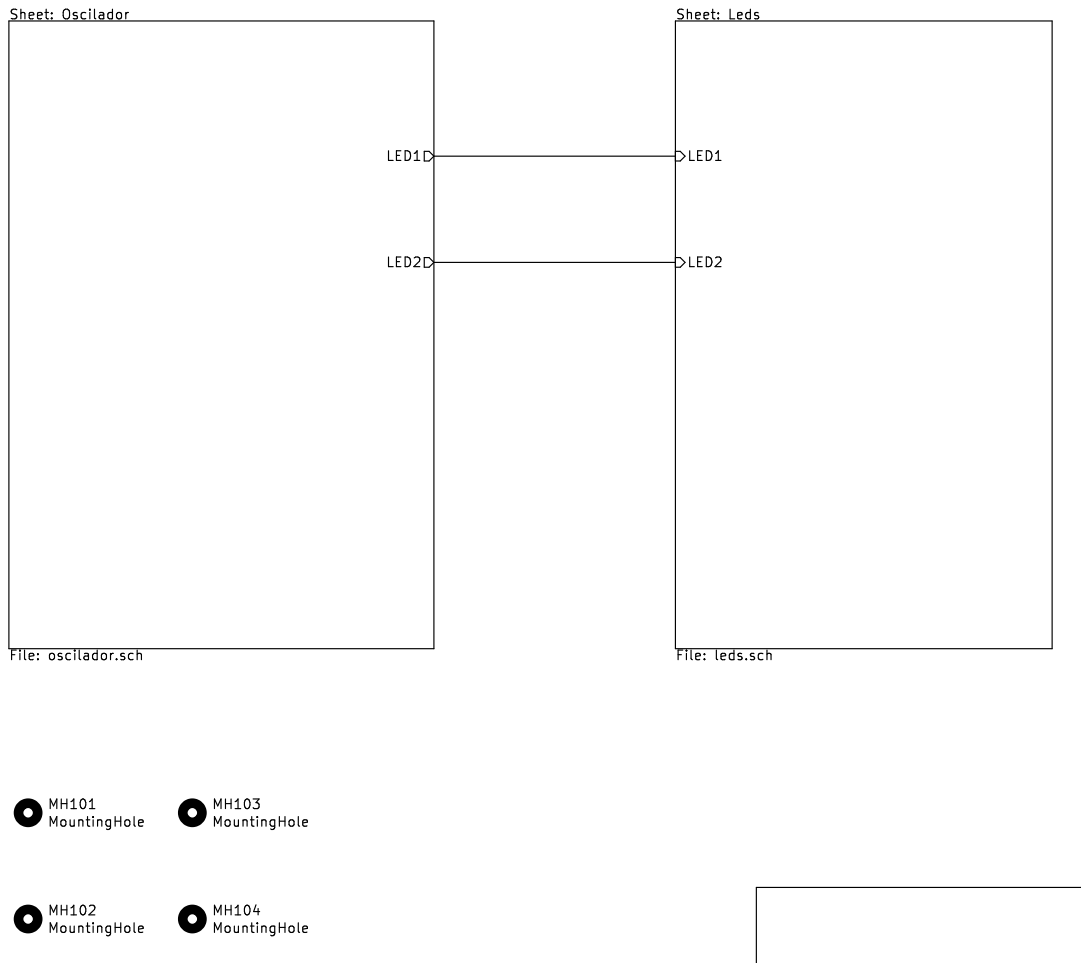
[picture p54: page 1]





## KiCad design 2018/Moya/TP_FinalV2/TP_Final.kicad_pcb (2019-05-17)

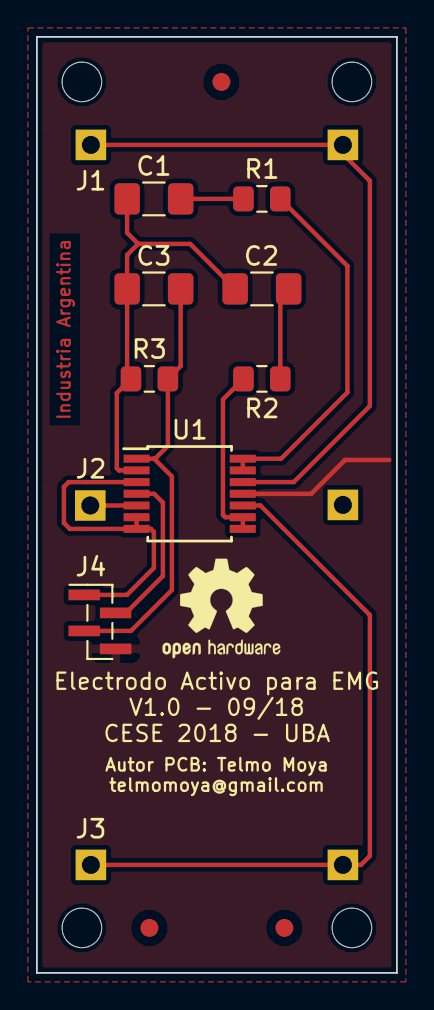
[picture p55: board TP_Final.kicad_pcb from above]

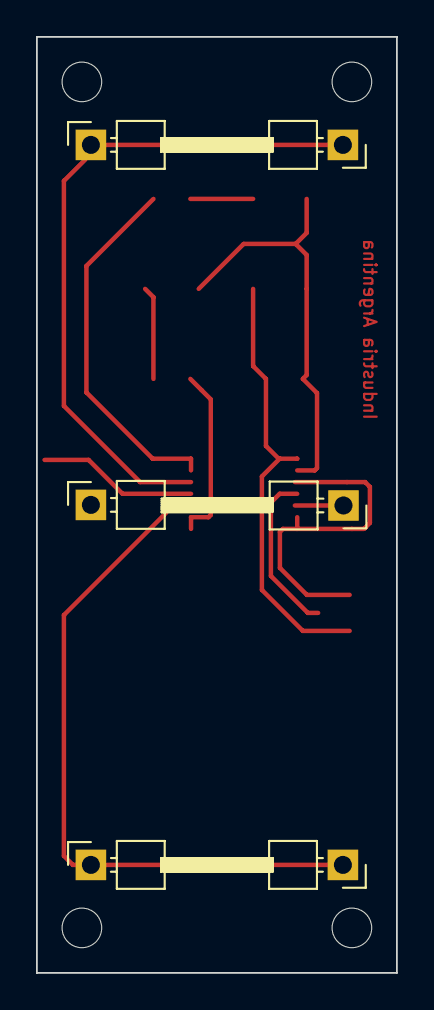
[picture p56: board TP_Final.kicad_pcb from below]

Board: 2 copper layers, 20.0 x 52.0 mm, 21 parts (6 on the bottom side), 12 nets.

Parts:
C1, C2: 10uF; C_1206_3216Metric_Pad1.42x1.75mm_HandSolder
C3: 32nF; C_1206_3216Metric_Pad1.42x1.75mm_HandSolder
F1, F2, F3: Fiducial; Fiducial_1mm_Dia_2mm_Outer
J1, J2, J3, J11, J22, J33: Conn_01x01_Male; PinHeader_1x01_P2.54mm_Horizontal
J4: Conn_01x04_Male; PinHeader_1x04_P1.00mm_Vertical_SMD_Pin1Left
MH1, MH2, MH3, MH4: MountingHole; MountingHole_2.2mm_M2
R1, R2: 1K; R_0805_2012Metric_Pad1.15x1.40mm_HandSolder
R3: 10K; R_0805_2012Metric_Pad1.15x1.40mm_HandSolder
U1: OPA4243; TSSOP-14_4.4x5mm_P0.65mm

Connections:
/Va: J1.1, J11.1, U1.12
/Vb: J2.1, U1.5
/Vc: J3.1, J33.1, U1.10
/Vo+: J4.1, U1.3, U1.6, U1.7
/Vo-: C3.2, J4.3, R3.2, U1.1
GND: J4.4, U1.11
unnamed: C1.1, C2.2, C3.1, R3.1, U1.2
unnamed: C1.2, R1.1
unnamed: C2.1, R2.1
unnamed: R1.2, U1.13, U1.14
unnamed: R2.2, U1.8, U1.9
VCC: J4.2, U1.4

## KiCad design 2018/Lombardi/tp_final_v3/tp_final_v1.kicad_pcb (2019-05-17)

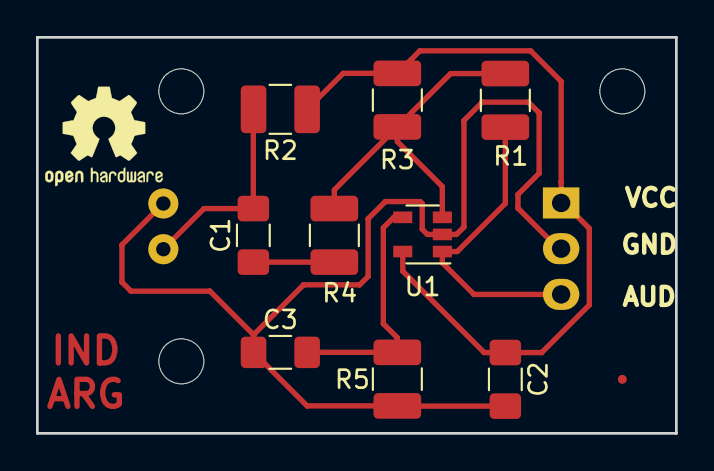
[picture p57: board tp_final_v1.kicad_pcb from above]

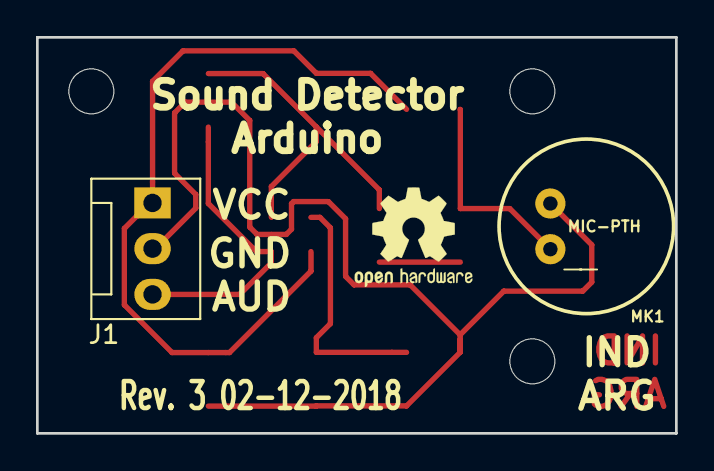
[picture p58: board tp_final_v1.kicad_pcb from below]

Board: 2 copper layers, 35.5 x 22.0 mm, 15 parts (2 on the bottom side), 7 nets.

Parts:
C1, C3: 4.7uF; C_1206_3216Metric_Pad1.42x1.75mm_HandSolder
C2: 0.1uF; C_1206_3216Metric_Pad1.42x1.75mm_HandSolder
J1: Conn_01x03; FanPinHeader_1x03_P2.54mm_Vertical
MH1, MH2, MH3: MountingHole; MountingHole_2.5mm
MH4: Fiducial; Fiducial_0.5mm_Dia_1mm_Outer
MK1: MIC-PTH; MICROPHONE-PTH-9.7MM
R1: 820k; R_1210_3225Metric_Pad1.42x2.65mm_HandSolder
R2: 2.2k; R_1210_3225Metric_Pad1.42x2.65mm_HandSolder
R3, R4, R5: 10k; R_1210_3225Metric_Pad1.42x2.65mm_HandSolder
U1: OPA340NA; SOT-23-5

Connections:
GND: C2.2, C3.1, J1.2, MK1.OUT, R5.2, U1.2
unnamed: C1.1, R4.2
unnamed: C1.2, MK1.GND, R2.2
unnamed: C3.2, R5.1, U1.4
unnamed: J1.3, R1.1, U1.1
unnamed: R1.2, R3.2, R4.1, U1.3
VCC: C2.1, J1.1, R2.1, R3.1, U1.5

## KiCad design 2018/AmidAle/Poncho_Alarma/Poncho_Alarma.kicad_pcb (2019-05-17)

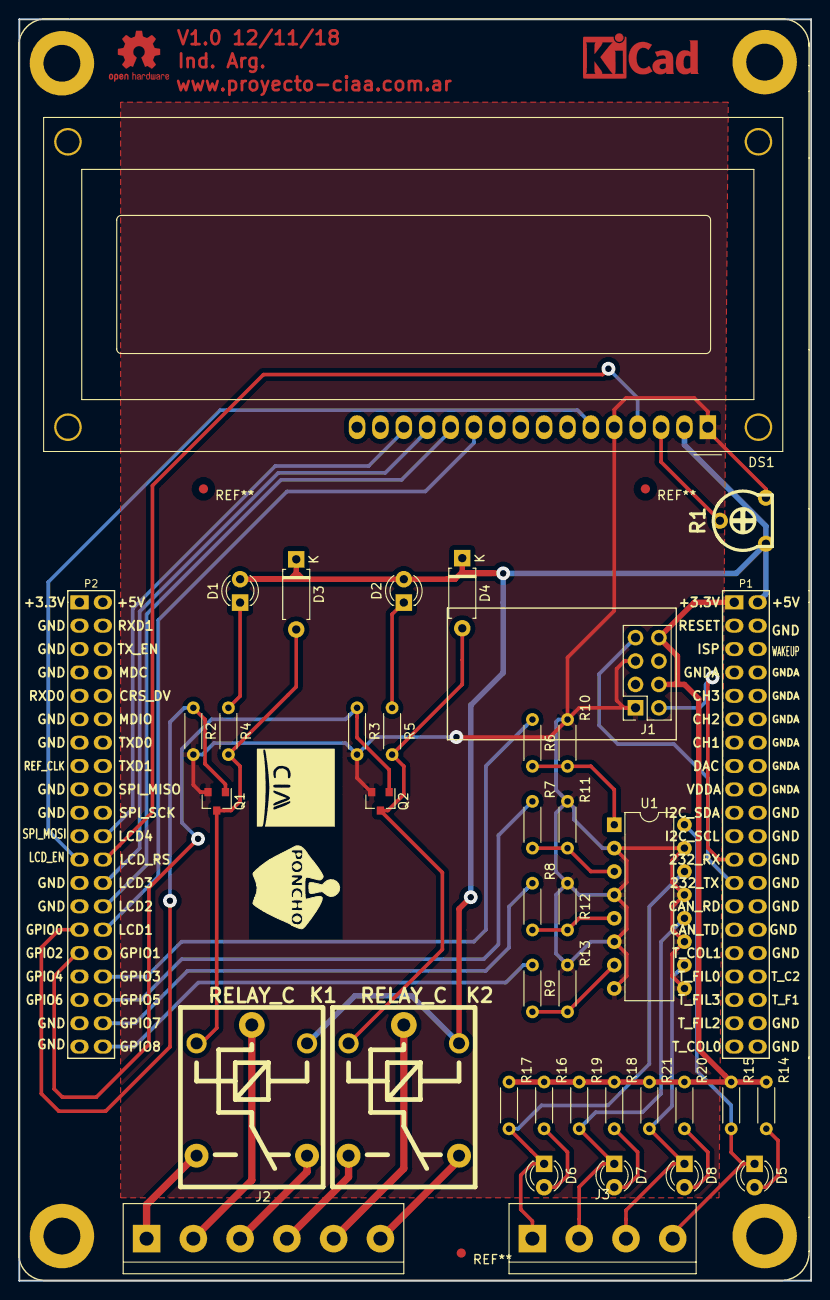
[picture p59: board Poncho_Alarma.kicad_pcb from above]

Board: 2 copper layers, 86.0 x 137.0 mm, 40 parts (0 on the bottom side), 40 nets.

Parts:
D1, D2, D5, D6, D7, D8: LED_Rojo; LED_D3.0mm
D3, D4: LL4148; D_A-405_P7.62mm_Horizontal
DS1: LCD16X2; WC1602A
G102: LOGO_CIAA; LOGO-CIAA
J1: ESP8266; ESP-01
J2: Salidas; TerminalBlock_bornier-6_P5.08mm
J3: Entradas; TerminalBlock_bornier-4_P5.08mm
K1, K2: RELAY_C; Relay_C
Q1, Q2: 2N7002; SOT-23
R1: 10K; TRIMER_V
R2, R3: 100k; R_Axial_DIN0204_L3.6mm_D1.6mm_P5.08mm_Horizontal
R4, R5: 330; R_Axial_DIN0204_L3.6mm_D1.6mm_P5.08mm_Horizontal
R6, R7, R8, R9: R_Small3.3K; R_Axial_DIN0204_L3.6mm_D1.6mm_P5.08mm_Horizontal
R10, R11, R12, R13: 4.7K; R_Axial_DIN0204_L3.6mm_D1.6mm_P5.08mm_Horizontal
R14, R16, R18, R20: 2.2K; R_Axial_DIN0204_L3.6mm_D1.6mm_P5.08mm_Horizontal
R15, R17, R19, R21: 100K; R_Axial_DIN0204_L3.6mm_D1.6mm_P5.08mm_Horizontal
U1: TLP627-4; DIP-16_W7.62mm
XA1: Conn_Poncho2P_2x_20x2; poncho_grande

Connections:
+3V3: J1.4, J1.8, R14.1, R15.1, R16.1, R17.1, R18.1, R19.1, R20.1, R21.1, XA1.1
+5V: D1.2, D2.2, D3.1, D4.1, DS1.2, K1.5, K2.5, R1.1, XA1.2
/Entradas/In_1: R7.1, XA1.76
/Entradas/In_2: R8.1, XA1.78
/Entradas/In_3: R9.1, XA1.80
/Entradas/In_4: R6.1, XA1.74
/Salidas/K1_C: J2.2, K1.1
/Salidas/K1_NA: J2.1, K1.3
/Salidas/K1_NC: J2.3, K1.4
/Salidas/K2_C: J2.5, K2.1
/Salidas/K2_NA: J2.4, K2.3
/Salidas/K2_NC: J2.6, K2.4
/Salidas/Out_1: Q1.1, R2.1, XA1.69
/Salidas/Out_2: Q2.1, R3.1, XA1.71
GND: DS1.1, DS1.5, J1.1, J1.5, Q1.2, Q2.2, R1.3, R2.2, R3.2, R10.1, R11.1, R12.1, R13.1, U1.2, U1.4, U1.6, U1.8, U1.9, U1.11, U1.13, U1.15
unnamed: D1.1, R4.1
unnamed: D2.1, R5.1
unnamed: D3.2, K1.2, Q1.3, R4.2
unnamed: D4.2, K2.2, Q2.3, R5.2
unnamed: D5.1, J3.4, R15.2, U1.16
unnamed: D5.2, R14.2
unnamed: D6.1, J3.1, R17.2, U1.14
unnamed: D6.2, R16.2
unnamed: D7.1, J3.2, R19.2, U1.12
unnamed: D7.2, R18.2
unnamed: D8.1, J3.3, R21.2, U1.10
unnamed: D8.2, R20.2
unnamed: DS1.3, R1.2
unnamed: DS1.4, XA1.64
unnamed: DS1.6, XA1.63
unnamed: DS1.11, XA1.70
unnamed: DS1.12, XA1.68
unnamed: DS1.13, XA1.66
unnamed: DS1.14, XA1.62
unnamed: J1.2, XA1.23
unnamed: J1.7, XA1.25
unnamed: R6.2, R10.2, U1.1
unnamed: R7.2, R11.2, U1.3
unnamed: R8.2, R12.2, U1.5
unnamed: R9.2, R13.2, U1.7

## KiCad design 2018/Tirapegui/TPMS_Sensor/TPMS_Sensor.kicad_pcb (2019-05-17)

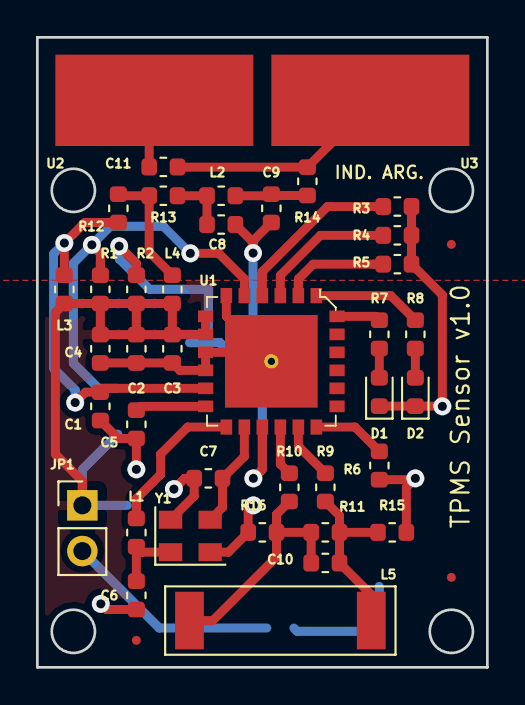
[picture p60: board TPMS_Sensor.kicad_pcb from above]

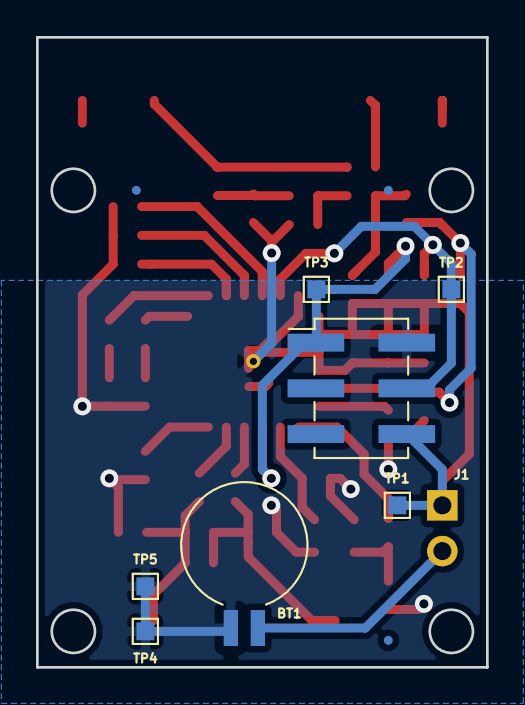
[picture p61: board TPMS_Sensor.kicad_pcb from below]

Board: 2 copper layers, 25.0 x 35.0 mm, 52 parts (10 on the bottom side), 27 nets.

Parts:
BT1: Battery_Cell; BatteryHolder_Seiko_MS621F
C1: 1.5pF; C_0603_1608Metric
C2: 0.1uF; C_0603_1608Metric
C3: 100pF; C_0603_1608Metric
C4, C8, C11: DNP; C_0603_1608Metric
C5: 0.47uF; C_0603_1608Metric
C6, C7: 10pF; C_0603_1608Metric
C9: 1pF; C_0603_1608Metric
C10: 220pF; C_0603_1608Metric
D1: LED_A; LED_0603_1608Metric
D2: LED_B; LED_0603_1608Metric
F1, F2, F3, F4, F5, F6: Fiducial; Fiducial_0.5mm_Dia_1mm_Outer
J1: Conn_02x03_Odd_Even; PinHeader_2x03_P2.54mm_Vertical_SMD
JP1: Jumper; PinHeader_1x02_P2.54mm_Vertical
L1: 10nH; L_0603_1608Metric
L2: 100nH; L_0603_1608Metric
L3: DNP; L_0603_1608Metric
L4: 39nH; L_0603_1608Metric
L5: 7.2mH; LFCoil_B82450A7204A000
R1, R2: 4k7; R_0603_1608Metric
R3, R4, R5, R6, R7, R8, R15, R16: DNP; R_0603_1608Metric
R9, R10, R12, R13, R14: 0; R_0603_1608Metric
R11: 10k; R_0603_1608Metric
TP1, TP2, TP3, TP4, TP5: TestPoint; TestPoint_Pad_1.0x1.0mm
U1: FXTH87xxxx; QFN-24_7x7mm
U2: PAD1; RF_Antenna_PAD
U3: PAD2; RF_Antenna_PAD
Y1: Xtal; Crystal_SMD_EuroQuartz_MT-4Pin_3.2x2.5mm

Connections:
+BATT: C2.1, C3.1, C4.1, J1.6, JP1.1, L3.2, L4.2, R1.2, R2.1, TP1.1, U1.7, U1.8
GND: BT1.2, C1.2, C2.2, C3.2, C4.2, C5.2, C6.2, C7.2, C8.2, C9.2, D1.1, D2.1, J1.2, R3.2, R4.2, R5.2, R6.2, R15.1, R16.1, TP4.1, TP5.1, U1.6, U1.9, U1.10, U1.25, Y1.2, Y1.4
unnamed: BT1.1, JP1.2
unnamed: C1.1, L3.1, R12.1, U1.11
unnamed: C5.1, U1.12
unnamed: C6.1, L1.2, Y1.1
unnamed: C7.1, U1.14, Y1.3
unnamed: C8.1, L2.1, R13.2
unnamed: C9.1, L2.2, R14.2
unnamed: C10.1, L5.2, R10.1, R11.1, R16.2
unnamed: C10.2, L5.1, R9.1, R11.2, R15.2
unnamed: C11.1, U2.1
unnamed: C11.2, R14.1, U3.1
unnamed: D1.2, R7.2
unnamed: D2.2, R8.2
unnamed: J1.1, R2.2, TP3.1, U1.15
unnamed: J1.4, R1.1, TP2.1, U1.5
unnamed: L1.1, U1.13
unnamed: L4.1, R12.2, R13.1
unnamed: R3.1, U1.4
unnamed: R4.1, U1.3
unnamed: R5.1, U1.2
unnamed: R6.1, U1.18
unnamed: R7.1, U1.24
unnamed: R8.1, U1.1
unnamed: R9.2, U1.17
unnamed: R10.2, U1.16

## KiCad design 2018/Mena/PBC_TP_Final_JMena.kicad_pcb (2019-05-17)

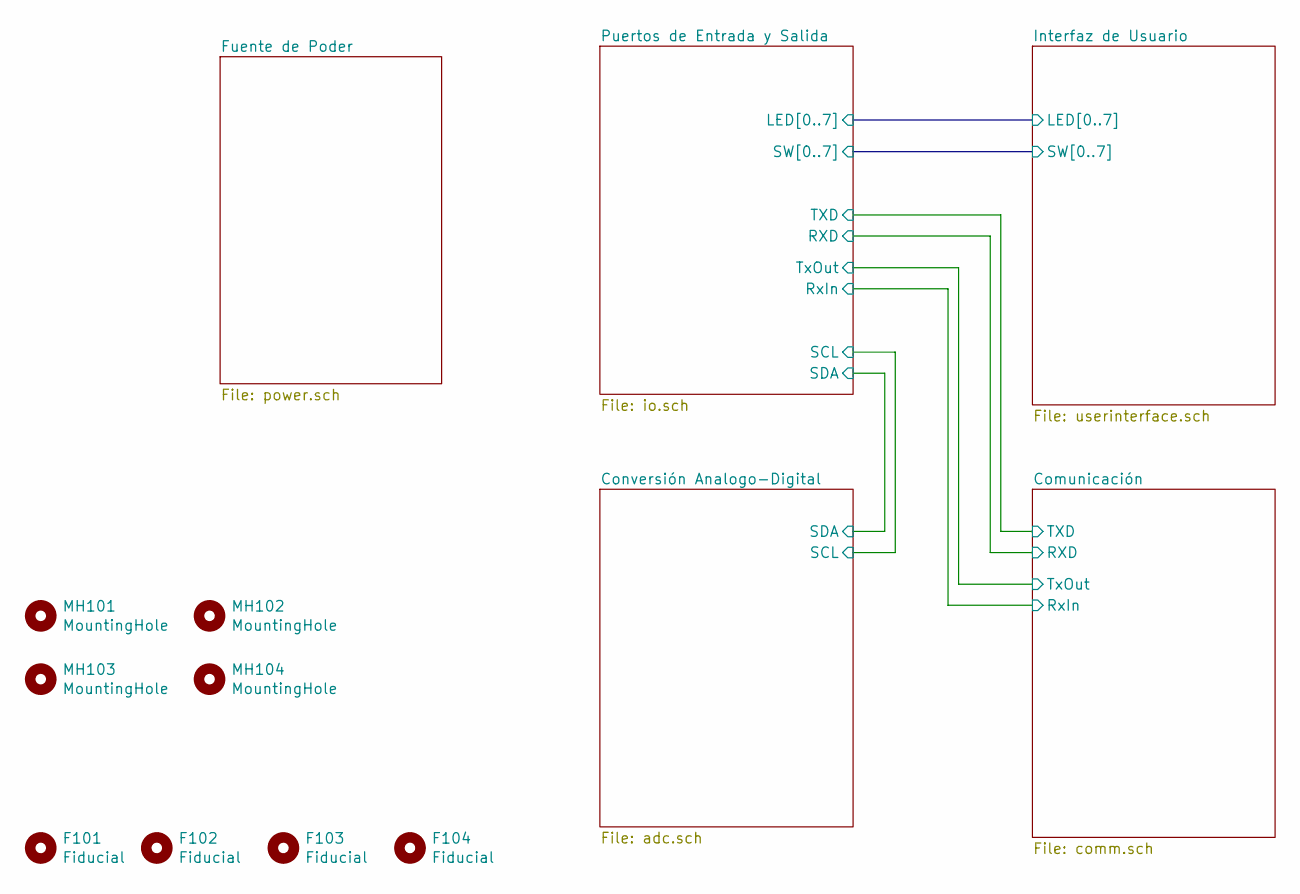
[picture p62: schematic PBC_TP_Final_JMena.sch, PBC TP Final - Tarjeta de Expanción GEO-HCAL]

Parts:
F101, F102, F103, F104: Fiducial; Fiducial_0.75mm_Dia_1.5mm_Outer
MH101, MH102, MH103, MH104: MountingHole; MountingHole_2.5mm

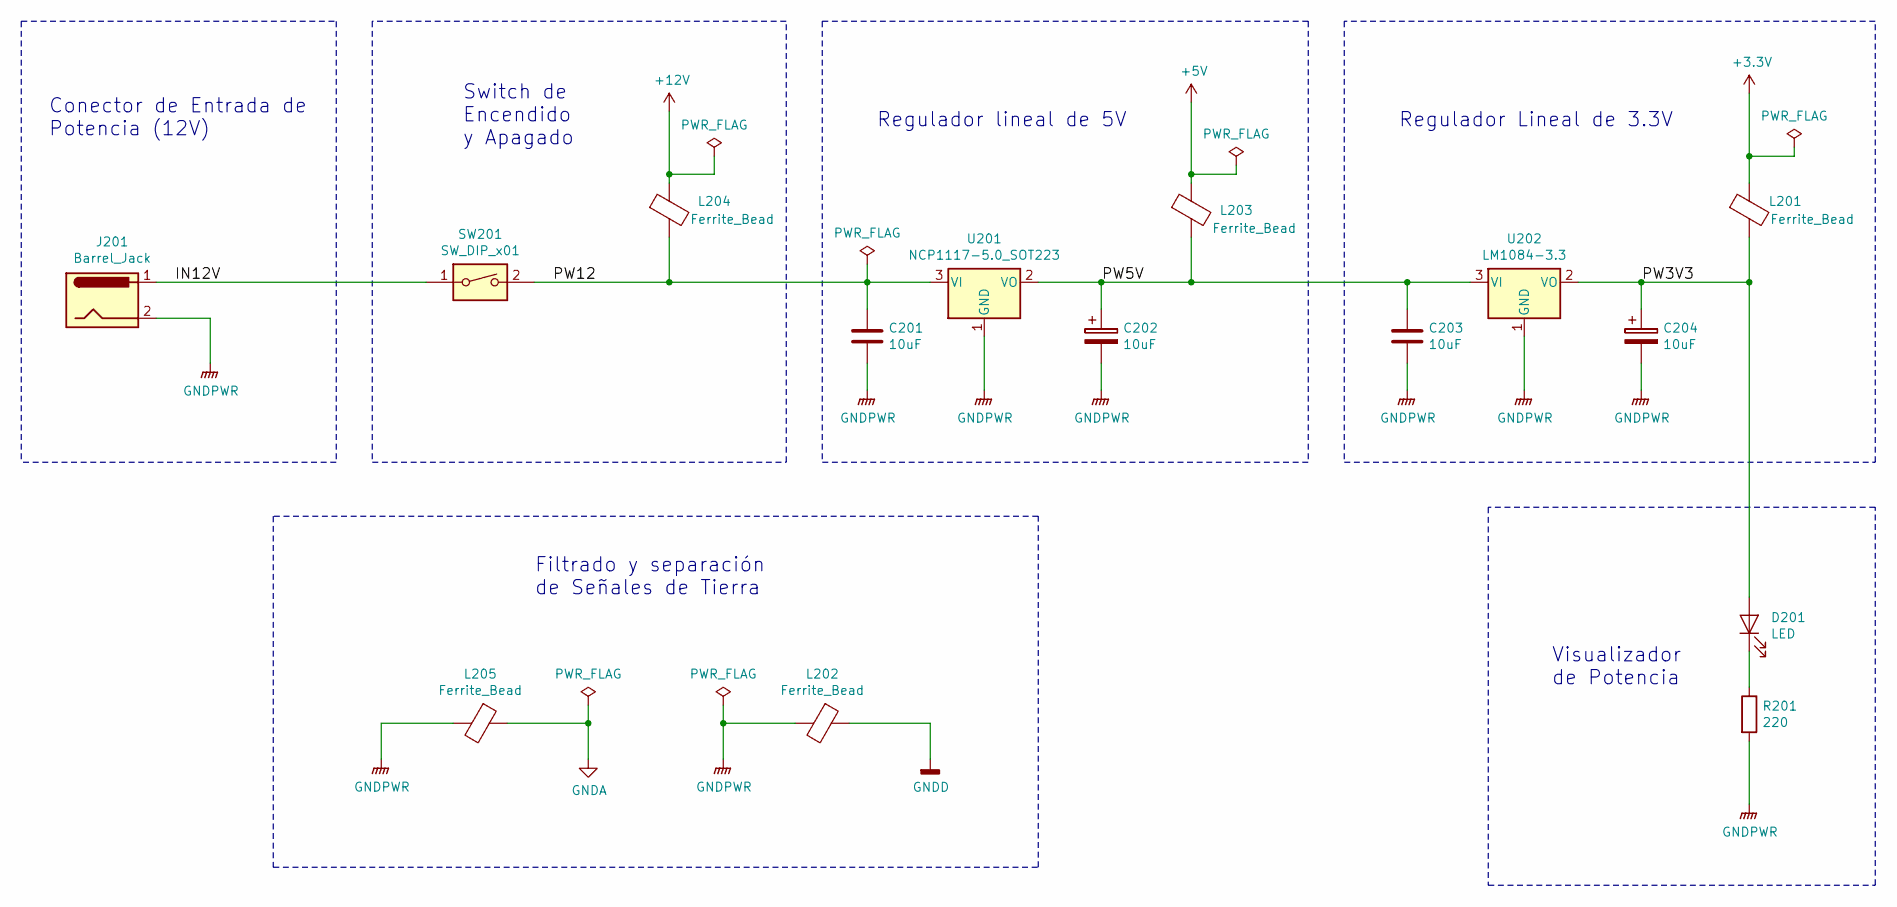
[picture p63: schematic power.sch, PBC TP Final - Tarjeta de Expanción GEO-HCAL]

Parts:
C201, C202, C203, C204: 10uF; C_1206_3216Metric_Pad1.42x1.75mm_HandSolder
D201: LED; LED_0805_2012Metric_Pad1.15x1.40mm_HandSolder
J201: Barrel_Jack; BarrelJack_CUI_PJ-063AH_Horizontal
L201, L202, L203, L204, L205: Ferrite_Bead; L_1206_3216Metric_Pad1.42x1.75mm_HandSolder
R201: 220; R_0805_2012Metric_Pad1.15x1.40mm_HandSolder
SW201: SW_DIP_x01; SW_SPST_EVQPE1
U201: NCP1117-5.0_SOT223; SOT-223-3_TabPin2
U202: LM1084-3.3; TO-263-3_TabPin2

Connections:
+5V: L203.1; also elsewhere on the board
+12V: L204.1; also elsewhere on the board
/Fuente de Poder/IN12V: J201.1, SW201.1
/Fuente de Poder/PW3V3: C204.1, D201.2 (A), L201.2, U202.2 (VO)
/Fuente de Poder/PW5V: C202.1, C203.1, L203.2, U201.2 (VO), U202.3 (VI)
/Fuente de Poder/PW12: C201.1, L204.2, SW201.2, U201.3 (VI)
GNDA: L205.1; also elsewhere on the board
GNDD: L202.1; also elsewhere on the board
GNDPWR: C201.2, C202.2, C203.2, C204.2, J201.2, L202.2, L205.2, R201.2, U201.1 (GND), U202.1 (GND)
unnamed: D201.1 (K), R201.1

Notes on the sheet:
Conector de Entrada de Potencia (12V)
Regulador lineal de 5V
Regulador Lineal de 3.3V
Visualizador de Potencia
Filtrado y separación de Señales de Tierra
Switch de Encendido y Apagado

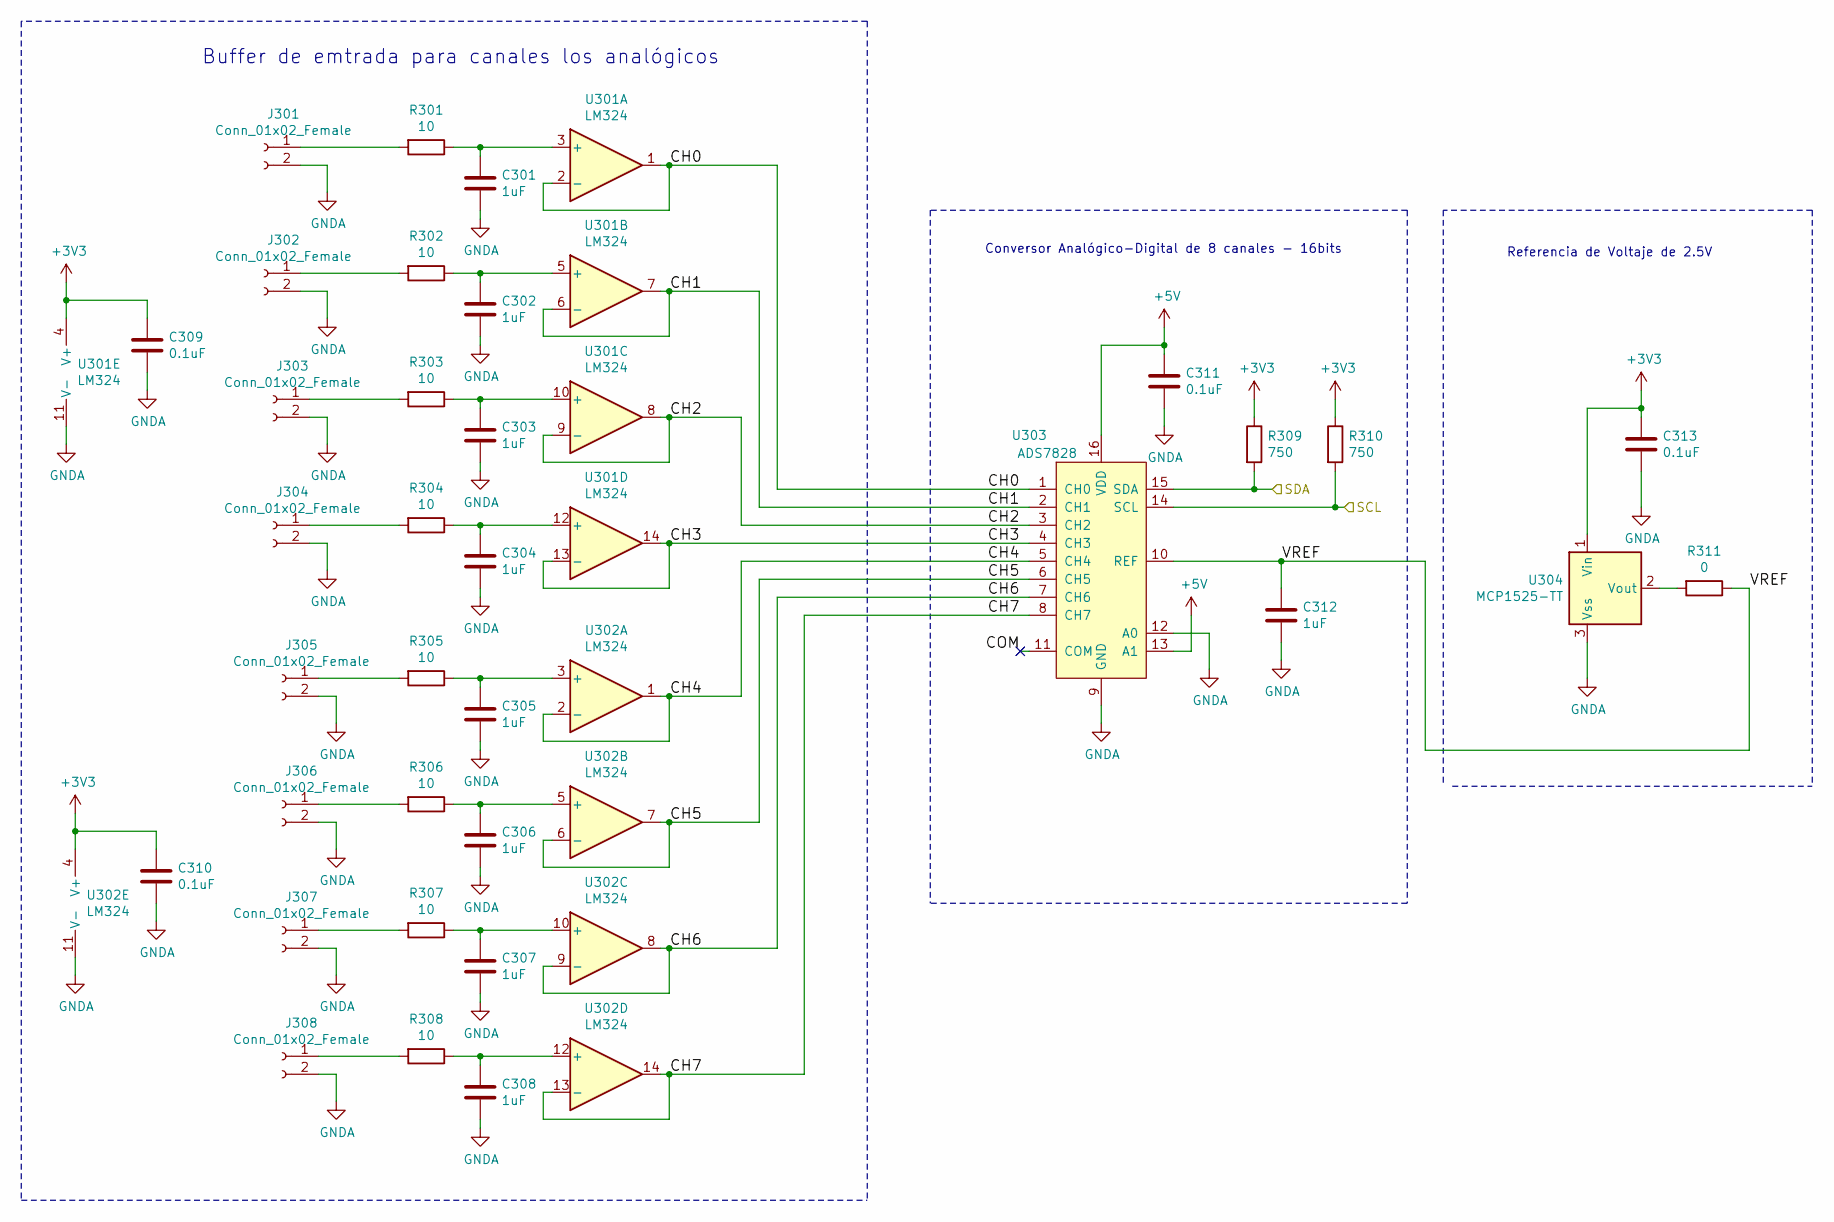
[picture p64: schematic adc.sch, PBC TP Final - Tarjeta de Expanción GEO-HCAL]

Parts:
C301, C302, C303, C304, C305, C306, C307, C308, C312: 1uF; C_0805_2012Metric_Pad1.15x1.40mm_HandSolder
C309, C310, C311, C313: 0.1uF; C_0805_2012Metric_Pad1.15x1.40mm_HandSolder
J301, J302, J303, J304, J305, J306, J307, J308: Conn_01x02_Female; PinHeader_1x02_P1.27mm_Vertical
R301, R302, R303, R304, R305, R306, R307, R308: 10; R_0805_2012Metric_Pad1.15x1.40mm_HandSolder
R309, R310: 750; R_0805_2012Metric_Pad1.15x1.40mm_HandSolder
R311: 0; R_0805_2012Metric_Pad1.15x1.40mm_HandSolder
U301, U302: LM324; SOIC-14_3.9x8.7mm_P1.27mm
U303: ADS7828; TSSOP-16_4.4x5mm_P0.65mm
U304: MCP1525-TT; SOT-23

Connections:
+5V: C311.1, U303.13 (A1), U303.16 (VDD); also elsewhere on the board
/Conversión Analogo-Digital/CH0: U301.1, U301.2 (-), U303.1 (CH0)
/Conversión Analogo-Digital/CH1: U301.6 (-), U301.7, U303.2 (CH1)
/Conversión Analogo-Digital/CH2: U301.8, U301.9 (-), U303.3 (CH2)
/Conversión Analogo-Digital/CH3: U301.13 (-), U301.14, U303.4 (CH3)
/Conversión Analogo-Digital/CH4: U302.1, U302.2 (-), U303.5 (CH4)
/Conversión Analogo-Digital/CH5: U302.6 (-), U302.7, U303.6 (CH5)
/Conversión Analogo-Digital/CH6: U302.8, U302.9 (-), U303.7 (CH6)
/Conversión Analogo-Digital/CH7: U302.13 (-), U302.14, U303.8 (CH7)
/Conversión Analogo-Digital/COM: U303.11 (COM)
/Conversión Analogo-Digital/SCL: R310.2, U303.14 (SCL); also elsewhere on the board
/Conversión Analogo-Digital/SDA: R309.2, U303.15 (SDA); also elsewhere on the board
/Conversión Analogo-Digital/VREF: C312.1, R311.1, U303.10 (REF)
GNDA: C301.2, C302.2, C303.2, C304.2, C305.2, C306.2, C307.2, C308.2, C309.2, C310.2, C311.2, C312.2, C313.2, J301.2, J302.2, J303.2, J304.2, J305.2, J306.2, J307.2, J308.2, U301.11 (V-), U302.11 (V-), U303.9 (GND), U303.12 (A0), U304.3 (Vss); also elsewhere on the board
unnamed: C301.1, R301.1, U301.3 (+)
unnamed: C302.1, R302.1, U301.5 (+)
unnamed: C303.1, R303.1, U301.10 (+)
unnamed: C304.1, R304.1, U301.12 (+)
unnamed: C305.1, R305.1, U302.3 (+)
unnamed: C306.1, R306.1, U302.5 (+)
unnamed: C307.1, R307.1, U302.10 (+)
unnamed: C308.1, R308.1, U302.12 (+)
unnamed: J301.1, R301.2
unnamed: J302.1, R302.2
unnamed: J303.1, R303.2
unnamed: J304.1, R304.2
unnamed: J305.1, R305.2
unnamed: J306.1, R306.2
unnamed: J307.1, R307.2
unnamed: J308.1, R308.2
unnamed: R311.2, U304.2 (Vout)

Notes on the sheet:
Buffer de emtrada para canales los analógicos
Conversor Analógico-Digital de 8 canales - 16bits
Referencia de Voltaje de 2.5V

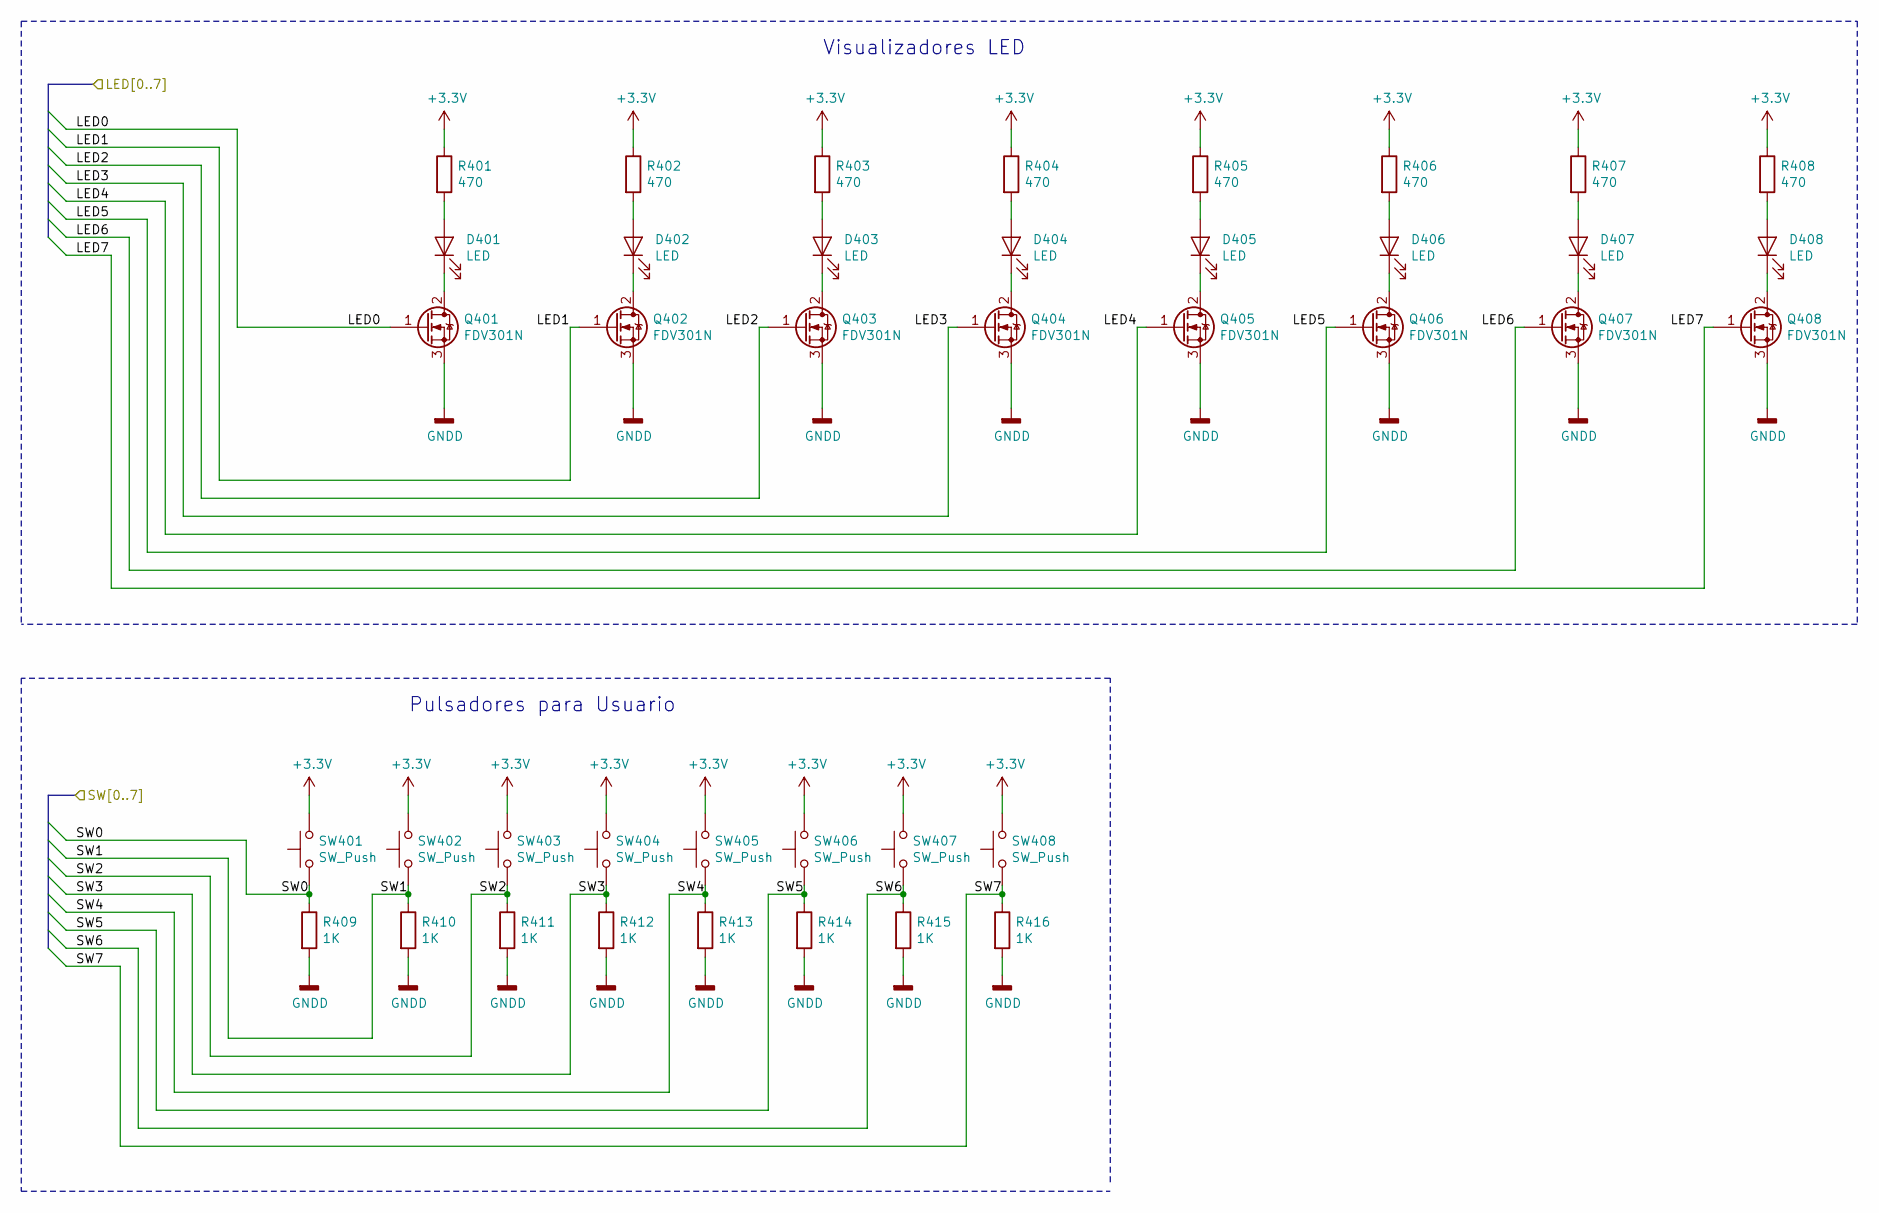
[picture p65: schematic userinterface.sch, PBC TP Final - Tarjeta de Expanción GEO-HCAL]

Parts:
D401, D402, D403, D404, D405, D406, D407, D408: LED; LED_0805_2012Metric_Pad1.15x1.40mm_HandSolder
Q401, Q402, Q403, Q404, Q405, Q406, Q407, Q408: FDV301N; SOT-23
R401, R402, R403, R404, R405, R406, R407, R408: 470; R_0805_2012Metric_Pad1.15x1.40mm_HandSolder
R409, R410, R411, R412, R413, R414, R415, R416: 1K; R_0805_2012Metric_Pad1.15x1.40mm_HandSolder
SW401, SW402, SW403, SW404, SW405, SW406, SW407, SW408: SW_Push; SW_SPST_B3U-1000P

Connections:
/Interfaz de Usuario/LED0: Q401.1 (G); also elsewhere on the board
/Interfaz de Usuario/LED1: Q402.1 (G); also elsewhere on the board
/Interfaz de Usuario/LED2: Q403.1 (G); also elsewhere on the board
/Interfaz de Usuario/LED3: Q404.1 (G); also elsewhere on the board
/Interfaz de Usuario/LED4: Q405.1 (G); also elsewhere on the board
/Interfaz de Usuario/LED5: Q406.1 (G); also elsewhere on the board
/Interfaz de Usuario/LED6: Q407.1 (G); also elsewhere on the board
/Interfaz de Usuario/LED7: Q408.1 (G); also elsewhere on the board
/Interfaz de Usuario/SW0: R409.1, SW401.1; also elsewhere on the board
/Interfaz de Usuario/SW1: R410.1, SW402.1; also elsewhere on the board
/Interfaz de Usuario/SW2: R411.1, SW403.1; also elsewhere on the board
/Interfaz de Usuario/SW3: R412.1, SW404.1; also elsewhere on the board
/Interfaz de Usuario/SW4: R413.1, SW405.1; also elsewhere on the board
/Interfaz de Usuario/SW5: R414.1, SW406.1; also elsewhere on the board
/Interfaz de Usuario/SW6: R415.1, SW407.1; also elsewhere on the board
/Interfaz de Usuario/SW7: R416.1, SW408.1; also elsewhere on the board
GNDD: Q401.3 (S), Q402.3 (S), Q403.3 (S), Q404.3 (S), Q405.3 (S), Q406.3 (S), Q407.3 (S), Q408.3 (S), R409.2, R410.2, R411.2, R412.2, R413.2, R414.2, R415.2, R416.2; also elsewhere on the board
unnamed: D401.1 (K), Q401.2 (D)
unnamed: D401.2 (A), R401.2
unnamed: D402.1 (K), Q402.2 (D)
unnamed: D402.2 (A), R402.2
unnamed: D403.1 (K), Q403.2 (D)
unnamed: D403.2 (A), R403.2
unnamed: D404.1 (K), Q404.2 (D)
unnamed: D404.2 (A), R404.2
unnamed: D405.1 (K), Q405.2 (D)
unnamed: D405.2 (A), R405.2
unnamed: D406.1 (K), Q406.2 (D)
unnamed: D406.2 (A), R406.2
unnamed: D407.1 (K), Q407.2 (D)
unnamed: D407.2 (A), R407.2
unnamed: D408.1 (K), Q408.2 (D)
unnamed: D408.2 (A), R408.2

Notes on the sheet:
Visualizadores LED
Pulsadores para Usuario

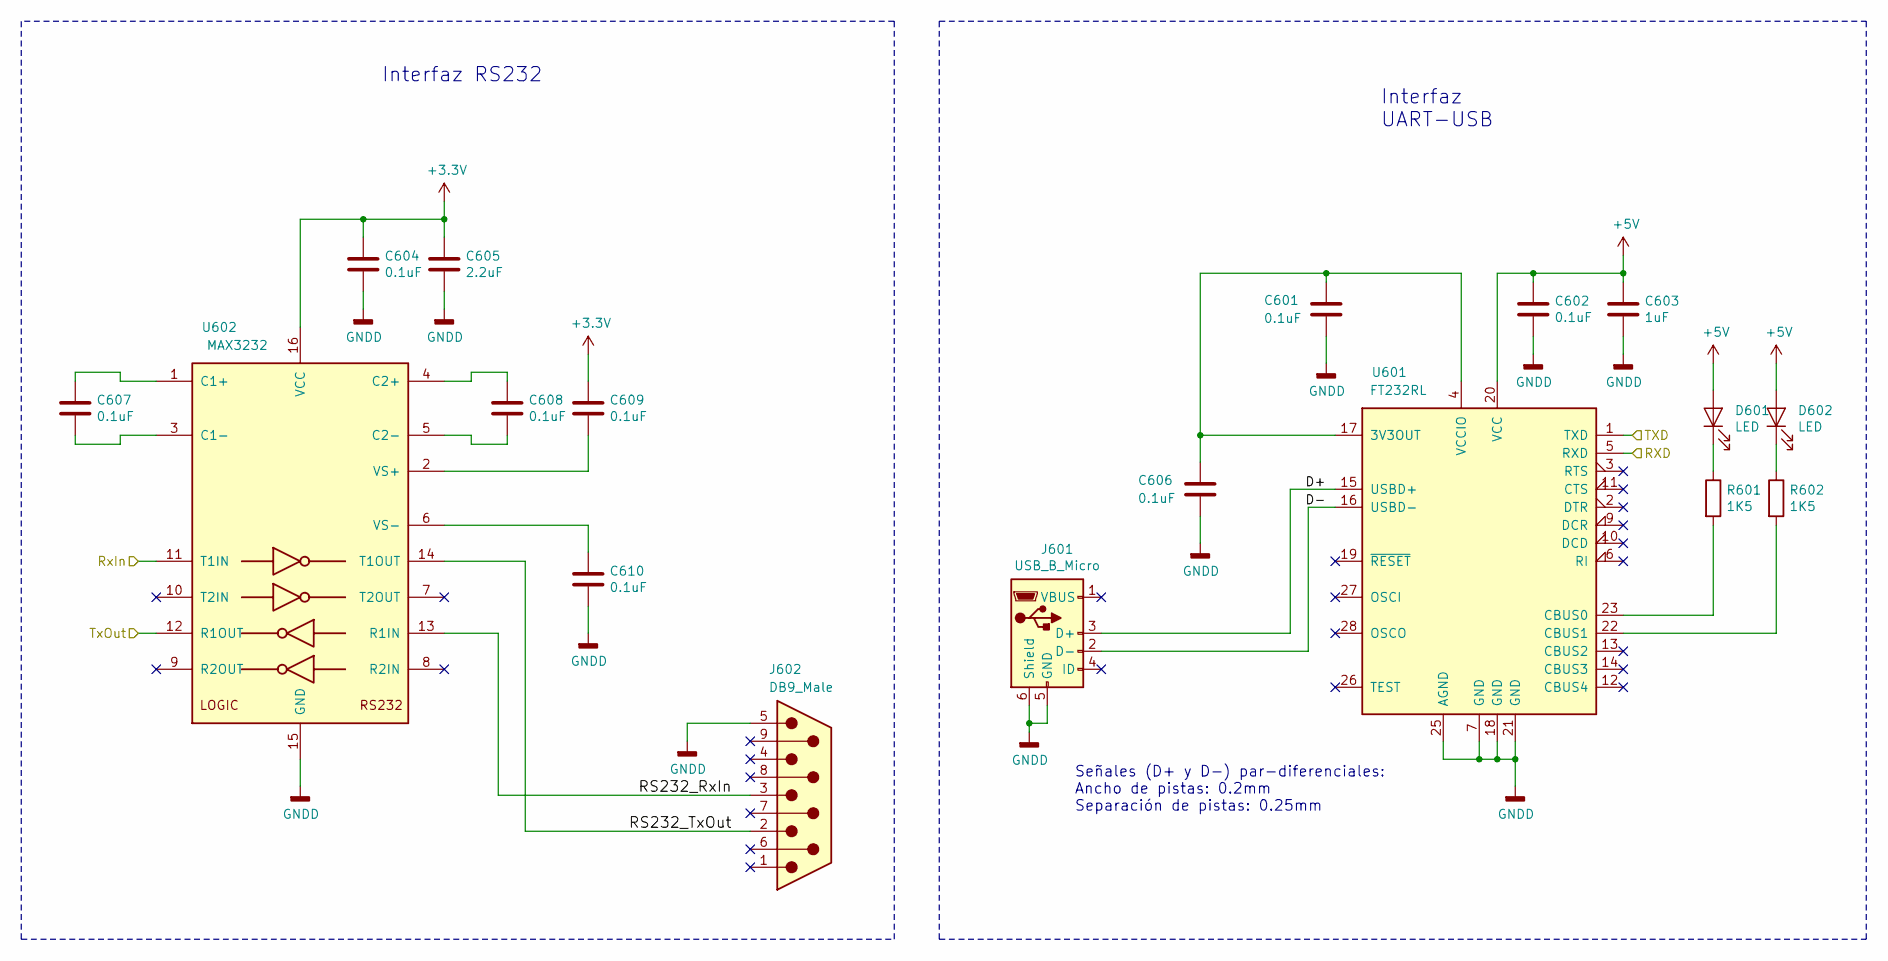
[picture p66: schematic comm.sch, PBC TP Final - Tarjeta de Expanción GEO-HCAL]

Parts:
C601, C602, C604, C606, C607, C608, C609, C610: 0.1uF; C_0805_2012Metric_Pad1.15x1.40mm_HandSolder
C603: 1uF; C_0805_2012Metric_Pad1.15x1.40mm_HandSolder
C605: 2.2uF; C_1206_3216Metric_Pad1.42x1.75mm_HandSolder
D601, D602: LED; LED_0805_2012Metric_Pad1.15x1.40mm_HandSolder
J601: USB_B_Micro; USB_Micro-B_Molex_47346-0001
J602: DB9_Male; DSUB-9_Male_Horizontal_P2.77x2.84mm_EdgePinOffset4.94mm_Hou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
R601, R602: 1K5; R_0805_2012Metric_Pad1.15x1.40mm_HandSolder
U601: FT232RL; SSOP-28_5.3x10.2mm_P0.65mm
U602: MAX3232; SOIC-16_3.9x9.9mm_P1.27mm

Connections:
+5V: C602.1, C603.1, D601.2 (A), D602.2 (A), U601.20 (VCC); also elsewhere on the board
/Comunicación/D+: J601.3 (D+), U601.15 (USBD+)
/Comunicación/D-: J601.2 (D-), U601.16 (USBD-)
/Comunicación/RS232_RxIn: J602.3, U602.13 (R1IN)
/Comunicación/RS232_TxOut: J602.2, U602.14 (T1OUT)
/Comunicación/RXD: U601.5 (RXD); also elsewhere on the board
/Comunicación/RxIn: U602.11 (T1IN); also elsewhere on the board
/Comunicación/TXD: U601.1 (TXD); also elsewhere on the board
/Comunicación/TxOut: U602.12 (R1OUT); also elsewhere on the board
GNDD: C601.2, C602.2, C603.2, C604.2, C605.2, C606.2, C610.2, J601.5 (GND), J601.6 (Shield), J602.5, U601.7 (GND), U601.18 (GND), U601.21 (GND), U601.25 (AGND), U602.15 (GND); also elsewhere on the board
unnamed: C601.1, C606.1, U601.4 (VCCIO), U601.17 (3V3OUT)
unnamed: C607.1, U602.1 (C1+)
unnamed: C607.2, U602.3 (C1-)
unnamed: C608.1, U602.4 (C2+)
unnamed: C608.2, U602.5 (C2-)
unnamed: C609.2, U602.2 (VS+)
unnamed: C610.1, U602.6 (VS-)
unnamed: D601.1 (K), R601.1
unnamed: D602.1 (K), R602.1
unnamed: R601.2, U601.23 (CBUS0)
unnamed: R602.2, U601.22 (CBUS1)

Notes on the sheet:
Interfaz RS232
Interfaz UART-USB
Señales (D+ y D-) par-diferenciales: Ancho de pistas: 0.2mm Separación de pistas: 0.25mm

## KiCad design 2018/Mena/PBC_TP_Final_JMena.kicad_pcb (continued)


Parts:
D501, D502, D503, D504, D505, D506, D507, D508: D_Schottky; D_0805_2012Metric_Pad1.15x1.40mm_HandSolder
J501, J502: Conn_01x40_Male; PinHeader_2x20_P1.00mm_Vertical
J503: Conn_01x06_Male; PinHeader_1x06_P1.27mm_Vertical
J504, J505: Conn_01x04; PinHeader_1x04_P1.27mm_Vertical
Q501, Q502, Q503, Q504, Q505, Q506, Q507, Q508: FDV301N; SOT-23
R501, R502, R503, R504, R505, R506, R507, R508, R509, R510, R511, R512: 1K; R_0805_2012Metric_Pad1.15x1.40mm_HandSolder

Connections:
+5V: D501.1 (K), D502.1 (K), D503.1 (K), D504.1 (K), J503.1; also elsewhere on the board
+12V: D505.1 (K), D506.1 (K), D507.1 (K), D508.1 (K), J504.1, J505.1; also elsewhere on the board
/Comunicación/RXD: J502.14; also elsewhere on the board
/Comunicación/RxIn: J502.12; also elsewhere on the board
/Comunicación/TXD: J502.16; also elsewhere on the board
/Comunicación/TxOut: J502.10; also elsewhere on the board
/Conversión Analogo-Digital/SCL: J502.19; also elsewhere on the board
/Conversión Analogo-Digital/SDA: J502.21; also elsewhere on the board
/Interfaz de Usuario/LED0: J501.2; also elsewhere on the board
/Interfaz de Usuario/LED1: J501.4; also elsewhere on the board
/Interfaz de Usuario/LED2: J501.6; also elsewhere on the board
/Interfaz de Usuario/LED3: J501.8; also elsewhere on the board
/Interfaz de Usuario/LED4: J501.10; also elsewhere on the board
/Interfaz de Usuario/LED5: J501.12; also elsewhere on the board
/Interfaz de Usuario/LED6: J501.14; also elsewhere on the board
/Interfaz de Usuario/LED7: J501.16; also elsewhere on the board
/Interfaz de Usuario/SW0: J501.31; also elsewhere on the board
/Interfaz de Usuario/SW1: J501.29; also elsewhere on the board
/Interfaz de Usuario/SW2: J501.27; also elsewhere on the board
/Interfaz de Usuario/SW3: J501.25; also elsewhere on the board
/Interfaz de Usuario/SW4: J501.23; also elsewhere on the board
/Interfaz de Usuario/SW5: J501.21; also elsewhere on the board
/Interfaz de Usuario/SW6: J501.19; also elsewhere on the board
/Interfaz de Usuario/SW7: J501.17; also elsewhere on the board
/Puertos de Entrada y Salida/CL0: J502.2, R505.2
/Puertos de Entrada y Salida/CL1: J502.6, R507.2
/Puertos de Entrada y Salida/CLOSE0: D505.2 (A), J504.2, Q505.2 (D)
/Puertos de Entrada y Salida/CLOSE1: D507.2 (A), J505.2, Q507.2 (D)
/Puertos de Entrada y Salida/OP0: J502.4, R506.2
/Puertos de Entrada y Salida/OP1: J502.8, R508.2
/Puertos de Entrada y Salida/OPEN0: D506.2 (A), J504.3, Q506.2 (D)
/Puertos de Entrada y Salida/OPEN1: D508.2 (A), J505.3, Q508.2 (D)
/Puertos de Entrada y Salida/PWM0: J502.25, Q501.1 (G), R501.2
/Puertos de Entrada y Salida/PWM1: J502.27, Q502.1 (G), R502.2
/Puertos de Entrada y Salida/PWM2: J502.29, Q503.1 (G), R503.2
/Puertos de Entrada y Salida/PWM3: J502.31, Q504.1 (G), R504.2
/Puertos de Entrada y Salida/PWM_OUT0: D501.2 (A), J503.3, Q501.2 (D)
/Puertos de Entrada y Salida/PWM_OUT1: D502.2 (A), J503.4, Q502.2 (D)
/Puertos de Entrada y Salida/PWM_OUT2: D503.2 (A), J503.5, Q503.2 (D)
/Puertos de Entrada y Salida/PWM_OUT3: D504.2 (A), J503.6, Q504.2 (D)
GNDD: J501.35, J501.36, J501.37, J501.38, J502.35, J502.36, J502.37, J502.38, J503.2, J504.4, J505.4, Q501.3 (S), Q502.3 (S), Q503.3 (S), Q504.3 (S), Q505.3 (S), Q506.3 (S), Q507.3 (S), Q508.3 (S), R509.2, R510.2, R511.2, R512.2; also elsewhere on the board
unnamed: Q505.1 (G), R505.1, R509.1
unnamed: Q506.1 (G), R506.1, R510.1
unnamed: Q507.1 (G), R507.1, R511.1
unnamed: Q508.1 (G), R508.1, R512.1

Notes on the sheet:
Puertos de conexión a la board Principal
Salidas de PWM a 5V
Salidas de control de apertura y cierre de Relays de potencia a 12V

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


Board: 2 copper layers, 60.0 x 96.0 mm, 150 parts (53 on the bottom side), 110 nets.

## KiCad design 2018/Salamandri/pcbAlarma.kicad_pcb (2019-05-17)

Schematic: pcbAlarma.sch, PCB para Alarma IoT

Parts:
F1, F2, F3: Fiducial; Fiducial_1mm_Dia_2mm_Outer
H1, H2, H3: MountingHole; MountingHole_2.2mm_M2
J101: PinMachoSensor; PinHeader_1x02_P2.54mm_Vertical
J102: TiraDePinesHembra; PinSocket_1x06_P2.54mm_Vertical
R3: 180; R_Axial_DIN0207_L6.3mm_D2.5mm_P10.16mm_Horizontal
U2: ESP32-WROOM; ESP32-WROOM-32

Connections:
+3V3: J102.2, R3.2, U2.2; also elsewhere on the board
/EN: J102.3, R3.1, U2.3
/GPIO0: J102.6, U2.25
/Salidas/LedControl: U2.30; also elsewhere on the board
/Salidas/LedStatus: U2.31; also elsewhere on the board
/Salidas/RelayIN: U2.32; also elsewhere on the board
GND: J101.1, J102.1, U2.1; also elsewhere on the board
unnamed: J101.2, U2.37
unnamed: J102.4, U2.34
unnamed: J102.5, U2.35

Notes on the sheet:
Programacion de Microcontrolador

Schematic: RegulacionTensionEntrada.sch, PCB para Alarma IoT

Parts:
C1, C2: 10uF; CP_Radial_D5.0mm_P2.50mm
D1: LED; LED_D3.0mm
J1: USB_B_Mcro
R1: 180; R_Axial_DIN0207_L6.3mm_D2.5mm_P10.16mm_Horizontal
U1: AMS1117; SOT-223-3_TabPin2

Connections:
+3V3: C2.1, R1.1, U1.2 (VO); also elsewhere on the board
+5V: C1.1, J1.1, U1.3 (VI); also elsewhere on the board
GND: C1.2, C2.2, D1.1, J1.5, U1.1 (ADJ); also elsewhere on the board
unnamed: D1.2, R1.2

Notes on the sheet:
Regulacion de Tension de entrada

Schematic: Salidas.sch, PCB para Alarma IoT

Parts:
D2: 1N4003; D_A-405_P10.16mm_Horizontal
D3, D4: LED; LED_D3.0mm
J4: Bornera; TerminalBlock_bornier-2_P5.08mm
K1: Relay; Relay_SPDT_Omron-G5LE-1
Q1: BC337; TO-92_Inline
R2, R4: 180; R_Axial_DIN0207_L6.3mm_D2.5mm_P10.16mm_Horizontal
R5: 330; R_Axial_DIN0207_L6.3mm_D2.5mm_P10.16mm_Horizontal

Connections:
+5V: D2.1 (K), K1.5; also elsewhere on the board
/Salidas/LedControl: R4.2; also elsewhere on the board
/Salidas/LedStatus: R2.2; also elsewhere on the board
/Salidas/RelayIN: R5.1; also elsewhere on the board
GND: D3.1, D4.1, Q1.3 (E); also elsewhere on the board
unnamed: D2.2 (A), K1.1, Q1.1 (C)
unnamed: D3.2, R2.1
unnamed: D4.2, R4.1
unnamed: J4.1, K1.2
unnamed: J4.2, K1.3
unnamed: Q1.2 (B), R5.2

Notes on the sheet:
Salida de potencia
Salidas de control



Board: 2 copper layers, 50.0 x 50.0 mm, 25 parts (6 on the bottom side), 18 nets.

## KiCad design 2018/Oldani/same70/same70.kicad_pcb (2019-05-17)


Board: 2 copper layers, 62.5 x 87.5 mm, 71 parts (1 on the bottom side), 69 nets.

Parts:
C1, C3, C4, C5, C6, C7, C8, C10, C12, C14, C15, C18, C20, C21, C22, C28: 100nF; C_0805_2012Metric_Pad1.15x1.40mm_HandSolder
C2, C13: C; C_0805_2012Metric_Pad1.15x1.40mm_HandSolder
C9: 100uF; CP_Elec_4x5.3
C19, C23, C30, C31: 1uF; C_0805_2012Metric_Pad1.15x1.40mm_HandSolder
C24, C27, C29: 10nF; C_0805_2012Metric_Pad1.15x1.40mm_HandSolder
C25, C26: 10pF; C_0805_2012Metric_Pad1.15x1.40mm_HandSolder
C32, C33: 12pF; C_0805_2012Metric_Pad1.15x1.40mm_HandSolder
D1: D_TVS; D_0805_2012Metric_Castellated
D2: B240; D_SMB
D3: NUP2105L; SOT-23
D4, D5: D_Schottky_x2_Serial_ACK; SOT-23
J2, J6: Conn_02x05_Odd_Even; PinHeader_2x05_P2.54mm_Vertical
J3: Conn_02x06_Odd_Even; PinSocket_2x06_P2.54mm_Vertical
J4: Conn_01x05_Male; PinHeader_1x05_P2.54mm_Vertical
J5, J7: Conn_01x02_Male; PinHeader_1x02_P2.54mm_Vertical
J8: MAX11270; TSSOP-24_4.4x7.8mm_P0.65mm
J9: CeldaCarga; PinHeader_1x05_P2.54mm_Vertical
JP1, JP2, JP3, JP4: SolderJumper_2_Bridged; SolderJumper-2_P1.3mm_Bridged_RoundedPad1.0x1.5mm
L1, L2, L3, L4, L5, L7, L8: L; L_0805_2012Metric_Pad1.15x1.40mm_HandSolder
L6: MMZ1608B601C; L_0805_2012Metric_Pad1.15x1.40mm_HandSolder
R1: 1k8; R_0805_2012Metric_Pad1.15x1.40mm_HandSolder
R2: 3k3; R_0805_2012Metric_Pad1.15x1.40mm_HandSolder
R3, R7, R10, R11: 10k; R_0805_2012Metric_Pad1.15x1.40mm_HandSolder
R4: 120; R_0805_2012Metric_Pad1.15x1.40mm_HandSolder
R5: 1k; R_0805_2012Metric_Pad1.15x1.40mm_HandSolder
R6: 330; R_0805_2012Metric_Pad1.15x1.40mm_HandSolder
R8, R9: 100; R_0805_2012Metric_Pad1.15x1.40mm_HandSolder
U1: SN65HVD230; SOIC-8_3.9x4.9mm_P1.27mm
U3: LM317_3PinPackage; SOT-223
U4: 24LC1025; SOIJ-8_5.3x5.3mm_P1.27mm
U5: ATSAME70N21A-AN; LQFP-100_14x14mm_P0.5mm
Y1: Crystal; Crystal_HC18-U_Vertical

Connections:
35: J8.23, U5.35
40: J8.4, U5.40
41: J8.24, U5.41
42: J8.5, U5.42
43: J8.1, U5.43
44: J8.18, U5.44
45: J8.2, U5.45
46: J2.3, U5.46
47: J2.6, U5.47
48: J2.5, U5.48
49: J2.7, U5.49
50: J2.8, U5.50
51: J2.9, U5.51
52: J2.10, U5.52
53: J2.2, U5.53
54: J2.4, U5.54
55: R11.2, U4.6, U5.55
56: J2.1, U5.56
57: J6.5, U5.57
58: J6.6, U5.58
63: J6.1, U5.63
64: R10.2, U4.5, U5.64
69: J3.2, U5.69
70: J3.1, U5.70
71: J3.4, U5.71
72: J3.3, U5.72
74: J6.9, U5.74
75: J3.10, U5.75
78: J3.8, U5.78
79: J3.5, U5.79
80: J3.6, U5.80
87: J6.3, U5.87
94: J4.4, U5.94
95: J4.3, U5.95
96: C8.1, L5.2, U5.96
98: C33.2, U5.98, Y1.2
99: C32.2, U5.99, Y1.1
+3.3VADC: C23.1, C27.1, D4.3, D5.3, J8.9, J8.14, L6.2
+3V3: C6.1, C7.1, C9.1, C10.1, C12.1, C14.2, C15.1, C28.2, C31.1, J6.4, J8.22, L4.1, L6.1, R7.1, R10.1, R11.1, U1.3, U4.8, U5.5, U5.19, U5.28, U5.68, U5.81, U5.93
+5V: C19.1, J3.11, L1.1, L7.1, R6.1, U3.2
/ANN: C24.1, D5.2, J8.11, R9.2
/ANP: C24.2, D4.2, J8.12, R8.2
CAN_CONF: JP2.1, U5.16
CAN_RX0: U1.4, U5.20
CAN_TX0: U1.1, U5.17
GND: C1.2, C2.2, C3.2, C4.2, C5.2, C6.2, C7.2, C8.2, C9.2, C10.2, C12.2, C13.2, C14.1, C15.2, C18.2, C19.2, C20.2, C21.2, C22.2, C28.1, C30.2, C31.2, C32.1, C33.1, D1.2, D3.3, J3.12, J5.1, J6.2, J6.10, J8.3, J8.19, J8.20, J9.5, JP4.1, L2.1, L8.1, R2.2, R3.2, R5.2, U1.2, U4.1, U4.2, U4.4, U4.7, U5.3, U5.6, U5.7, U5.8, U5.10, U5.29, U5.67
GNDA: C23.2, C25.2, C26.2, C27.2, D4.1, D5.1, J8.10, J8.13, J8.17, L8.2
unnamed: C4.1, J4.5, L1.2
unnamed: C13.1, D2.1, U3.3
unnamed: C25.1, J9.2, R8.1
unnamed: C26.1, J9.4, R9.1
unnamed: C29.1, J8.15
unnamed: C29.2, J8.16
unnamed: C30.1, J8.21
unnamed: D1.1, D2.2, J5.2
unnamed: D3.1, J7.2, R4.1, U1.7
unnamed: D3.2, J7.1, JP3.2, U1.6
unnamed: J3.9, JP1.2, R1.1
unnamed: J4.2, L2.2
unnamed: J9.1, L7.2
unnamed: JP2.2, R3.1, U1.8
unnamed: JP3.1, R4.2
unnamed: JP4.2, R7.2, U4.3
unnamed: R5.1, R6.2, U3.1
RXD0: JP1.1, R1.2, R2.1, U5.12
TXD0: J3.7, U5.11
VDDOUT: C1.1, C5.1, C18.1, C20.1, C21.1, C22.1, L3.1, L5.1, U5.4, U5.18, U5.22, U5.39, U5.76
VDDPLL: C3.1, L3.2, U5.86
VREFP: C2.1, L4.2, U5.9

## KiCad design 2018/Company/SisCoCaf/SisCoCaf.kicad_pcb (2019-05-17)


Board: 2 copper layers, 100.0 x 50.0 mm, 31 parts (0 on the bottom side), 26 nets.

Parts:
BT1: Battery_Cell; BatteryHolder_Keystone_103_1x20mm
BZ1: Buzzer; Buzzer_12x9.5RM7.6
C1: 100uf; CP_Radial_D4.0mm_P2.00mm
C2: 220uf; CP_Radial_D4.0mm_P2.00mm
D1: LED; LED_D3.0mm
IC1: LPC111X_102; DIP-28_W15.24mm_Socket
J1: Entrada; JST_XH_B02B-XH-A_1x02_P2.50mm_Vertical
J2, J3: Conn_01x03_Male; JST_XH_B03B-XH-A_1x03_P2.50mm_Vertical
J4: Conn_01x02_Male; JST_XH_B02B-XH-A_1x02_P2.50mm_Vertical
J5: Conn_01x02_Female; PinSocket_1x02_P2.54mm_Vertical
J6: Conn_01x01_Male; PinHeader_1x01_P2.54mm_Vertical
JP1: Jumper; PinHeader_1x02_P2.54mm_Vertical
MH1, MH2, MH3, MH4: MountingHole; MountingHole_2.2mm_M2
Q1, Q2: BC547; TO-92_HandSolder
R1, R6: 1k; R_Axial_DIN0204_L3.6mm_D1.6mm_P7.62mm_Horizontal
R2, R3, R8, R9, R10: 220; R_Axial_DIN0204_L3.6mm_D1.6mm_P7.62mm_Horizontal
R4, R5: 4k7; R_Axial_DIN0204_L3.6mm_D1.6mm_P7.62mm_Horizontal
R7: 5k6; R_Axial_DIN0204_L3.6mm_D1.6mm_P7.62mm_Horizontal
U1: LM317_TO39; TO-220-3_Vertical
U2: NRF24L01_Breakout; nRF24L01_Breakout_antena

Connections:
+12V: C1.1, J1.1, U1.3
/BUZZER: IC1.28, R8.2
/EntradaD1: IC1.18, R2.2
/EntradaD2: IC1.17, R3.2
/LED: D1.2, IC1.14
/RX: IC1.15, J5.1
/SalidaD1: IC1.25, R9.2
/Sensor1: IC1.27, J2.2, R4.1
/Sensor2: IC1.26, J3.2, R5.1
/TX: IC1.16, J5.2
GND: BT1.2, C1.2, C2.2, IC1.8, IC1.22, J1.2, J2.3, J3.3, Q1.3, Q2.3, R1.2, R10.2, U2.1
unnamed: BT1.1, JP1.1
unnamed: BZ1.2, Q1.1
unnamed: D1.1, R10.1
unnamed: IC1.1, U2.7
unnamed: IC1.2, U2.6
unnamed: IC1.4, U2.4
unnamed: IC1.5, R7.2, U2.3
unnamed: IC1.6, U2.5
unnamed: J4.1, R2.1
unnamed: J4.2, R3.1
unnamed: J6.1, Q2.1
unnamed: Q1.2, R8.1
unnamed: Q2.2, R9.1
unnamed: R1.1, R6.2, U1.1
VDD: BZ1.1, C2.1, IC1.21, J2.1, J3.1, JP1.2, R4.2, R5.2, R6.1, R7.1, U1.2, U2.2

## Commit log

2016-07-12 Proyecto Aislacion USB - Primer esquematico
    [BOM del Circuito Modelo 1.xls, USBCableIsolatorCircuit.sch]
2016-07-13 Aislacion USB - Datos componentes en el SCH
    [USBCableIsolatorCircuit.sch]
2016-07-18 Se agrego una hoja jerarquica para el ADUM4160 - Se completaron los campos de los componentes
    [ADUM4160.sch, USBCableIsolatorCircuit.sch]
2016-07-19 Se asociaron los footprints
    [ADUM4160.sch, USBCableIsolatorCircuit.sch]
2016-07-20 Se agrego el documento con la revision del SCH
2016-07-20 Rev01 – Se incorporaron las observaciones realizadas en la primera revisión del esquemático - doc:
    [ADUM4160.sch, USBCableIsolatorCircuit.sch]
2016-07-20 Datos fabricante
    [ADUM4160.sch, BOM del Circuito Modelo 1.xls, USBCableIsolatorCircuit.sch]
2016-07-21 Primer ruteo - Se eliminaron los agujeros
    [ADUM4160.sch, USBCableIsolatorCircuit.kicad_pcb, USBCableIsolatorCircuit.sch]
2016-07-22 Leyendas en el PCB
    [ADUM4160.sch, USBCableIsolatorCircuit.kicad_pcb, USBCableIsolatorCircuit.sch]
2016-07-24 Se agregaron cambios sugeridos por el docente - DOC:Sugerencias Docente 20160724
    [ADUM4160.sch, Sugerencias Docente 20160724.ods, USBCableIsolatorCircuit.kicad_pcb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]
2016-07-25 Logo en el PCB - Datos del PCB
    [Sugerencias Docente 20160724.ods, USBCableIsolatorCircuit.kicad_pcb, USBCableIsolatorCircuit.sch]
2016-07-25 Se agregaron los cambios sugueridos en el doc Aislacion USB - Revision PCB 20160725
    [USBCableIsolatorCircuit-B.Cu.gbr, USBCableIsolatorCircuit-B.Mask.gbr, USBCableIsolatorCircuit-B.SilkS.gbr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]
2016-07-26 Detalles en la Serigrafia - Se agrego la licencia
    [ADUM4160.sch, Sugerencias Docente 20160724.ods, USBCableIsolatorCircuit.kicad_pcb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]
2016-07-26 Se desconectaron los agujeros del GND
    [ADUM4160.sch, USBCableIsolatorCircuit.sch]
2016-07-27 Agrego vista 3D del poncho Celda de carga.
2016-07-27 Agrego un script para reparar vistas 3D.
2016-07-27 Agrego 3d del Poncho detector de caídas.
2016-07-27 Actualizo el README.md.
2016-09-04 Agrego información del proyecto de Leon Vazquez.
2016-09-04 Agrego presentaciones del primer curso de diseño de PCBs para la CESE.
2016-12-20 Agrego vistas 3D de tres trabajos finales ya concluidos.
2016-12-29 Agrego imágenes de los PCBs del curso nro. 2
2016-12-29 Agrego los Ponchos del curso 2 de la CESE.
2016-12-30 Agregados todos los PCBS del curso 2 de 2016.
2016-12-30 Agrego imágenes de los proyectos inconclusos.
2017-08-21 Agrego imagenes de Ponchos CESE 2017
2017-08-21 Agregado parcial de diseños 2017.
2017-08-21 Agregado parcial de diseños 2017. Tanda 2
2017-08-22 Fin de carga de proyectos 2017.
2019-05-17 Agrego archivos del curso DCI CESE 2018.
    [10118193-0001LF--3DModel-STEP-56544.STEP, ADS1292_esquematico-2018-08-04-11-07-02.sch, ADS1292_esquematico.sch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]
2019-05-28 Cambio el README.md y los separo por años. También agrego TOC a los archivos.
2019-05-28 Agrego notas para generar TOCs.
2019-11-25 Agrego segundo curso de 2019
2021-03-04 Agrego TOC para el curso 2020A.
2021-03-11 Error en el nombre de un proyecto.

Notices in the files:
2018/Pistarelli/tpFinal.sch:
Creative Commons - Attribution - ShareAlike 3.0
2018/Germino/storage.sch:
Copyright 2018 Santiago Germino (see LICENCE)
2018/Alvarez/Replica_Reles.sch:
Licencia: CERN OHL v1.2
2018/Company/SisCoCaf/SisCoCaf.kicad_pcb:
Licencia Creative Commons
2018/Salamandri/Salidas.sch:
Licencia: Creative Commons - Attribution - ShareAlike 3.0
